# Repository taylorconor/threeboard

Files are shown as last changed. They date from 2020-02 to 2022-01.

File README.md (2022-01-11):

# threeboard

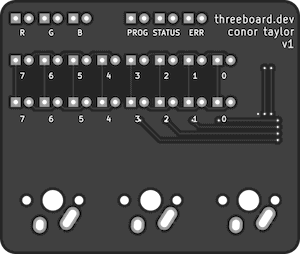
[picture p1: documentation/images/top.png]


threeboard is a fully-functional open source and open hardware mechanical USB computer keyboard with only three keys. It supports multiple programmable layers, and achieves the same functionality as a full-sized keyboard. Its firmware and hardware are built completely from scratch and are extensively documented.

Unlike a traditional keyboard, characters don't show up on the screen after each keypress, because there aren't enough keys. Instead, combinations of the three keys are used to specify key and modifier codes on two built-in 8-bit LED binary indicators. This can then be sent to the host computer as USB keycodes. The multiple layers allow users to program macros into the threeboard’s storage for quick retrieval. All functionality is documented in the [threeboard user manual](documentation/threeboard/threeboard_user_manual.md).

## Motivation
The main goal of the threeboard project is to build a relatively easy to understand, readable, self-contained and well-documented embedded software and hardware project. The threeboard is built from scratch, with no external dependencies. This means that all components, from the USB stack to the PCB hardware designs, are written from the ground up and are all contained in this repository.

The threeboard project is extensively documented: within the firmware itself as comments, in this set of detailed markdown documents, and in a [PDF design document](documentation/threeboard_design_doc.pdf). The primary design goal of the C++ firmware code is readability, to enable as many people to read and learn from it as possible, regardless of background. It's well tested, including end-to-end integration tests which execute tests against the firmware in a hardware simulator to emulate the physical hardware.

## How to try it out

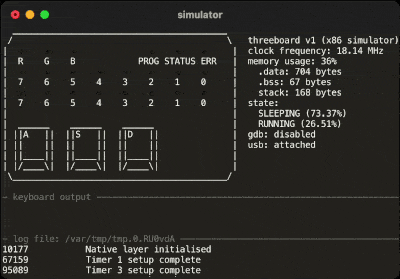
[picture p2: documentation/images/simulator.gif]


The threeboard project includes a terminal-based graphical firmware simulator capable of simulating the entire functionality of the threeboard. You can build and run the simulator yourself by reading the [simulator build instructions](documentation/threeboard/simulator_build_instructions.md). The simulator is built on top of the [simavr](https://github.com/buserror/simavr) AVR simulator, and runs the exact same firmware file that gets flashed to physical hardware. The simulator also allows remote debugging with GDB, so you can step through the threeboard firmware as it's being simulated to learn about it or investigate bugs!

Building your own physical threeboard requires a physical threeboard PCB, soldering tools and components, as well as some knowledge of electronics and soldering. If you're interested in building one, check out the [threeboard hardware build instructions](documentation/threeboard/hardware_build_instructions.md).

## Full documentation
Below are markdown files documenting various aspects of the threeboard project in detail. Full 41-page documentation is available in PDF format in the [threeboard design doc](documentation/threeboard_design_doc.pdf) file.

### Background reading 
[threeboard user manual](documentation/threeboard/threeboard_user_manual.md)  
[How do USB keyboards work?](documentation/threeboard/how_usb_keyboards_work.md) 

### Firmware
[Firmware design](documentation/threeboard/firmware_design.md)  
[Firmware build instructions](documentation/threeboard/firmware_build_instructions.md)  
[Simulator user manual & design](documentation/threeboard/simulator_manual_and_design.md)  
[Simulator build instructions](documentation/threeboard/simulator_build_instructions.md)  

### Hardware
[Hardware design](documentation/threeboard/hardware_design.md)  
[Hardware build instructions](documentation/threeboard/hardware_build_instructions.md)  
[Component list](documentation/threeboard/component_list.md)

Hardware designs are licensed under [CERN-OHL-P](hardware/LICENSE.txt), the firmware is licensed under [GPLv3](firmware/LICENSE.txt), and all documentation under [CC BY-SA 4.0](documentation/threeboard/LICENSE.txt).

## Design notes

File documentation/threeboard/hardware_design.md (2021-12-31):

# threeboard hardware design
## Introduction
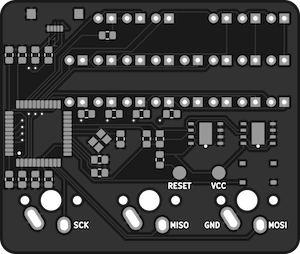
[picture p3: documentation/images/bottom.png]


The threeboard’s hardware is a custom-designed PCB. It includes all electrical components needed to operate the threeboard, as well as test points that can be used to flash new firmware to the MCU. The majority of the components used are surface mounted, with through-holes used for some of the larger components.

This section of the document describes the design goals of the threeboard hardware, the choice of components, and electrical design decisions.

## Hardware design goals
Similar to the design principles of the firmware, the threeboard’s hardware was designed with several goals in mind:

1. Simplicity: This implies that nothing should exist on the PCB that isn’t completely necessary for the operation of the threeboard, and any hardware that can be offloaded to the MCU’s hardware (such as making use of the internal pull-up resistors on certain pins) should be. More importantly, simplicity also applies to the hardware design patterns used; it should be possible to learn from the hardware design of the threeboard with little or no electrical engineering experience.
2. Hand-solderable: It should be possible to solder all components onto the threeboard by hand, with only basic soldering experience. This improves the accessibility of the hardware so it can be easily assembled. For example, all resistor and capacitor pads use an SMD [0805 package size](https://eepower.com/resistor-guide/resistor-standards-and-codes/resistor-sizes-and-packages). Also, the atmega32u4 MCU used by the threeboard is the 10x10mm [TQFP](https://en.wikipedia.org/wiki/Quad_flat_package) package, despite the MCU being offered in a smaller 7x7mm [QFN](https://en.wikipedia.org/wiki/Flat_no-leads_package) package, as it would be more difficult to solder.
3. Inexpensive to manufacture: No unnecessarily expensive components should be used, and no PCB features should be included that are difficult (and expensive) to manufacture unless absolutely necessary. For this reason, the threeboard PCB only uses two layers, minimal [through-hole components](https://en.wikipedia.org/wiki/Through-hole_technology), and as few [via holes](https://en.wikipedia.org/wiki/Via_(electronics)) as possible.

## Design
This section is split into subsections that explain the design of each major hardware component. In many cases, images of the threeboard’s PCB and electrical schematic are used to aid the explanation. In these cases, the image of the relevant piece of the PCB will always be on the left, and the relevant part of the schematic on the right.

### USB


<br clear="right"/>
<br clear="left"/>

The threeboard’s USB hardware is very simple because the atmega32u4 has dedicated USB pins that map directly to the USB connector (pictured in red). The only additional hardware required is specified by the atmega32u4 datasheet, sections 2.2.8 and 2.2.9, which states that the D+ and D- USB data upstream ports should be connected to the USB data connector pins via serial 22Ω resistors (pictured in blue and green).

The complexity of the USB integration lies in the firmware. It’s responsible for keeping track of bus timing, issuing interrupts, and parsing and sending messages. This is discussed in detail in the [firmware design document](firmware_design.md).

### LEDs
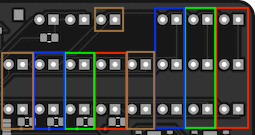
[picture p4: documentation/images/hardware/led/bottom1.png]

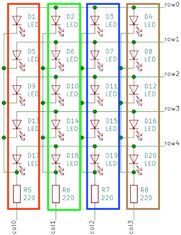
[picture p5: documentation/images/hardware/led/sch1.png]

<br clear="right"/>
<br clear="left"/>

In order to be able to drive 22 LEDs using only 11 MCU pins, the majority of the threeboard’s LEDs are wired in a [multiplexed matrix](https://en.wikipedia.org/wiki/Multiplexed_display), where each individual LED in the matrix is addressable by a row and column value. In this configuration, all of the LEDs can’t be lit at the same time. Instead, each row of LEDs is scanned over in a [raster scanning](https://en.wikipedia.org/wiki/Raster_scan) fashion, and individual LEDs that should be lit are turned on until the next raster scan turns them off.

This row scanning happens within the firmware and is triggered every 2ms by timer interrupt 1. Given that there are 5 rows, a full refresh takes 10ms, which gives the threeboard’s LED indicators a refresh rate of 100Hz, which is well above the threshold for [perceivable flicker by the human eye](https://en.wikipedia.org/wiki/Flicker_fusion_threshold).

Only one LED from a column is lit at any one time, since only one LED from each column exists in a given row. Each column of LEDs is protected by one 220Ω current-limiting resistor in series to restrict the current to each LED to 22mA (calculated using [Ohm’s law](https://en.wikipedia.org/wiki/Ohm%27s_law) given the 5V input voltage from USB).

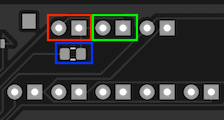
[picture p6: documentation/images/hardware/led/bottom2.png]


<br clear="right"/>
<br clear="left"/>

There are two LEDs on the threeboard that are not included in the multiplexed LED matrix. These are the STATUS (shown in green) and ERR (shown in red) LEDs. They’re configured in parallel with their polarities inverted so that only one can be lit at any given time, and so that only one resistor and two MCU pins are required to drive them. These LEDs are configured in this way for two reasons:

1. 22 LEDs are hard to arrange in a row-column matrix since the number 22 has very few factors. The only configurations would be a 1x22 matrix (which isn’t a matrix) or a 2x11 matrix (which doesn’t reduce the use of LEDs or pins very much). So it’s more economical to put 20 LEDs in a 5x4 matrix and the remaining two in a standalone pair.
2. It’s beneficial when reporting errors or debugging issues with the firmware on the physical board (rather than the simulator) to have some LEDs which can be decoupled from the raster scanning loop. This means that if there are firmware issues with the loop logic, or issues with the MCU’s timer configuration, the STATUS or ERR LEDs can be lit independently of the matrix to help with debugging or surfacing errors.

### Mechanical key switches

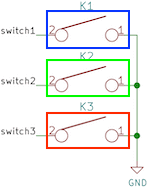
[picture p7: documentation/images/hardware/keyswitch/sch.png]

<br clear="right"/>
<br clear="left"/>

The threeboard uses [Cherry MX](https://deskthority.net/wiki/Cherry_MX) SPST-NO ([single pole, single throw, normally open](https://en.wikipedia.org/wiki/Switch#Contact_terminology)) mechanical switches for its physical key switches. The [bounce time](https://en.wikipedia.org/wiki/Switch#Contact_bounce) of these switches differs depending on the type of switch and the date of manufacture, but it’s safe to assume that it will be below 5ms. Most modern Cherry MX key switches have a 1ms bounce time.

These switches are wired directly to ground, which means they are configured to be [active low](https://en.wikipedia.org/wiki/Logic_level#Active_state); when pressed, they connect their MCU pin to ground. To avoid the situation where an unpressed switch leaves its corresponding MCU pin floating, each switch defaults to high using a [pull-up resistor](https://en.wikipedia.org/wiki/Pull-up_resistor). The atmega32u4 includes internal pull-up resistors on a number of its pin ports, so all three switches are wired to pins on PORTB which includes internal pull-up resistors as specified by the atmega32u4 datasheet, section 2.2.3, with typical resistances of 20-50kΩ.

The MCU pins used for the key switches were chosen carefully to correspond to the pins used for SCK (shown in red), MISO (shown in green), and MOSI (shown in blue) of the atmega32u4’s [SPI interface](https://en.wikipedia.org/wiki/Serial_Peripheral_Interface). These pins are necessary when flashing new firmware onto the MCU using SPI, and so wiring them to the legs of the key switches removes the need for adding dedicated testing pads to connect these pins to an SPI programmer during flashing.

### External EEPROMs
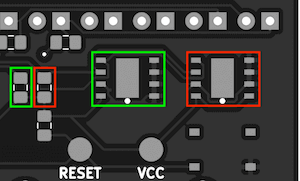
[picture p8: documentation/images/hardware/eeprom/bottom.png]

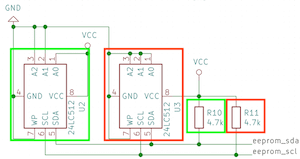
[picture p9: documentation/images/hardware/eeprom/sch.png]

<br clear="right"/>
<br clear="left"/>

The threeboard contains two external 512 kbit EEPROM devices. These devices communicate with the MCU using its 2-wire serial interface (the [I2C protocol](https://en.wikipedia.org/wiki/I%C2%B2C)). The atmega32u4 MCU has built-in hardware support for this interface, with a dedicated data pin (SDA) and clock pin (SCL), which collectively form the TWI (two-wire interface) bus. This interface is described in detail in the atmega32u4 datasheet, section 20.

The EEPROM devices can both be connected in parallel to these pins, as the I2C protocol uses 7-bit addresses, allowing for up to 128 devices on the same bus. Two 4.7kΩ pull-up resistors are used to pull each bus line high when not driven low by the [open-drain](https://en.wikipedia.org/wiki/Open_collector) interface, as mentioned in the atmega32u4 datasheet, section 20.2: _The only external hardware needed to implement the bus is a single pull-up resistor for each of the TWI bus lines_.

### External quartz crystal clock
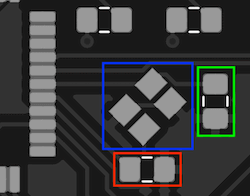
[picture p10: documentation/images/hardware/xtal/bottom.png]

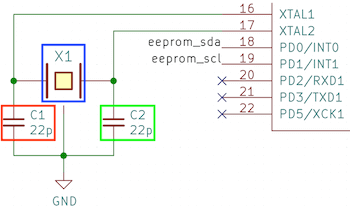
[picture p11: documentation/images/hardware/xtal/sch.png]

<br clear="right"/>
<br clear="left"/>

The threeboard includes a 16MHz quartz crystal oscillator (shown above in blue) as a clock source to the MCU. The MCU contains dedicated hardware pins for use with the external clock (XTAL1 and XTAL2), and the atmega32u4 datasheet, section 6.3, recommends the crystal to be wired as shown in the diagram above, with external capacitors within a 12pF - 22pF range (shown in red and green).

### Decoupling capacitors
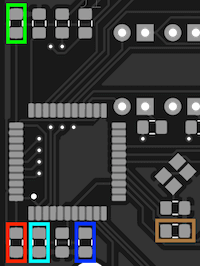
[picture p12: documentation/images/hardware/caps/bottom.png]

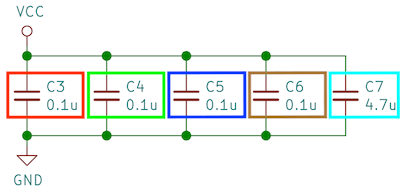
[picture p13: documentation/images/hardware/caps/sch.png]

<br clear="right"/>
<br clear="left"/>

[Decoupling capacitors](https://en.wikipedia.org/wiki/Decoupling_capacitor) are positioned close to each VCC-connected pin on the MCU, to reduce the effect of voltage spikes and drops from the USB power supply. They are also necessary to facilitate instantaneous current increases that may be required by the MCU, as various actions performed by the MCU may have different current requirements.

### MCU
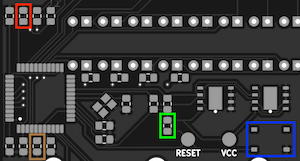
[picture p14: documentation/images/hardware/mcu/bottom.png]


<br clear="right"/>
<br clear="left"/>

The threeboard includes a reset push button to help flash firmware to the MCU during development. The reset switch (shown above in blue) is connected to the RESET pin in the MCU, pulled up to VCC with a 10kΩ pull-up resistor (shown in green). Additionally, the HWB pin is forced low to instruct the MCU to execute the USB bootloader on reset, which allows flashing new firmware on reset. To force it low, it’s tied to ground using a 10kΩ pull-down resistor (shown in red) to prevent the pin from floating.

As specified in the atmega32u4 datasheet, section 2.2.12, the UCap pin must be connected to a 1μF capacitor to regulate the USB output supply voltage.

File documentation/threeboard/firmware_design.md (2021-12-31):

# threeboard firmware design

## Introduction
The threeboard’s firmware has two main functions. The first is to configure and interface with each hardware component on the threeboard (such as LEDs, EEPROMs and USB) according to their respective specifications. The second is to provide user-facing features and functionality to the threeboard as described in the [threeboard user manual](threeboard_user_manual.md).

## Constraints
The threeboard uses an [atmega32u4](https://www.microchip.com/wwwproducts/en/ATmega32u4) microcontroller (MCU), a low-power 8-bit [microcontroller](https://en.wikipedia.org/wiki/Microcontroller) based on the [AVR](https://en.wikipedia.org/wiki/AVR_microcontrollers) enhanced [RISC architecture](https://en.wikipedia.org/wiki/Reduced_instruction_set_computer). Firmware code compiled for this MCU uses the [Atmel AVR instruction set](https://en.wikipedia.org/wiki/Atmel_AVR_instruction_set).

The MCU itself has the following relevant features:

- 8-bit AVR architecture.
- 16MHz maximum frequency at 4.5V.
- 32KB flash-based program memory.
- 2.5KB SRAM.
- 1KB internal EEPROM.
- USB controller hardware support.
- Two 8-bit and two 16-bit timers.
- Byte oriented 2-wire serial interface.

Due to these MCU constraints, this is a bare-metal firmware project. This means that the firmware’s instructions are executed directly on the MCU hardware, without an intervening operating system.

As a result of the lack of operating system, [hardware MMU](https://en.wikipedia.org/wiki/Memory_management_unit), and the severely restricted RAM size, the firmware does not perform any dynamic memory allocation (i.e. no heap allocation). All memory allocation is stack-based.

It’s important to mention that there is no official C++ standard library support for AVR targets. Therefore targets compiled with the AVR C++ compiler, [avr-gcc](https://gcc.gnu.org/wiki/avr-gcc), will not link against libstdc++. All firmware code in the threeboard project cannot use any C++ standard library functions or headers.

## Design principles
The threeboard firmware was designed with several core principles in mind. These are listed below, along with the reasoning for their inclusion:

1. Readability: This is the primary design principle of the firmware. The C++ source itself should be clear, consistent, and well documented. It should be possible for anyone with passable C/C++ knowledge and no embedded programming knowledge to read it and learn from it.
  - Reasoning: Source code with consistent style reduces unnecessary mental load when reading the code, as the code style is predictable. As many people as possible should be able to read and learn from this project, regardless of engineering background. Reducing readability friction helps achieve this goal.
2. Modularity: There should be a clear separation of concerns between different modules of the code, and no interdependence. Modules that need to affect change on other modules should do so via delegation.
  - Reasoning: It’s hard to determine if a class fulfils its responsibilities if it has multiple distinct responsibilities, and it’s hard to guarantee separation of concerns when this mix of responsibilities inevitably leads to reduced encapsulation. Reduced encapsulation causes [dependency hell](https://en.wikipedia.org/wiki/Dependency_hell), which makes code hard to maintain and greatly reduces readability by making the control flow difficult to follow.
3. Testability: Each module must be testable in isolation. All external module dependencies should be abstract to enable mocking and deterministic testing.
  - Reasoning: Untested code should be assumed to have bugs, so full test coverage is essential. Making classes easier to test in isolation makes it easier to write concise test cases.

## Toolchain
The atmega32u4 chip manufacturer (Atmel / Microchip) provides a [toolchain](https://en.wikipedia.org/wiki/Toolchain) for use with AVR development, in particular [avr-gcc](https://www.microchip.com/en-us/development-tools-tools-and-software/gcc-compilers-avr-and-arm), a GCC compiler for AVR. This toolchain works out of the box for all stages of firmware development.

The threeboard firmware is built with [Bazel](http://bazel.build/). Bazel was chosen over more traditional build systems like CMake because it has the following useful properties:

1. Explicit dependencies: All dependencies on a [translation unit](https://en.wikipedia.org/wiki/Translation_unit_(programming)) must be explicitly defined in the Bazel BUILD file, and each translation unit is compiled in a sandbox environment that only has access to the dependencies that have been explicitly declared. This makes it impossible to introduce implicit project dependencies. Additionally, Bazel fails the build if it detects a dependency cycle.
2. Customisable target declarations: Targets can be used to produce multiple object files, compiled with different compiler settings and even with different compilers. This allows compatible modules to be compiled for both x86 and AVR, depending on the context in which it’s being compiled.

Bazel has no pre-existing support for the AVR toolchain, so support had to be added for this project. The [avr-bazel](https://github.com/taylorconor/avr-bazel) repository was built especially for the threeboard project. It contains some special Bazel build rules to produce joint x86 and AVR build targets. This allows defining a single target definition per BUILD file to produce libraries for both targets, to avoid having to double-declare them.

## Architecture
### Overview
The architecture of the threeboard firmware can roughly be grouped into three categories of modules/classes:

1. Business logic modules: These codify the functionality of the firmware, and coordinate other modules to execute this functionality.
2. Native-interacting modules: Generally serve the purpose of configuring and controlling a single hardware element, such as LEDs or USB.
3. Pure AVR modules: Modules that can only be compiled for the AVR architecture, i.e. those that interact directly with hardware.

<p align="center">
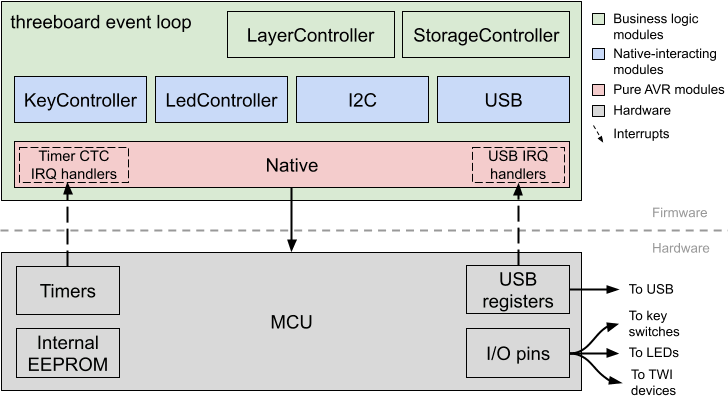
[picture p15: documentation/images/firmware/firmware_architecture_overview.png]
  
</p>

Everything except pure AVR modules target both AVR and x86 targets, which enables tests to run on x86 development hosts. These modules don’t depend on any avr-libc headers, so all of their interactions with hardware are proxied through the firmware’s `Native` interface, which exposes an API to interact with hardware. The interface itself does not depend on avr-libc, so non-pure modules can depend on it. When the firmware is compiled to be run on an AVR host or simulator, an avr-libc dependent `Native` implementation (`NativeImpl`) is used.

### Event loop
The core of the threeboard firmware is a simple event loop; a design pattern that waits for and dispatches events to relevant modules when they arrive. The event loop is a never-ending loop that runs as long as the firmware is running (i.e. as long as the device has power).

The responsibilities of the different timers used, and the encapsulation afforded by the event loop is summarised in the diagram below:
<p align="center">
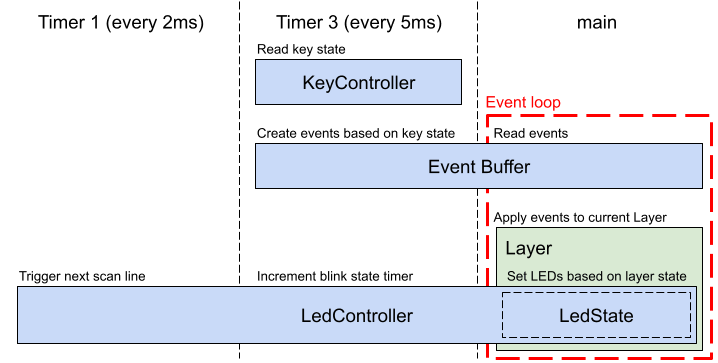
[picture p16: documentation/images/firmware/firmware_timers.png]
  
</p>

Each event loop iteration is triggered by an [interrupt](https://en.wikipedia.org/wiki/Interrupt). Two timer-based interrupts are used in the threeboard firmware: Timer 1 in CTC mode is configured to produce a software interrupt every 2ms, and is used to refresh the next LED scan line; Timer 3, also in CTC mode, is configured to produce a software interrupt every 5ms, used mainly to poll the key switches and produce events on the event buffer if necessary. Running timer 3 slower and separately from timer 1 allows us to avoid debouncing the [Cherry MX](https://en.wikipedia.org/wiki/Cherry_(company)#Cherry_MX_switches_in_consumer_keyboards) key switches in software.

The purpose of the event loop is to receive and process all keypress events according to the actions defined in the current `Layer` of the threeboard. Each `Layer` instance encapsulates all business logic relating to inputs and actions for a given layer, so this doesn’t need to happen in a long list of if/else statements within the main program loop.

```c++
void Threeboard::RunEventLoop() {
  // USB setup and configuration.
  ...

  // Main event loop.
  while (true) {
    // Atomically check for new keyboard events, and either handle them or
    // sleep the CPU until the next interrupt.
    native_->DisableInterrupts();
    if (!event_buffer_->HasEvent()) {
      // Sleep the CPU until another interrupt fires.
      native_->EnableCpuSleep();
      native_->EnableInterrupts();
      native_->SleepCpu();
      native_->DisableCpuSleep();
    } else {
      if (event_buffer_->HasKeypressEvent()) {
        layer_controller_.HandleEvent(event_buffer_->GetKeypressEvent());
      }
      // Re-enable interrupts after handling the event.
      native_->EnableInterrupts();
    }
  }
}
```

The sleep enabled bit is set before each sleep and cleared after each sleep, as recommended in the atmega32u4 datasheet (section 7.9.1): _it is recommended to write the Sleep Enable (SE) bit to one just before the execution of the SLEEP instruction and to clear it immediately after waking up_.

When finished handling events in the event buffer, the event loop puts the MCU into idle mode. In this mode, the CPU clock is stopped, but the clock powering the MCU’s timers continues. The MCU is brought out of idle mode when the timer produces a software interrupt. The purpose of the event loop can therefore be thought of as to efficiently facilitate delegation between each module in the threeboard, without requiring [busy-waiting](https://en.wikipedia.org/wiki/Busy_waiting).

### Delegation
The threeboard makes extensive use of [delegation](https://en.wikipedia.org/wiki/Delegation_pattern) to allow different modules in the firmware to communicate with each other without introducing circular dependencies.

In certain situations, two-way function calling between modules is necessary. The first of such situations this document will explain is the `LayerController`. It needs to be able to provide events to individual `Layer`s to be handled. But some of these events may trigger an action that affects the `LayerController` itself, such as a keypress event that triggers the threeboard to switch layers. In this case, the current `Layer` uses the `LayerControllerDelegate` to call `SwitchToLayer()` on the `LayerController`, without having to explicitly depend on the `LayerController`:
<p align="center">
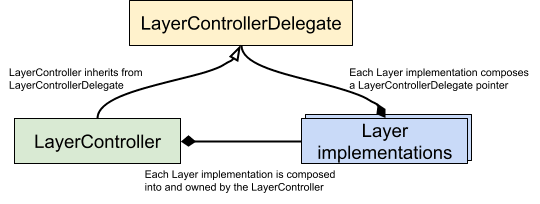
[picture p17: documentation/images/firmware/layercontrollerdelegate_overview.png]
  
</p>
<br>
<p align="center">
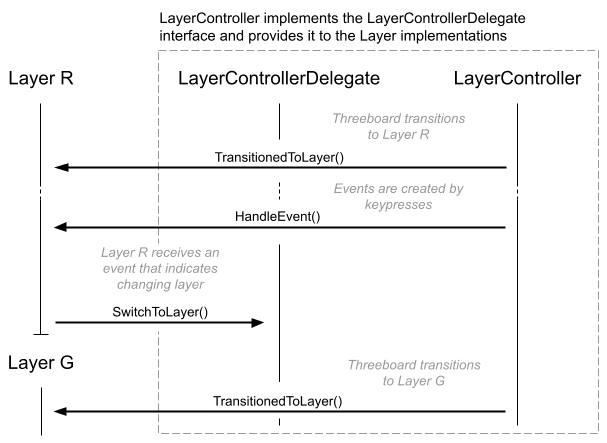
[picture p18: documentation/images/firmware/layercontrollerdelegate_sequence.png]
  
</p>

The `Threeboard` class event loop receives timer interrupts in a similar fashion to the `LayerController`. In this case, the `Native` implementation is not owned by the `Threeboard` class, instead it’s passed in as part of the bootstrapping process. This allows `Native`-specific timers to call functions in the `Threeboard` class (via the `TimerInterruptHandlerDelegate`) without introducing a circular dependency:
<p align="center">
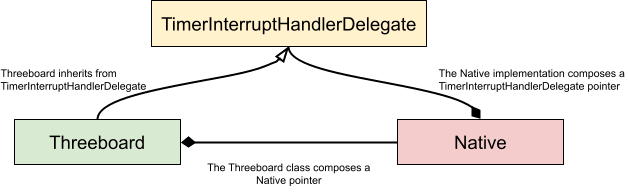
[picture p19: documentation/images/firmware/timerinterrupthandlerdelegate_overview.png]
  
</p>

### LED indicators
The LED indicators on the threeboard are vital to understanding the current state of the threeboard. The hardware is equipped with 22 single-colour LEDs. These are arranged as follows:
<p align="center">
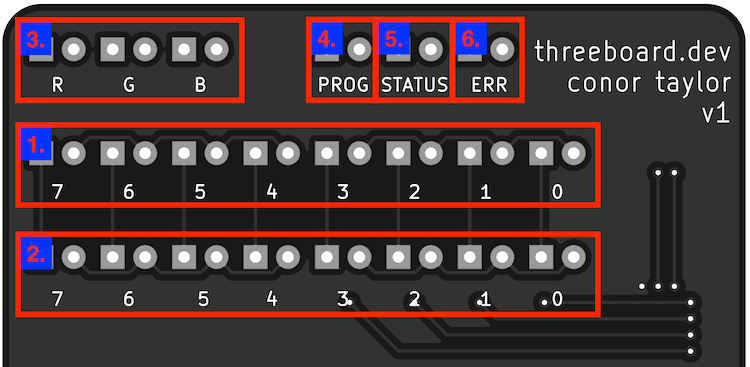
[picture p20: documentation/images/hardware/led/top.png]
  
</p>

1. 8 LEDs to display the binary value of bank_0 (1 byte).
2. 8 LEDs to display the binary value of bank_1 (1 byte).
3. 3 LEDs to display the current layer, which is one of R, G or B (or DFLT if no LEDs are lit).
4. 1 PROG LED to identify when the device is in PROG mode.
5. 1 ERR LED to indicate an error.
6. 1 STATUS LED to provide context-specific status information.

The hardware-specific details of these LEDs, such as their wiring and tolerance, is described in the [hardware design](hardware_design.md) document.

The LED indicator lights are all controlled by the `LedController`. This class is responsible for maintaining the state of the raster scan and outputting the `LedState` (a simple class for storing the state of each LED) to hardware. Its interface is very simple:

```c++
class LedController {
 public:
  explicit LedController(native::Native *native);

  // Handles rendering of the next scan row. Called by the timer interrupt
  // handler every 2ms.
  void ScanNextLine();

  // Handles timing of LED blinking. Called by the timer interrupt handler every
  // 5ms.
  void UpdateBlinkStatus();

  // state_ is guaranteed to live for the entire lifetime of the firmware.
  LedState *GetLedState() { return &state_; }
};
```

As discussed in the hardware section, the LEDs on the threeboard are arranged in a 5 row, 4 column matrix. When the `ScanNextLine()` function is called, the active LEDs in the next row of the matrix are lit, and all other LEDs are turned off. `ScanNextLine()` is called every 2ms by timer 1, which provides a 100Hz refresh rate on the threeboard’s LEDs.

The `LedController` is also responsible for maintaining the timing of blinking LEDs. `UpdateBlinkStatus()` increments an 8-bit blink timer. Two blink states are supported by the threeboard: `LedState::BLINK` repeatedly flashes the selected LED, and `LedState::PULSE` flashes the LED once and then reverts to `LedState::OFF`.

### USB stack
The threeboard contains a full USB device implementation. The threeboard presents itself to hosts as a [USB version 2.0](https://www.usb.org/document-library/usb-20-specification) keyboard [HID device](https://en.wikipedia.org/wiki/USB_human_interface_device_class), complies with HID [version 1.11](https://www.usb.org/document-library/device-class-definition-hid-111), and passes [USB CV test specification 0.72](https://www.usb.org/document-library/usb-31-command-verifier-compliance-test-specification-version-072).

The USB protocol is extremely complex and so is not explained in this document. To learn how USB works, I recommend the [USB in a NutShell](https://www.beyondlogic.org/usbnutshell/usb1.shtml) series of articles, and to use the [USB 2.0 specification](https://www.usb.org/document-library/usb-20-specification) as a reference. This section will summarise the design and architecture of the threeboard’s USB stack without going into any detail about the USB standard.

In the threeboard firmware, the USB stack is abstracted behind a minimal interface:

```c++
class Usb {
 public:
  // Setup the USB hardware to begin connection to the host. This method blocks
  // until the device hardware is correctly set up. If this method returns false
  // it means setup was halted by an error issued via the ErrorHandlerDelegate
  // and is in an undefined state.
  virtual bool Setup() = 0;

  // Returns true if the HID device configuration has completed successfully.
  virtual bool HasConfigured() = 0;

  // Send the provided key and modifier code to the host device. Returns false
  // if an error occurred during sending.
  virtual bool SendKeypress(uint8_t key, uint8_t mod) = 0;
};
```
The `UsbImpl` class is the concrete implementation of the `Usb` interface and interacts with the MCU’s USB registers and functionality using the `Native` interface. Failure to set up correctly via `Usb::Setup()`, and subsequent failure to configure within the first 50 USB frames (50ms) using `Usb::HasConfigured()` will stall the threeboard’s firmware startup logic, and enter an error state that continuously attempts to establish a connection to the host over USB.

USB setup begins with the firmware configuring the MCU to enable an electrical USB connection with the host device, as defined in the atmega32u4 datasheet, section 21.12. For example, the MCU contains [phase-locked loop (PLL)](https://en.wikipedia.org/wiki/Phase-locked_loop) hardware. When enabled, this can convert the external 16MHz clock signal to a 12MHz clock needed for the USB controller hardware in the MCU when configured in full-speed mode (atmega32u4 datasheet, section 21.2):

```c++
bool UsbImpl::Setup() {
  // Enable the USB pad regulator (which uses the external 1uF UCap).
  native_->SetUHWCON(1 << native::UVREGE);
  // Enable USB and freeze the clock.
  native_->SetUSBCON((1 << native::USBE) | (1 << native::FRZCLK));
  // PLL Control and Status Register. Configure the prescaler for the 16MHz
  // clock, and enable the PLL.
  native_->SetPLLCSR((1 << native::PINDIV) | (1 << native::PLLE));
  // Busy loop to wait for the PLL to lock to the 16MHz reference clock.
  WAIT_OR_RETURN(!(native_->GetPLLCSR() & (1 << native::PLOCK)), UINT16_MAX,
                 "Failed to lock PLL during USB setup");
  // Enable USB and the VBUS pad.
  native_->SetUSBCON((1 << native::USBE) | (1 << native::OTGPADE));
  // Configure USB general interrupts (handled by the USB_GEN_vect routine). We
  // want to interrupt on start of frame (SOFE), and also on end of reset
  // (EORSTE).
  native_->SetUDIEN((1 << native::EORSTE) | (1 << native::SOFE));
  // Connect internal pull-up attach resistor. This must be the final step in
  // the setup process because it indicates that the device is now ready.
  native_->SetUDCON(native_->GetUDCON() & ~(1 << native::DETACH));
  return true;
}
```

Once the device hardware is correctly set up, the threeboard informs the host of its capabilities using a series of [descriptors](https://www.beyondlogic.org/usbnutshell/usb5.shtml). The device descriptor specifies fundamental information about the device (including which USB standard it supports and its unique ID). Other important descriptors follow, which inform the host of the class of the device; in this case a [HID-compatible](https://en.wikipedia.org/wiki/USB_human_interface_device_class) keyboard device.

All USB communication is host-centric. This means that no data can be sent from the device to the host unless the host requests it. For this reason, the threeboard’s USB stack is interrupt-driven. The atmega32u4 provides hardware support to issue software interrupts identifying the beginning of a USB message frame, which is the USB host potentially requesting information from the device, such as keypress data or specific descriptor information, for example, to determine what strings to display as the name of the USB device on the host computer. The threeboard’s USB interrupts are facilitated by the `UsbInterruptHandlerDelegate`, which allows the Native layer to pass messages to the USB stack without dependency issues, as discussed in the [delegation](#delegation) section.

Once the USB stack has correctly configured, the threeboard’s firmware enters the [event loop](#event-loop). Individual layers can decide when to flush their state to the USB host (using `Layer::FlushToHost()`) based on their received keypress events. This triggers one or more `UsbImpl::SendKeypress()` calls, which attempts to send an individual key presses to the host over USB:

```c++
bool UsbImpl::SendKeypress() {
  uint8_t intr_state = native_->GetSREG();
  native_->DisableInterrupts();
  uint8_t initial_frame_num = native_->GetUDFNUML();
  while (true) {
    native_->SetUENUM(kKeyboardEndpoint);
    native_->EnableInterrupts();
    // Check if we're allowed to push data into the FIFO. If we are, we can
    // immediately break and begin transmitting.
    if (native_->GetUEINTX() & (1 << native::RWAL)) {
      break;
    }
    native_->SetSREG(intr_state);
    // Ensure the device is still configured.
    RETURN_IF_ERROR(hid_state_.configuration);
    // Only continue polling RWAL for 50 frames (50ms on our full-speed bus).
    if ((native_->GetUDFNUML() - initial_frame_num) >= kFrameTimeout) {
      return false;
    }
    intr_state = native_->GetSREG();
    native_->DisableInterrupts();
  }

  SendHidState();
  native_->SetSREG(intr_state);
  return true;
}
```

### Storage
The threeboard is equipped with three [EEPROM](https://en.wikipedia.org/wiki/EEPROM) storage devices: One 1 KB EEPROM built into the atmega32u4 MCU, and two 512 kbit external EEPROMs connected to the MCU via the MCU’s TWI (two-wire interface) bus. These communicate with the MCU using the [I2C protocol](https://en.wikipedia.org/wiki/I%C2%B2C).

In firmware, the data in these storage devices are all controlled on a high level by the `StorageController`, which is used by each of the programmable `Layer`s for their respective storage needs. The `StorageController` uses the I2C module to abstract away the interfacing logic between the MCU and relevant EEPROMs.

The internal 1 KB EEPROM is used to store all of the character shortcuts for Layer `R`, in addition to the lengths of each of the shortcuts stored in layers G and B. The first external EEPROM (referred to as EEPROM 0) stores each of the word shortcuts for Layer `G`, along with the first 120 blob shortcuts for Layer `B`. The second external EEPROM (EEPROM 1) stores the remaining 128 shortcuts Layer `B` shortcuts.

Because Layer `B` (the blob shortcut layer) allows storage of per-character USB modifier codes, these must be stored in EEPROM along with each keycode. This means that each 256-character blob shortcut requires 512 bytes to store.

The storage layout is visualised below:
<p align="center">
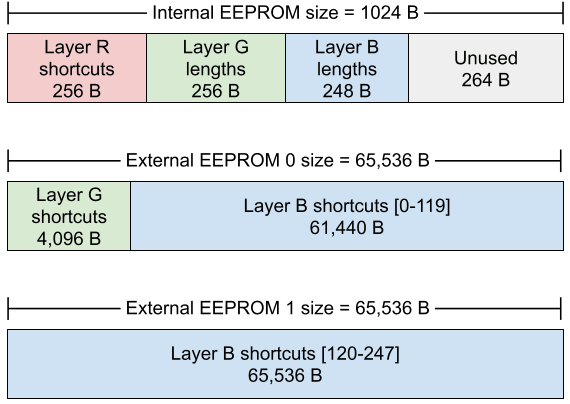
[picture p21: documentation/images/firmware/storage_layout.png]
  
</p>

## Style guide
A number of high-level style decisions have been made to make the code as uniform and as readable as possible:

1. All source files must be formatted with [clang-format](https://clang.llvm.org/docs/ClangFormat.html) using the included `.clang-format` config file.
2. Class and member function names use `UpperCamelCase` style. Member variables use `trailing_snake_case_` style, and local variables use `regular_snake_case`.
3. Raw pointers should be used to inject dependencies or for output parameters. They must be non-owning and non-null. Raw pointers are used over references purely because they exhibit [pointer semantics](https://stackoverflow.com/questions/166033/what-do-value-semantics-and-pointer-semantics-mean), making interactions with them more explicit. It follows that non-const references are not allowed.
4. Single-argument constructors must be marked `explicit`, or commented to indicate why implicit construction is favourable.
5. Relative include paths are not allowed.
6. Every class definition should have a comment explaining the function of the class. Each method and member declaration should also have comments unless trivial.

## Testing strategy
The threeboard firmware is tested using three different testing levels:

1. Unit tests: Simple test cases for individual classes. These tests generally [mock](https://en.wikipedia.org/wiki/Mock_object) all of the dependencies of the class under test, and set expectations on how the mocks will be used by the class. The threeboard firmware is written with this testability in mind, and most classes take pointers to abstract classes as their dependencies in their constructors. These abstract classes generally have two implementations: a ‘real’ implementation and a mock. Mock instances will be passed to the class during testing.
2. Simulated integration tests: This test suite uses the full simulated firmware (using the [threeboard simulator](simulator_user_manual.md) to run tests against the entire threeboard firmware end-to-end. These tests apply a sequence of keypresses to the simulated firmware and make expectations on USB interactions, LED states and character output.
3. Simulated property tests: The property test suite uses a similar setup to the integration tests in that tests are run end-to-end on the simulated threeboard firmware. This test executes keypresses on the simulator, and also on a threeboard model, used to represent the desired behavior of the system under test. The test generates a random sequence of 25,000 input keypresses, executes them one at a time, and asserts the property that the simulator and the threeboard model must share the same state before and after the keypress is processed.

All tests run within the [Google Test framework](https://github.com/google/googletest) for testing and mocking.

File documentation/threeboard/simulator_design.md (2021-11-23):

# threeboard simulator design

## Introduction
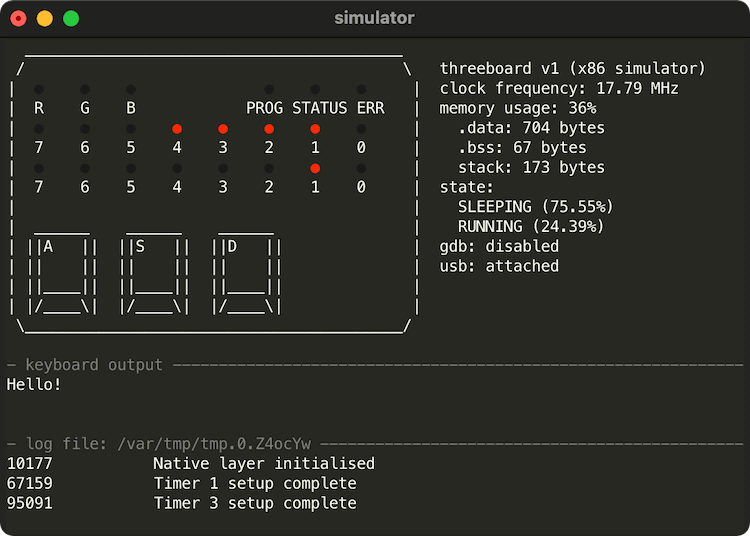
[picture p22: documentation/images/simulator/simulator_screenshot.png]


Debugging embedded firmware is generally difficult and slow, as target hardware limitations usually prevent meaningful logging or the ability to connect a debugger and use real-time software breakpoints. Developing embedded firmware without access to a simulator means all firmware needs to be flashed and run on the target hardware, which becomes cumbersome.

For these reasons, the threeboard project includes a fully functional terminal-based threeboard simulator for Linux and macOS, built on top of the [simavr project](https://github.com/buserror/simavr). The simulator enables running and debugging of the threeboard AVR firmware on the same x86 platform used for development, which greatly improves development speed and makes debugging far easier and more accessible. Most importantly, the firmware being simulated is the same firmware binary that runs on physical hardware: no simulator-specific code paths exist in the firmware, although [UART](https://en.wikipedia.org/wiki/Universal_asynchronous_receiver-transmitter)-based logging is disabled when building for physical hardware.

## Features
The simulator runs a terminal-based graphical emulator of the threeboard hardware, designed to look as similar as possible to the actual threeboard hardware, with the LEDs and key switches laid out almost identically.

Other simulator features include:

- GDB debugging support: The simulator exposes a [gdbserver](https://en.wikipedia.org/wiki/Gdbserver) to enable debugging of the firmware being simulated. Disabled by default, when enabled (by using the shortcut key `g`) the server runs locally on port 1234.
- Mock USB host: To simulate communication between the threeboard and a USB host (a computer), the simulator includes a mocked USB host which appears to the simulated firmware as a real USB host computer. The firmware will send keypresses over USB to the mocked host just as it would to a real host, and the simulator outputs these keypresses to the simulator UI in the “keyboard output” section of the UI.
- Logging: The threeboard simulator includes a mock data receiver capable of receiving logging information from the simulated threeboard firmware via the simulated hardware’s UART pins. `LOG()` and `LOG_ONCE()` macros in the firmware produce logs that are transmitted to this mock data receiver in the simulator. These macros are only enabled when building the firmware for the simulator, because the threeboard firmware doesn’t correctly initialise the UART pins or clock, it takes advantage of simavr’s UART implementation to transmit data instantaneously from the firmware to the simulator.
- MCU state visualisation: Several high-level states are used by simavr to categorize the MCU’s current operating mode. Examples include `RUNNING`, `SLEEPING` and `CRASHED`. The threeboard simulator includes a visualisation of the amount of time spent in each state while running the simulator, which is useful when trying to optimise power usage or detect infinite or expensive loops in firmware.
- Memory usage indicator: The simulator includes a simple memory usage indicator, which displays both static memory usage (from [`.data`](https://en.wikipedia.org/wiki/Data_segment) and [`.bss`](https://en.wikipedia.org/wiki/.bss) segments) and dynamic memory usage. Since the threeboard hardware constraints forbid dynamic memory allocation, the dynamic memory usage is an indication of stack use.
- Mock LED permanence: The simulator’s terminal-based UI displays the threeboard’s LEDs in red (on) or grey (off). The simulator attempts to emulate the LED matrix permanence property discussed in the [hardware design](hardware_design.md) section, by setting a minimum time an LED may be lit for. This makes the simulated LEDs in the terminal behave as similarly as possible to the real LEDs on the threeboard, and makes it possible to spot timing bugs or other issues with the LEDs raster scanning logic.

## Design

The simulator is effectively a wrapper around [simavr](https://github.com/buserror/simavr), an exceptionally good AVR simulator that supports lots of features of many AVR microcontrollers, and is easy to configure with new MCUs and features. Simavr does most of the difficult work of simulating the firmware: given the threeboard firmware binary file, simavr parses it, determines the properties of the MCU being simulated based on headers in the binary, and can execute the instructions one cycle at a time. It supports interrupts and timing, and has full support for the atmega32u4’s USB controller. 

Events are issued and handled in simavr using [IOCTL calls](https://en.wikipedia.org/wiki/Ioctl). These allow a way of triggering arbitrary functionality and message passing within simavr, which enables its configurability.

The simulator is comprised of several interoperating modules which emulate the properties of different hardware components on the threeboard. Modules are needed for external components (EEPROMs and UART) and for emulating a USB host machine to send keypress information.

<p align="center">
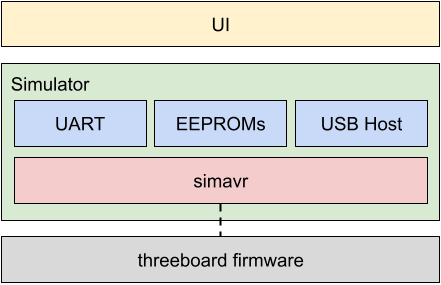
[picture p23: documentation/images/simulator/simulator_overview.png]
  
</p>

The UI module is responsible for translating the state of the simulator into a visualisation of the result of that state on the threeboard’s hardware, in particular its LEDs. It’s a purely [text-based user interface](https://en.wikipedia.org/wiki/Text-based_user_interface) implemented using [ncurses](https://en.wikipedia.org/wiki/Ncurses). The static outlines and frames of the UI are drawn once, and the dynamic components are redrawn at a rate of 200Hz.

The USB host component is far from a standards-compliant host implementation. It contains the least amount of logic required to make the threeboard firmware believe it is communicating with a real USB host. It simply polls the USB controller in firmware by triggering USB general interrupts which cause the firmware to periodically send its HID state over USB.

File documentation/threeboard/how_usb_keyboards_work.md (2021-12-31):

# How do USB keyboards work?

This section describes on a very high level how most USB 2.0 keyboards interact with their connected computer (the host) via USB, from connection to device setup to keypress handling. It is not intended to be a definitive explanation, just an overview. For more detailed explanations, I recommend the [USB in a NutShell](https://www.beyondlogic.org/usbnutshell/usb1.shtml) series of articles, parts of which have been included in this section. The full 650 page [USB 2.0 specification](https://www.usb.org/document-library/usb-20-specification) can also be useful as a reference.

## Overview
USB stands for Universal Serial Bus, a name which identifies the three main properties of USB:

- Universal: Designed to be able to support any kind of peripheral device.
- Serial: There is only one stream of data being sent over the wire at a time (as opposed to a _parallel bus_ that supports multiple concurrent streams).
- Bus: A network topology in which all of the various devices in the network are connected to a single shared data line.

USB 2.0 is a single host, multiple device protocol. There must be exactly one host device coordinating all communication on the wire. In most cases, the host is a PC or laptop, and the devices are any connected peripherals like keyboards, mice, webcams etc. Each device is assigned a unique 7-bit address when it first connects to the host (a process known as _device enumeration_), so up to 127 devices can be connected to a single USB bus at a time. Most computers will have multiple USB busses, e.g. one per external USB port.

The USB protocol defines several data transfer modes. Which mode a device chooses depends on the intended use of the device:

- Control: Used for device enumeration and setup, for example for informing the host about the name and manufacturer of the device, and for selecting which other mode the device will use as its main mode of operation.
- Interrupt: Non-periodic, low-latency, low data throughput communication. An Interrupt request is queued by the device until the host polls it to ask for data. This is typically used for rare but time-sensitive events, such as mouse clicks or keyboard keypresses.
- Bulk: Used for large, potentially bursty data transfers. Bulk transfers provide error correction on the payload, and error detection/re-transmission mechanisms, ensuring data is transmitted and received without error. This transfer mode is commonly used in USB memory sticks.
- Isochronous: This allows a device to reserve a defined amount of bandwidth with guaranteed latency, and perform periodic transfers. This is useful in audio or video applications where congestion may cause loss of data or framerate, such as webcams.

USB keyboards spend most of their time transferring data in the interrupt mode because the host needs to react quickly to keypress events to avoid perceivable lag.

The USB protocol identifies the functionality of a device using _device classes_, defined by a class code sent to the host. This allows the host to e.g. load drivers for the device and to support new devices from different manufacturers, making USB universal. The USB standard specifies some standard device classes, but manufacturers can implement their own using the wildcard “vendor-specific” class type. One standard-defined class is the [Human Interface Device (HID)](https://en.wikipedia.org/wiki/USB_human_interface_device_class) class; this class includes devices intended to be used by humans to interact with a computer, such as keyboards and mice. The threeboard implements this USB HID class to identify itself as a keyboard.

## Connector wiring
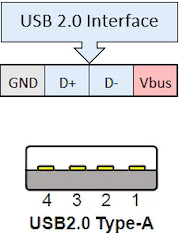
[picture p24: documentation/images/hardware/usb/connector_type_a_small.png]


The wiring of a USB 2.0-only connector (i.e. a connector capable of up to a 480 Mbit/s “high speed” data rate) is quite simple, with only 4 pins needed:

- V<sub>BUS</sub>: 5V power line.
- D-: Part of differential pair data line.
- D+: Part of differential pair data line.
- Ground.

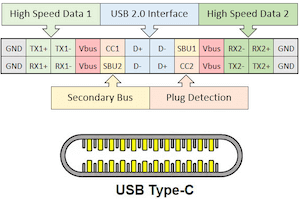
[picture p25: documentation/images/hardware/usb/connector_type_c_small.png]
USB 3.0 requires an additional 5 pins for a total of 9, but keeps the same connector types. Sometimes these have blue inserts to indicate USB 3.0 compatibility, but retain backwards compatibility with USB 2.0. Type A connectors are only used on hosts (e.g. computers), and Type B connectors are only used on devices (e.g. phones, keyboards), but they have the same wiring and pin configuration. Newer Type C connectors (often called “USB-C”) are omnidirectional and are the only connector type that supports USB 4.0. These connectors are radically different, with 24 pins, but still maintain backwards compatibility with all previous USB standards. This is possible because USB-C contains the 4-pins USB 2.0 configuration as a subset of its 24 pins.

The _differential pair_ data line is an implementation of [differential signalling](https://en.wikipedia.org/wiki/Differential_signalling). Two wires are used but the data line remains serial.

The remainder of this document assumes the USB 2.0 standard. Although as discussed, keyboards implementing USB 2.0 can still have USB-C connectors by using its USB 2.0 subset.

## Hardware and firmware
It’s important to think of a USB keyboard as a computer in its own right. To be able to fully implement the USB protocol, keyboards generally contain a 5V microcontroller with clock speeds up to 80MHz, as much as 100 KB of RAM, and hardware support for the USB protocol. These microcontrollers use RISC instruction sets, such as [ARM](https://en.wikipedia.org/wiki/ARM_architecture) or [AVR](https://en.wikipedia.org/wiki/AVR_microcontrollers). [Firmware](https://en.wikipedia.org/wiki/Firmware) runs on the keyboards microcontroller, implementing everything from checking for keypresses and lighting status LEDs to implementing the USB protocol and communicating with the host. [QMK](https://qmk.fm/) is a popular ARM and AVR-compatible open-source keyboard firmware. The threeboard uses its own custom-built firmware, available in this repository.

## Device enumeration
USB device enumeration is the process where hosts detect, identify and in some cases load drivers for a USB device. This section won’t go into any of the electrical details of how hosts detect when a device has been plugged in, instead it will focus on how devices use the USB protocol to identify themselves to the host. However one important electrical feature of this process is how the host determines the speed of the device; the USB D+ is connected to V<sub>BUS</sub> with a pull-up resistor, indicating full-speed 12 Mbps mode. Connecting USB D- instead would specify the low-speed 1.5 Mbps operating mode.

When a USB device is being enumerated, it cycles through several configuration states: _default_, _addressed_ and _configured_. Once a device has been plugged in and is receiving power from the host, it enters the _default_ state. In this state, it has not even been assigned an address yet. The process from _default_ to _configured_ (i.e. usable) state is visualised below:

<p align="center">
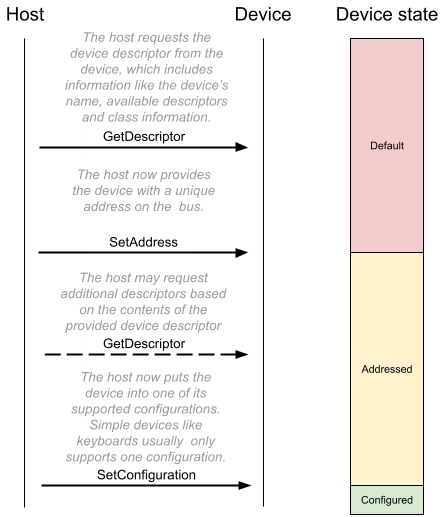
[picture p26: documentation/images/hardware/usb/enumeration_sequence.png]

</p>

The threeboard’s enumeration values (such as its device descriptor and additional HID descriptors) are all specified in [`usb/internal/descriptors.h`](https://github.com/taylorconor/threeboard/blob/master/firmware/src/usb/internal/descriptors.h).

## Sending keypress events
During enumeration, a USB keyboard will have provided an _endpoint descriptor_ to the host. This is used to describe all of the USB _endpoints_ a device supports. Endpoints are essentially isolated data buffers on the USB device, with important properties including a transfer direction (IN, meaning device to host, and OUT, meaning host to device) and a transfer type (control, interrupt, bulk, isochronous). USB devices all must provide at least one _control endpoint_ (endpoint 0), which is the endpoint used during enumeration. Devices may provide multiple additional endpoints e.g. for interrupting the host with keypress data.

USB keyboards may be configured differently depending on their functionality, but in the most basic case (and in the case of the threeboard), a USB keyboard provides only one additional endpoint, an IN endpoint 1, with an interrupt transfer type. The host polls the device as frequently as every 1ms (this polling period is configurable in the endpoint descriptor) to check if the device has an interrupt in its endpoint buffer waiting to be sent to the host. A USB HID-compliant keyboard device will put a _keyboard input report_ message in its IN buffer, which contains up to 6 keypress codes and a modifier code, identifying all of the modifier keys being pressed. The _keyboard input report_ is 8 bytes long and contains one modifier keycode byte, one reserved byte, and 6 keycode bytes. A table mapping these bytes to key codes is defined in section 10 of the [HID usage tables](https://github.com/taylorconor/threeboard/blob/master/documentation/manuals/HID%20usage%20tables.pdf) document.

An example host polling sequence is visualised below:

<p align="center">

</p>

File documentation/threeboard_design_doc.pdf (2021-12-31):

# The threeboard project

## ABOUT

This document describes the design, functionality and architecture of the threeboard project: a fully-functional mechanical USB keyboard with only three keys.

A full copy of the firmware source code, hardware design definitions and collected documentation is available at github.com/taylorconor/threeboard.

Author | Conor Taylor - taylorconor.com
Date | December 2021

## OVERVIEW

threeboard is a fully-functional open source and open hardware mechanical USB computer keyboard with only three keys. It supports multiple programmable layers, and achieves the same functionality as a full-sized keyboard. Its firmware and hardware are built completely from scratch and are extensively documented.

Unlike a traditional keyboard, characters don't show up on the screen after each keypress,
because there aren't enough keys. Instead,
combinations of the three keys are used to specify


key and modifier codes on two built-in 8-bit LED binary indicators. This can then be sent to the host computer as USB keycodes. The multiple layers allow users to program macros into the threeboard’s storage for quick retrieval.

## MOTIVATION

The main goal of the threeboard project is to build a relatively easy to understand, readable, self-contained and well-documented embedded software and hardware project. The threeboard is built from scratch, with no external dependencies. This means that all components, from the USB stack to the PCB hardware designs, are written from the ground up and are all contained in the threeboard git repository.

The threeboard project is extensively documented: within the firmware itself as comments, in a set of detailed markdown documents, and in this design document. The primary design goal of the C++ firmware code is readability, to enable as many people to read and learn from it as possible, regardless of background. It's well tested, including end-to-end integration tests which execute tests against the firmware in a hardware simulator to emulate the physical hardware.

## FUNCTIONALITY

The threeboard uses three keys to select keycodes to send over USB, and also provides three programmable layers to store and retrieve key combinations. The state of the keyboard is visualised using the 22 onboard LED lights, and can only be modified using the three keys. The image below highlights the different features of the device:

1. 3 LEDs indicating the currently selected keyboard layer (R, G and B).
2. 3 status LEDs for indicating the operating status of the threeboard (PROG, STATUS and ERR)
3. Bank0, a binary byte display of 8 LEDs. Used for displaying layer-specific information (e.g. displaying the USB keycode)
4. Bank1, another binary byte display with 8 LEDs. Used for displaying a different byte of layer-specific information (e.g. displaying the USB modifier code).
5. Mechanical key X.
6. Mechanical key Y.
7. Mechanical key Z.

A table mapping USB keycode and modcode bytes to key values are defined in section 10 of the HID usage tables (https://github.com/taylorconor/threeboard/blob/master/documentation/manuals/HID%20usage%20tables.pdf) document.

The user-facing functionality is split into layers. A layer changes the functionality of each key on the threeboard, similar to a shift or function key on a traditional keyboard. The threeboard has four different layers: a default DFLT layer, and three programmable layers:
- DFLT: The default layer of the threeboard. This is the layer that the threeboard starts in when it boots. No layer LEDs are lit in this layer. This is a single character input layer, where characters and modifiers in this layer are identified by their USB key codes.
- R: The character reprogramming layer of the threeboard. This layer allows users to reassign a keycode to a character. This allows faster input of common characters.
- G: The word shortcut layer. This layer allows users to program frequently used words into the threeboard. These words can then be accessed and sent over USB.
- B: The blob shortcut layer. This allows users to program arbitrary text blobs (including mod codes), and access them later.

The three programmable layers each have two modes: DFLT and PROG:
- DFLT: This is the default mode of the programmable layers. It is used to retrieve shortcuts that were programmed in the PROG mode, and send them over USB.
- PROG: This mode is used for programming the shortcuts used in the DFLT mode of the layer.

Each layer and mode defines its actions based on the input keypresses. Since there are many possible states, the full mapping of layers, modes, key combinations and actions is quite large, and is defined in the threeboard usage table in the appendix. However, most layers share some common actions for some keypresses:
- Key X: Increment bank 0.
- Key Y: Increment bank 1.
- Key Z: Send keypress(es) over USB (in DFLT mode), or store shortcut in PROG mode.
- Key combo X+Z: Clear bank 0.
- Key combo Y+Z: Clear bank 1.
- Key combo X+Y+Z: Go to the next layer (when in DFLT mode), or exit PROG mode otherwise.
- Key combo X+Y: Enter PROG mode (when in DFLT mode).

Brief examples of scenarios in each layer and mode configuration are visualised below:

### DFLT Layer


In the DFLT layer, the byte in bank 0 represents the raw USB keycode value to be sent to the host computer, and bank 1 represents the USB modifier code. This layer has no PROG mode.

### Layer R

Layer R is used for character reprogramming, which allows re-assigning a value of bank 0 to a different USB keycode than it represents in the DFLT layer. When this layer is being used in DFLT mode, bank 0 is used to identify the shortcut ID, and bank 1 is used as it is in the DFLT layer, to specify the USB modifier code.

In PROG mode, the current shortcut value at the specified shortcut ID is displayed in bank 0. The shortcut ID is instead displayed in bank 0.

### Layer G

Layer G is used for word shortcut programming. Words up to 15 characters long can be stored per shortcut ID, and modifier codes are used to apply USB modifier codes to the word shortcut (such as capitalizing the first letter). In DFLT mode, bank 1 is split into two 4-bit indicators to display two different values; the 4 high bits are used to display the length of the current shortcut, and the 4 low bits display the word modification code. Word modification codes cause the following modifications:
- Code 0: Word is sent in lowercase.
- Code 1: Word is sent in uppercase.
- Code 2: The first letter of the word is capitalized.
- Code 3: A period (.) is appended to the end of the word.
- Code 4: A comma (,) is appended to the end of the word.
- Code 5: A hyphen (-) is appended to the end of the word.
- Codes 6-15: Reserved. The word is sent in lowercase.

In PROG mode, the current USB keycode to be appended to the word shortcut is displayed in bank 0. The 4 high bits of bank 1 continues to display the length of the word shortcut, but the 4 low bits are unused and always set to 0.

### Layer B

Layer B allows for freeform blob shortcut programming. Blobs of up to 255 keycode and modcode pairs can be stored. In DFLT mode, bank 0 displays the current shortcut ID, and bank 1 displays the length of the shortcut stored there.


In PROG mode, bank 0 displays the USB keycode being programmed, and bank 1 displays the modcode.

## TECHNICAL INTRODUCTION

The remainder of this document is split into three large sections: firmware, simulator, and hardware. These sections provide an in-depth description of the background, design and architecture of both of these components, as well as detailed descriptions of some peripheral information, such as testing and simulating.

As already mentioned, the threeboard’s firmware and hardware are both built from scratch. Because of this, some features of firmware are inspired or required by properties of the hardware, and some features of hardware are inspired or required by the possibilities afforded by the firmware. For this reason, the firmware and hardware sections of this document contain links to each other. It’s possible to navigate between these sections to read relevant information about a feature of the threeboard from both a firmware and a hardware perspective, rather than reading the document from start to finish.

The appendix of this document contains the threeboard usage table, a definitive list of all of the possible threeboard states, inputs and outputs. Additionally, the appendix includes an explanation of how USB keyboards work in general. This might be good to read to understand the background of some of the concepts discussed in the document, but it’s not threeboard-specific.

## FIRMWARE

### Introduction

The threeboard’s firmware has two main functions. The first is to configure and interface with each hardware component on the threeboard (such as LEDs, EEPROMs and USB) according to their respective specifications. The second is to provide user-facing features and functionality to the threeboard as described in the functionality section.

Instructions on how to compile the threeboard firmware are available in the firmware build instructions section of the appendix.

### Constraints

The threeboard uses an atmega32u4 (https://www.microchip.com/wwwproducts/en/ATmega32u4) microcontroller (MCU), a low-power 8-bit microcontroller (https://en.wikipedia.org/wiki/Microcontroller) based on the AVR (https://en.wikipedia.org/wiki/AVR_microcontrollers) enhanced RISC architecture. (https://en.wikipedia.org/wiki/Reduced_instruction_set_computer) Firmware code compiled for this MCU uses the Atmel AVR instruction set. (https://en.wikipedia.org/wiki/Atmel_AVR_instruction_set)

The MCU itself has the following relevant features:
- 8-bit AVR architecture.
- 16MHz maximum frequency at 4.5V.
- 32KB flash-based program memory.
- 2.5KB SRAM.
- 1KB internal EEPROM.
- USB controller hardware support.
- Two 8-bit and two 16-bit timers.
- Byte oriented 2-wire serial interface.

Due to these MCU constraints, this is a bare-metal firmware project. This means that the firmware’s instructions are executed directly on the MCU hardware, without an intervening operating system.

As a result of the lack of operating system, hardware MMU, (https://en.wikipedia.org/wiki/Memory_management_unit) and the severely restricted RAM size, the firmware does not perform any dynamic memory allocation (i.e. no heap allocation). All memory allocation is stack-based.

It’s important to mention that there is no official C++ standard library support for AVR targets. Therefore targets compiled with the AVR C++ compiler, avr-gcc, (https://gcc.gnu.org/wiki/avr-gcc) will not link against libstdc++. All firmware code in the threeboard project cannot use any C++ standard library functions or headers.

### Design principles

The threeboard firmware was designed with several core principles in mind. These are listed below, along with the reasoning for their inclusion:
1. Readability: This is the primary design principle of the firmware. The C++ source itself should be clear, consistent, and well documented. It should be possible for anyone with passable C/C++ knowledge and no embedded programming knowledge to read it and learn from it.
- Reasoning: Source code with consistent style reduces unnecessary mental load when reading the code, as the code style is predictable. Additionally, the motivation section above states that as many people as possible should be able to read and learn from this project, regardless of engineering background. Reducing readability friction helps achieve this goal.
2. Modularity: There should be a clear separation of concerns between different modules of the code, and no interdependence. Modules that need to affect change on other modules should do so via delegation.
- Reasoning: It’s hard to determine if a class fulfils its responsibilities if it has multiple distinct responsibilities, and it’s hard to guarantee separation of concerns when this mix of responsibilities inevitably leads to reduced encapsulation. Reduced encapsulation causes dependency hell, (https://en.wikipedia.org/wiki/Dependency_hell) which makes code hard to maintain and greatly reduces readability by making the control flow difficult to follow.
3. Testability: Each module must be testable in isolation. All external module dependencies should be abstract to enable mocking and deterministic testing.
- Reasoning: Untested code should be assumed to have bugs, so full test coverage is essential. Making classes easier to test in isolation makes it easier to write concise test cases.

### Toolchain

The atmega32u4 chip manufacturer (Atmel / Microchip) provides a toolchain (https://en.wikipedia.org/wiki/Toolchain) for use with AVR development, in particular avr-gcc, (https://www.microchip.com/en-us/development-tools-tools-and-software/gcc-compilers-avr-and-arm) a GCC compiler for AVR. This toolchain works out of the box for all stages of firmware development.

The threeboard firmware is built with Bazel. (http://bazel.build/) Bazel was chosen over more traditional build systems like CMake because it has the following useful properties:
1. Explicit dependencies: All dependencies on a translation unit (https://en.wikipedia.org/wiki/Translation_unit_(programming)) must be explicitly defined in the Bazel BUILD file, and each translation unit is compiled in a sandbox environment that only has access to the dependencies that have been explicitly declared. This makes it impossible to introduce implicit project dependencies. Additionally, Bazel fails the build if it detects a dependency cycle.
2. Customisable target declarations: Targets can be used to produce multiple object files, compiled with different compiler settings and even with different compilers. This allows compatible modules to be compiled for both x86 and AVR, depending on the context in which it’s being compiled.

Bazel has no pre-existing support for the AVR toolchain, so support had to be added for this project. The avr-bazel (https://github.com/taylorconor/avr-bazel) repository was built especially for the threeboard project. It contains some special Bazel build rules to produce joint x86 and AVR build targets. This allows defining a single target definition per BUILD file to produce libraries for both targets, to avoid having to double-declare them.

### Architecture

Overview
The architecture of the threeboard firmware can roughly be grouped into three categories of modules/classes:
1. Business logic modules: These codify the functionality of the firmware, and coordinate other modules to execute this functionality.
2. Native-interacting modules: Generally serve the purpose of configuring and controlling a single hardware element, such as LEDs or USB.
3. Pure AVR modules: Modules that can only be compiled for the AVR architecture, i.e. those that interact directly with hardware.


Everything except pure AVR modules target both AVR and x86 targets, which enables tests to run on x86 development hosts. These modules don’t depend on any avr-libc headers, so all of their interactions with hardware are proxied through the firmware’s Native interface, which exposes an API to interact with hardware. The interface itself does not depend on avr-libc, so non-pure modules can depend on it. When the firmware is compiled to be run on an AVR host or simulator, an avr-libc dependent Native implementation (NativeImpl) is used.

Event loop
The core of the threeboard firmware is a simple event loop; a design pattern that waits for and dispatches events to relevant modules when they arrive. The event loop is a never-ending loop that runs as long as the firmware is running (i.e. as long as the device has power).

The responsibilities of the different timers used, and the encapsulation afforded by the event loop is summarised in the diagram below:

Each event loop iteration is triggered by an interrupt. (https://en.wikipedia.org/wiki/Interrupt) Two timer-based interrupts are used in the threeboard firmware: Timer 1 in CTC mode is configured to produce a software interrupt every 2ms, and is used to refresh the next LED scan line; Timer 3, also in CTC mode, is configured to produce a software interrupt every 5ms, used mainly to poll the key switches and produce events on the event buffer if necessary. Running timer 3 slower and separately from timer 1 allows us to avoid debouncing the Cherry MX (https://en.wikipedia.org/wiki/Cherry_(company)#Cherry_MX_switches_in_consumer_keyboards) key switches in software. Debouncing is discussed in more detail in the mechanical key switch section in hardware.

The purpose of the event loop is to receive and process all keypress events according to the actions defined in the current Layer of the threeboard. Each Layer instance encapsulates all business logic relating to inputs and actions for a given layer, so this doesn’t need to happen in a long list of if/else statements within the main program loop.

void Threeboard::RunEventLoop() {
// USB setup and configuration. ...

// Main event loop.
while (true) {
// Atomically check for new keyboard events, and either handle them or // sleep the CPU until the next interrupt. native_->DisableInterrupts();
if (!event_buffer_->HasEvent()) {
// Sleep the CPU until another interrupt fires. native_->EnableCpuSleep(); native_->EnableInterrupts(); native_->SleepCpu();
native_->DisableCpuSleep();
} else {
if (event_buffer_->HasKeypressEvent()) { layer_controller_.HandleEvent(event_buffer_->GetKeypressEvent());

}
// Re-enable interrupts after handling the event. native_->EnableInterrupts();
}
}
}

The sleep enabled bit is set before each sleep and cleared after each sleep, as recommended in the atmega32u4 datasheet (section 7.9.1): it is recommended to write the Sleep Enable (SE) bit to one just before the execution of the SLEEP instruction and to clear it immediately after waking up.

When finished handling events in the event buffer, the event loop puts the MCU into idle mode. In this mode, the CPU clock is stopped, but the clock powering the MCU’s timers continues. The MCU is brought out of idle mode when the timer produces a software interrupt. The purpose of the event loop can therefore be thought of as to efficiently facilitate delegation between each module in the threeboard, without requiring busy-waiting. (https://en.wikipedia.org/wiki/Busy_waiting)

Delegation
The threeboard makes extensive use of delegation (https://en.wikipedia.org/wiki/Delegation_pattern) to allow different modules in the firmware to communicate with each other without introducing circular dependencies.

In certain situations, two-way function calling between modules is necessary. The first of such situations this document will explain is the LayerController. It needs to be able to provide events to individual Layers to be handled. But some of these events may trigger an action that affects the LayerController itself, such as a keypress event that triggers the threeboard to switch layers. In this case, the current Layer uses the LayerControllerDelegate to call SwitchToLayer() on the LayerController, without having to explicitly depend on the LayerController:

The Threeboard’s event loop receives timer interrupts in a similar fashion to the LayerController. In this case, the Native implementation is not owned by the Threeboard class, instead it’s passed in as part of the bootstrapping process. This allows Native-specific timers to call functions in the Threeboard class (via the TimerInterruptHandlerDelegate) without introducing a circular dependency:

LED indicators
The LED indicators on the threeboard are vital to understanding the current state of the threeboard. The hardware is equipped with 22 single-colour LEDs. These are arranged as follows:


1. 8 LEDs to display the binary value of bank_0 (1 byte).
2. 8 LEDs to display the binary value of bank_1 (1 byte).
3. 3 LEDs to display the current layer, which is one of R, G or B (or DFLT if no LEDs are lit).
4. 1 PROG LED to identify when the device is in PROG mode.
5. 1 ERR LED to indicate an error.
6. 1 STATUS LED to provide context-specific status information.

The hardware-specific details of these LEDs, such as their wiring and tolerance, is described in the hardware section.

The LED indicator lights are all controlled by the LedController. This class is responsible for maintaining the state of the raster scan and outputting the LedState (a simple class for storing the state of each LED) to hardware. Its interface is very simple:

class LedController {
public:
explicit LedController(native::Native *native);

// Handles rendering of the next scan row. Called by the timer interrupt // handler every 2ms.
void ScanNextLine();

// Handles timing of LED blinking. Called by the timer interrupt handler every // 5ms.
void UpdateBlinkStatus();

// state_ is guaranteed to live for the entire lifetime of the firmware. LedState *GetLedState() { return &state_; }
};

As discussed in the hardware section, the LEDs on the threeboard are arranged in a 5 row, 4 column matrix. When the ScanNextLine() function is called, the active LEDs in the next row of the matrix are lit, and all other LEDs are turned off. ScanNextLine() is called every 2ms by timer 1, which provides a 100Hz refresh rate on the threeboard’s LEDs.

The LedController is also responsible for maintaining the timing of blinking LEDs. UpdateBlinkStatus() increments an 8-bit blink timer. Two blink states are supported by the threeboard: LedState::BLINK flashes the LED when bit 7 of the timer toggles (every 640ms), and LedState::BLINK_FAST flashes when bit 6 toggles (every 320ms).

USB stack
The threeboard contains a full USB device implementation. The threeboard presents itself to hosts as a USB version 2.0 (https://www.usb.org/document-library/usb-20-specification) keyboard HID device, (https://en.wikipedia.org/wiki/USB_human_interface_device_class) complies with HID version 1.11, (https://www.usb.org/document-library/device-class-definition-hid-111) and passes USB CV test specification 0.72. (https://www.usb.org/document-library/usb-31-command-verifier-compliance-test-specification-version-072)

The USB protocol is extremely complex and so is not explained in full in this document. To learn how USB works, I recommend reading how do USB keyboards work? In the appendix of this document, the USB in a NutShell (https://www.beyondlogic.org/usbnutshell/usb1.shtml) series of articles, and to use the USB 2.0 specification (https://www.usb.org/document-library/usb-20-specification) as a reference. This section will summarise the design and architecture of the threeboard’s USB stack without going into any detail about the USB standard.

In the threeboard firmware, the USB stack is abstracted behind a minimal interface:

class Usb {
public:
// Setup the USB hardware to begin connection to the host. This method blocks // until the device hardware is correctly set up. If this method returns false // it means setup was halted by an error issued via the ErrorHandlerDelegate // and is in an undefined state.
virtual bool Setup() = 0;

// Returns true if the HID device configuration has completed successfully. virtual bool HasConfigured() = 0;

// Send the provided key and modifier code to the host device. Returns false // if an error occurred during sending.
virtual bool SendKeypress(uint8_t key, uint8_t mod) = 0;
};

The UsbImpl class is the concrete implementation of the Usb interface and interacts with the MCU’s USB registers and functionality using the Native interface. Failure to set up correctly via Usb::Setup(), and subsequent failure to configure within the first 50 USB frames (50ms) using Usb::HasConfigured() will stall the threeboard’s firmware startup logic, and enter an error state that continuously attempts to establish a connection to the host over USB.

USB setup begins with the firmware configuring the MCU to enable an electrical USB connection with the host device, as defined in the atmega32u4 datasheet, section 21.12. For example, the MCU contains phase-locked loop (PLL) (https://en.wikipedia.org/wiki/Phase-locked_loop) hardware. When enabled, this can convert the external 16MHz clock signal to a 12MHz clock needed for the USB controller hardware in the MCU when configured in full-speed mode (atmega32u4 datasheet, section 21.2):

bool UsbImpl::Setup() {

// Enable the USB pad regulator (which uses the external 1uF UCap). native_->SetUHWCON(1 << native::UVREGE);
// Enable USB and freeze the clock.
native_->SetUSBCON((1 << native::USBE) | (1 << native::FRZCLK));
// PLL Control and Status Register. Configure the prescaler for the 16MHz // clock, and enable the PLL.
native_->SetPLLCSR((1 << native::PINDIV) | (1 << native::PLLE));
// Busy loop to wait for the PLL to lock to the 16MHz reference clock. WAIT_OR_RETURN(!(native_->GetPLLCSR() & (1 << native::PLOCK)), UINT16_MAX, "Failed to lock PLL during USB setup"); // Enable USB and the VBUS pad.
native_->SetUSBCON((1 << native::USBE) | (1 << native::OTGPADE));
// Configure USB general interrupts (handled by the USB_GEN_vect routine). We // want to interrupt on start of frame (SOFE), and also on end of reset
// (EORSTE).
native_->SetUDIEN((1 << native::EORSTE) | (1 << native::SOFE));
// Connect internal pull-up attach resistor. This must be the final step in // the setup process because it indicates that the device is now ready. native_->SetUDCON(native_->GetUDCON() & ~(1 << native::DETACH));
return true;
}

Once the device hardware is correctly set up, the threeboard informs the host of its capabilities using a series of descriptors. (https://www.beyondlogic.org/usbnutshell/usb5.shtml) The device descriptor specifies fundamental information about the device (including which USB standard it supports and its unique ID). Other important descriptors follow, which inform the host of the class of the device; in this case a HID-compatible (https://en.wikipedia.org/wiki/USB_human_interface_device_class) keyboard device.

All USB communication is host-centric. This means that no data can be sent from the device to the host unless the host requests it. For this reason, the threeboard’s USB stack is interrupt-driven. The atmega32u4 provides hardware support to issue software interrupts identifying the beginning of a USB message frame, which is the USB host potentially requesting information from the device, such as keypress data or specific descriptor information, for example, to determine what strings to display as the name of the USB device on the host computer. The threeboard’s USB interrupts are facilitated by the
UsbInterruptHandlerDelegate, which allows the Native layer to pass messages to the USB stack without dependency issues, as discussed in the delegation section.

Once the USB stack has correctly configured, the threeboard’s firmware enters the event loop. Individual layers can decide when to flush their state to the USB host (using Layer::FlushToHost()) based on their received keypress events. This triggers one or more UsbImpl::SendKeypress() calls, which attempts to send an individual key press to the host over USB:

bool UsbImpl::SendKeypress() {
uint8_t intr_state = native_->GetSREG(); native_->DisableInterrupts();
uint8_t initial_frame_num = native_->GetUDFNUML();

while (true) {
native_->SetUENUM(kKeyboardEndpoint);
native_->EnableInterrupts();
// Check if we're allowed to push data into the FIFO. If we are, we can // immediately break and begin transmitting.
if (native_->GetUEINTX() & (1 << native::RWAL)) {
break;
}
native_->SetSREG(intr_state);
// Ensure the device is still configured. RETURN_IF_ERROR(hid_state_.configuration);
// Only continue polling RWAL for 50 frames (50ms on our full-speed bus). if ((native_->GetUDFNUML() - initial_frame_num) >= kFrameTimeout) { return false;
}
intr_state = native_->GetSREG();
native_->DisableInterrupts();
}

SendHidState();
native_->SetSREG(intr_state); return true;
}

Storage
The threeboard is equipped with three EEPROM (https://en.wikipedia.org/wiki/EEPROM) storage devices: One 1 KB EEPROM built into the atmega32u4 MCU, and two 512 kbit external EEPROMs connected to the MCU via the MCU’s TWI (two-wire interface) bus. These communicate with the MCU using the I2C protocol. (https://en.wikipedia.org/wiki/I%C2%B2C)

In firmware, the data in these storage devices are all controlled on a high level by the StorageController, which is used by each of the programmable Layers for their respective storage needs. The StorageController uses the I2C module to abstract away the interfacing logic between the MCU and relevant EEPROMs.

The internal 1 KB EEPROM is used to store all of the character shortcuts for Layer R, in addition to the lengths of each of the shortcuts stored in layers G and B. The first external EEPROM (referred to as EEPROM 0) stores each of the word shortcuts for Layer G, along with the first 120 blob shortcuts for Layer B. The second external EEPROM (EEPROM 1) stores the remaining 128 shortcuts Layer B shortcuts.

Because Layer B (the blob shortcut layer) allows storage of per-character USB modifier codes, these must be stored in EEPROM along with each keycode. This means that each 256-character blob shortcut requires 512 bytes to store.

The storage layout is visualised below:

### Style guide

A number of high-level style decisions have been made to make the code as uniform and as readable as possible:
1. All source files must be formatted with clang-format (https://clang.llvm.org/docs/ClangFormat.html) using the included
.clang-format config file.
2. Class and member function names use UpperCamelCase style. Member variables use trailing_snake_case_ style, and local variables use regular_snake_case.
3. Raw pointers should be used to inject dependencies or for output parameters. They must be non-owning and non-null. Raw pointers are used over references purely because they exhibit pointer semantics, (https://stackoverflow.com/questions/166033/what-do-value-semantics-and-pointer-semantics-mean) making interactions with them more explicit. It follows that non-const references are not allowed.
4. Single-argument constructors must be marked explicit, or commented to indicate why implicit construction is favourable.
5. Relative include paths are not allowed.
6. Every class definition should have a comment explaining the function of the class. Each method and member declaration should also have comments unless trivial.

### Testing strategy

The threeboard firmware is tested using three different testing levels:
1. Unit tests: Simple test cases for individual classes. These tests generally mock (https://en.wikipedia.org/wiki/Mock_object) all of the dependencies of the class under test and set expectations on how the mocks will be used by the class. The threeboard firmware is written with this testability in mind, and most classes take pointers to abstract classes as their dependencies in their constructors. These abstract classes generally have two implementations: a ‘real’ implementation and a mock. Mock instances will be passed to the class during testing.
2. Simulated integration tests: This test suite uses the full simulated firmware (using the threeboard simulator) to run tests against the entire threeboard firmware end-to-end. These tests apply a sequence of keypresses to the simulated firmware and make expectations on USB interactions, LED states and character output.
3. Simulated property tests: The property test suite uses a similar setup to the integration tests in that tests are run end-to-end on the simulated threeboard firmware. This test executes keypresses on the simulator, and also on a threeboard model, used to represent the desired behaviour of the system under test. The test generates a random sequence of 25,000 input keypresses, executes them one at a time, and asserts the property that the simulator and the threeboard model must share the same state before and after the keypress is processed.

All tests run within the Google Test framework (https://github.com/google/googletest) for testing and mocking.

## SIMULATOR

### Introduction

Debugging embedded firmware is generally difficult and slow, as target hardware limitations usually prevent meaningful logging or the ability to connect a debugger and use real-time software breakpoints.
Developing embedded firmware without access to a simulator means all firmware needs to be flashed and run on the target
hardware, which becomes
cumbersome.

For these reasons, the threeboard project includes a fully functional terminal-based threeboard simulator for Linux and macOS, built on top of the simavr project. (https://github.com/buserror/simavr) The simulator enables running and debugging of the threeboard AVR firmware on the same x86 platform used for development, which greatly improves development speed and makes debugging far easier and more accessible. Most importantly, the firmware being simulated is the same firmware binary that runs on physical hardware: no simulator-specific code paths exist in the firmware, although UART-based (https://en.wikipedia.org/wiki/Universal_asynchronous_receiver-transmitter) logging is disabled when building for physical hardware.

Instructions on how to compile and run the simulator are available in the simulator build instructions section of the appendix.

### Features

The simulator runs a terminal-based graphical emulator of the threeboard hardware, designed to look as similar as possible to the actual threeboard hardware, with the LEDs and key switches laid out almost identically.

Other simulator features include:
- GDB debugging support: The simulator exposes a gdbserver (https://en.wikipedia.org/wiki/Gdbserver) to enable debugging of the firmware being simulated. Disabled by default, when enabled (by using the shortcut key
g) the server runs locally on port 1234.
- Mock USB host: To simulate communication between the threeboard and a USB host (a computer), the simulator includes a mocked USB host which appears to the simulated firmware as a real USB host computer. The firmware will send keypresses over USB to the mocked host just as it would to a real host, and the simulator outputs these keypresses to the simulator UI in the “keyboard output” section of the UI.
- Logging: The threeboard simulator includes a mock data receiver capable of receiving logging information from the simulated threeboard firmware via the simulated hardware’s UART pins. LOG() and LOG_ONCE() macros in the firmware produce logs that are transmitted to this mock data receiver in the simulator. These macros are only enabled when building the firmware for the simulator, because the threeboard firmware doesn’t correctly initialise the UART pins or clock, it takes advantage of simavr’s UART implementation to transmit data instantaneously from the firmware to the simulator.
- MCU state visualisation: Several high-level states are used by simavr to categorize the MCU’s current operating mode. Examples include RUNNING, SLEEPING and CRASHED. The threeboard simulator includes a visualisation of the amount of time spent in each state while running the simulator, which is useful when trying to optimise power usage or detect infinite or expensive loops in firmware.
- Memory usage indicator: The simulator includes a simple memory usage indicator, which displays both static memory usage (from .data (https://en.wikipedia.org/wiki/Data_segment) and .bss (https://en.wikipedia.org/wiki/.bss) segments) and dynamic memory usage. Since the threeboard hardware constraints forbid dynamic memory allocation, dynamic memory usage is an indication of stack use.
- Mock LED permanence: The simulator’s terminal-based UI displays the threeboard’s LEDs in red (on) or grey (off). The simulator attempts to emulate the LED matrix permanence property discussed in the LED hardware section, by setting a minimum time an LED may be lit for. This makes the simulated LEDs in the terminal behave as similarly as possible to the real LEDs on the threeboard, and makes it possible to spot timing bugs or other issues with the LEDs raster scanning logic.

### Design

The simulator is effectively a wrapper around simavr, (https://github.com/buserror/simavr) an exceptionally good AVR simulator that supports lots of features of many AVR microcontrollers, and is easy to configure with new MCUs and features. Simavr does most of the difficult work of simulating the firmware: given the threeboard firmware binary file, simavr parses it, determines the properties of the MCU being simulated based on headers in the binary, and can execute the instructions one cycle at a time. It supports interrupts and timing, and has full support for the atmega32u4’s USB controller.

Events are issued and handled in simavr using IOCTL calls. (https://en.wikipedia.org/wiki/Ioctl) These allow a way of triggering arbitrary functionality and message passing within simavr, which enables its configurability.

The simulator is comprised of several interoperating modules which emulate the properties of different hardware components on the threeboard. Modules are needed for external components (EEPROMs and UART) and for emulating a USB host machine to send keypress information.


The UI module is responsible for translating the state of the simulator into a visualisation of the result of that state on the threeboard’s hardware, in particular its LEDs. It’s a purely text-based user interface (https://en.wikipedia.org/wiki/Text-based_user_interface) implemented using ncurses. (https://en.wikipedia.org/wiki/Ncurses) The static outlines and frames of the UI are drawn once, and the dynamic components are redrawn at a rate of 200Hz.

The USB host component is far from a standards-compliant host implementation. It contains the least amount of logic required to make the threeboard firmware believe it is communicating with a real USB host. It simply polls the USB controller in firmware by triggering USB general interrupts which cause the firmware to periodically send its HID state over USB.

## HARDWARE

### Introduction

The threeboard’s hardware is a custom-designed PCB. It includes all electrical components needed to operate the threeboard, as well as test points that can be used to flash new firmware to the MCU. The majority of the components used are surface mounted, with through-holes used for some of the larger components.

This section of the document describes the design goals of the threeboard hardware, the choice of components, and electrical design decisions.

### Hardware design goals

Similar to the design principles of the firmware, the threeboard’s hardware was designed with several goals in mind:
1. Simplicity: This implies that nothing should exist on the PCB that isn’t completely necessary for the operation of the threeboard, and any hardware that can be offloaded to the MCU’s hardware (such as making use of the internal pull-up resistors on certain pins) should be. More importantly, simplicity also applies to the hardware design patterns used; it should be possible to learn from the hardware design of the threeboard with little or no electrical engineering experience.
2. Hand-solderable: It should be possible to solder all components onto the threeboard by hand, with only basic soldering experience. This improves the accessibility of the hardware so it can be easily assembled. For example, all resistor and capacitor pads use an SMD 0805 package size. (https://eepower.com/resistor-guide/resistor-standards-and-codes/resistor-sizes-and-packages) Also, the atmega32u4 MCU used by the threeboard is the 10x10mm TQFP (https://en.wikipedia.org/wiki/Quad_flat_package) package, despite the MCU being offered in a smaller 7x7mm QFN (https://en.wikipedia.org/wiki/Flat_no-leads_package) package, as it would be more difficult to solder.
3. Inexpensive to manufacture: No unnecessarily expensive components should be used, and no PCB features should be included that are difficult (and expensive) to manufacture unless absolutely necessary. For this reason, the threeboard PCB only uses two layers, minimal through-hole components, (https://en.wikipedia.org/wiki/Through-hole_technology) and as few via holes (https://en.wikipedia.org/wiki/Via_(electronics)) as possible.

### Design

This section is split into subsections that explain the design of each major hardware component. In many cases, images of the threeboard’s PCB and electrical schematic are used to aid the explanation. In these cases, the image of the relevant piece of the PCB will always be on the left, and the relevant part of the schematic on the right.

USB

The threeboard’s USB hardware is very simple because the atmega32u4 has dedicated USB pins that map directly to the USB connector (pictured in red). The only additional hardware required is specified by the atmega32u4 datasheet, sections 2.2.8 and 2.2.9, which states that the D+ and D- USB data upstream ports should be connected to the USB data connector pins via serial 22Ω resistors (pictured in blue and green).

The complexity of the USB integration lies in the firmware. It’s responsible for keeping track of bus timing, issuing interrupts, and parsing and sending messages. This is discussed in detail in the firmware section’s USB stack subsection.

LEDs


In order to be able to drive 22 LEDs using only 11 MCU pins, the majority of the threeboard’s LEDs are wired in a multiplexed matrix, (https://en.wikipedia.org/wiki/Multiplexed_display) where each individual LED in the matrix is addressable by a row and column value. In this configuration, all of the LEDs can’t be lit at the same time. Instead, each row of LEDs is scanned over in a raster scanning (https://en.wikipedia.org/wiki/Raster_scan) fashion, and individual LEDs that should be lit are turned on until the next raster scan turns them off.

This row scanning happens within the firmware and is triggered every 2ms by timer interrupt 1. Given that there are 5 rows, a full refresh takes 10ms, which gives the threeboard’s LED indicators a refresh rate of 100Hz, which is well above the threshold for perceivable flicker by the human eye. (https://en.wikipedia.org/wiki/Flicker_fusion_threshold)

Only one LED from a column is lit at any one time, since only one LED from each column exists in a given row. Each column of LEDs is protected by one 220Ω current-limiting resistor in series to restrict the current to each LED to 22mA (calculated using Ohm’s law (https://en.wikipedia.org/wiki/Ohm%27s_law) given the 5V input voltage from USB).

There are two LEDs on the threeboard that are not included in the multiplexed LED matrix. These are the STATUS (shown in green) and ERR (shown in red) LEDs. They’re configured in parallel with their polarities inverted so that only one can be lit at any given time, and so that only one resistor and two MCU pins are required to drive them. These LEDs are configured in this way for two reasons:
1. 22 LEDs are hard to arrange in a row-column matrix since the number 22 has very few factors. The only configurations would be a 1x22 matrix (which isn’t a matrix) or a 2x11 matrix (which doesn’t reduce the use of LEDs or pins very much). So it’s more economical to put 20 LEDs in a 5x4 matrix and the remaining two in a standalone pair.
2. It’s beneficial when reporting errors or debugging issues with the firmware on the physical board (rather than the simulator) to have some LEDs which can be decoupled from the raster scanning loop. This means that if there are firmware issues with the loop logic, or issues with the MCU’s timer configuration, the STATUS or ERR LEDs can be lit independently of the matrix to help with debugging or surfacing errors.

Mechanical key switches

The threeboard uses Cherry MX (https://deskthority.net/wiki/Cherry_MX) SPST-NO (single pole, single throw, normally open) (https://en.wikipedia.org/wiki/Switch#Contact_terminology) mechanical switches for its physical key switches. The bounce time (https://en.wikipedia.org/wiki/Switch#Contact_bounce) of these switches differs depending on the type of switch and the date of manufacture, but it’s safe to assume that it will be below 5ms. Most modern Cherry MX key switches have a 1ms bounce time.

These switches are wired directly to ground, which means they are configured to be active low; (https://en.wikipedia.org/wiki/Logic_level#Active_state)

when pressed, they connect their MCU pin to ground. To avoid the situation where an unpressed switch leaves its corresponding MCU pin floating, each switch defaults to high using a pull-up resistor. (https://en.wikipedia.org/wiki/Pull-up_resistor) The atmega32u4 includes internal pull-up resistors on a number of its pin ports, so all three switches are wired to pins on PORTB which includes internal pull-up resistors as specified by the atmega32u4 datasheet, section 2.2.3, with typical resistances of 20-50kΩ.

The MCU pins used for the key switches were chosen carefully to correspond to the pins used for SCK (shown in red), MISO (shown in green), and MOSI (shown in blue) of the atmega32u4’s SPI interface. (https://en.wikipedia.org/wiki/Serial_Peripheral_Interface) These pins are necessary when flashing new firmware onto the MCU using SPI, and so wiring them to the legs of the key switches removes the need for adding dedicated testing pads to connect these pins to an SPI programmer during flashing.

External EEPROMs


The threeboard contains two external 512 kbit EEPROM devices. These devices communicate with the MCU using its 2-wire serial interface (the I2C protocol). (https://en.wikipedia.org/wiki/I%C2%B2C) The atmega32u4 MCU has built-in hardware support for this interface, with a dedicated data pin (SDA) and clock pin (SCL), which collectively form the TWI (two-wire interface) bus. This interface is described in detail in the atmega32u4 datasheet, section 20.

The EEPROM devices can both be connected in parallel to these pins, as the I2C protocol uses 7-bit addresses, allowing for up to 128 devices on the same bus. Two 4.7kΩ pull-up resistors are used to pull each bus line high when not driven low by the open-drain (https://en.wikipedia.org/wiki/Open_collector) interface, as mentioned in the atmega32u4 datasheet, section 20.2: The only external hardware needed to implement the bus is a single pull-up resistor for each of the TWI bus lines.


External quartz crystal clock

The threeboard includes a 16MHz quartz crystal oscillator (shown above in blue) as a clock source to the MCU. The MCU contains dedicated hardware pins for use with the external clock (XTAL1 and XTAL2), and the atmega32u4 datasheet, section 6.3, recommends the crystal to be wired as shown in the diagram above, with external capacitors within a 12pF - 22pF range (shown in red and green).

Decoupling capacitors


Decoupling capacitors (https://en.wikipedia.org/wiki/Decoupling_capacitor) are positioned close to each VCC-connected pin on the MCU, to reduce the effect of voltage spikes and drops from the USB power supply. They are also necessary to facilitate instantaneous current increases that may be required by the MCU, as various actions performed by the MCU may have different current requirements.

MCU

The threeboard includes a reset push button to help flash firmware to the MCU during development. The reset switch (shown above in blue) is connected to the RESET pin in the MCU, pulled up to VCC with a 10kΩ pull-up resistor (shown in green). Additionally, the HWB pin is forced low to instruct the MCU to execute the USB bootloader on reset, which allows flashing new firmware on reset. To force it low, it’s tied to ground using a 10kΩ pull-down resistor (shown in red) to prevent the pin from floating.

As specified in the atmega32u4 datasheet, section 2.2.12, the UCap pin must be connected to a 1μF capacitor to regulate the USB output supply voltage.

### Manufacturing


The threeboard project repository contains all of the files needed to manufacture a threeboard PCB, (https://en.wikipedia.org/wiki/Printed_circuit_board) in the hardware subdirectory. (https://github.com/taylorconor/threeboard/tree/master/hardware) These files can be opened using KiCad, (https://en.wikipedia.org/wiki/KiCad) a common open-source PCB design tool. The PCBs must be manufactured by a professional PCB manufacturing company. I recommend PCBWay (https://www.pcbway.com/) as I’ve had great experiences using them to manufacture each iteration of the threeboard development boards. To make manufacturing easier, the threeboard repository contains a prebuilt gerber.zip (https://github.com/taylorconor/threeboard/blob/master/hardware/gerber.zip) package which is all that’s needed to be provided to a PCB manufacturer such as PCBWay to manufacture threeboard PCBs.

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

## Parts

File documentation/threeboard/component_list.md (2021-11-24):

# threeboard component list

| Component ID | Description |
| --- | --- |
| [ATMEGA32U4-AUR](https://www.digikey.com/en/products/detail/microchip-technology/ATMEGA32U4-AUR/2238241) | Atmega32u4 8-bit microcontroller in 44 pin TQFP (10mm x 10mm) package. |
| [C0805C220J5GACTU](https://www.digikey.com/en/products/detail/kemet/C0805C220J5GACTU/411112) | 22pF ±5% 50V Ceramic Capacitor, SMD 0805. |
| [CC0805ZRY5V9BB104](https://www.digikey.com/en/products/detail/yageo/CC0805ZRY5V9BB104/2103145) | 0.1µF -20%, +80% 50V Ceramic Capacitor, SMD 0805. |
| [CC0805KKX7R7BB105](https://www.digikey.com/en/products/detail/yageo/CC0805KKX7R7BB105/2103149) | 1µF ±10% 16V Ceramic Capacitor, SMD 0805. |
| [CC0805ZRY5V6BB475](https://www.digikey.com/en/products/detail/yageo/CC0805ZRY5V6BB475/2103155) | 4.7µF -20%, +80% 10V Ceramic Capacitor, SMD 0805. |
| [RMCF0805JT22R0](https://www.digikey.com/en/products/detail/stackpole-electronics-inc/RMCF0805JT22R0/1942533) | 22Ω 5% 1/8W resistor, SMD 0805. |
| [RMCF0805JT220R](https://www.digikey.com/en/products/detail/stackpole-electronics-inc/RMCF0805JT220R/1942544) | 220Ω 5% 1/8W resistor, SMD 0805. |
| [RMCF0805JT10K0](https://www.digikey.com/en/products/detail/stackpole-electronics-inc/RMCF0805JT10K0/1942577) | 10kΩ 5% 1/8W resistor, SMD 0805. |
| [24LC512-I/MF](https://www.digikey.com/en/products/detail/microchip-technology/24LC512-I-MF/523013) | 512KBIT EEPROM I2C 8DFN. |
| [USB3070-30-A](https://www.digikey.com/en/products/detail/gct/USB3070-30-A/9859704) | Micro USB B female socket. |
| [PTS526 SK08 SMTR2 LFS](https://www.digikey.com/en/products/detail/c-k/PTS526-SK08-SMTR2-LFS/10056632) | Tactile Switch SPST-NO Top Actuated Surface Mount, 5.2mm x 5.2mm. |
| [LTL-1CHE](https://www.digikey.com/en/products/detail/lite-on-inc/LTL-1CHE/670000) | Diffused red LED. |
| [MX1A-E1NW](https://www.digikey.com/en/products/detail/cherry-americas-llc/MX1A-E1NW/20180) | Cherry MX “Blue” mechanical key switch SPST-NO 0.01A 12V. |
| [FA-238 16.0000MB-C3](https://www.digikey.com/en/products/detail/epson/FA-238-16.0000MB-C3/2403459) | 16MHz ±50ppm Crystal 18pF 80 Ohms 4-SMD. |

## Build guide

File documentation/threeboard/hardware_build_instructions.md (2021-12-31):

# threeboard hardware build instructions
## Manufacturing
<p align="center">
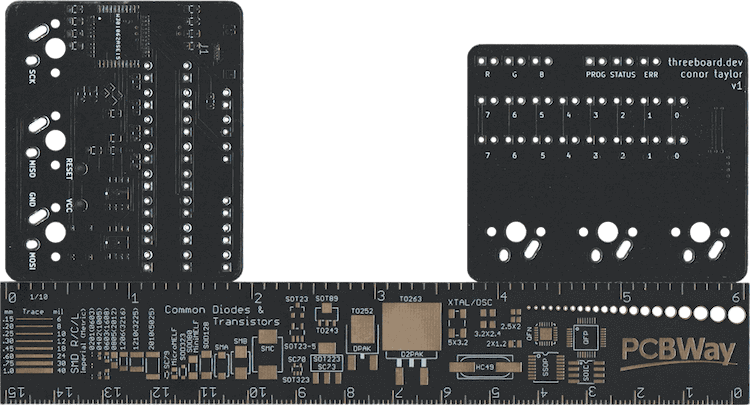
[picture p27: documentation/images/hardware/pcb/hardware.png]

</p>

The threeboard project repository contains all of the files needed to manufacture a threeboard [PCB](https://en.wikipedia.org/wiki/Printed_circuit_board), in the [hardware subdirectory](https://github.com/taylorconor/threeboard/tree/master/hardware). These files can be opened using [KiCad](https://en.wikipedia.org/wiki/KiCad), a common open-source PCB design tool. The PCBs must be manufactured by a professional PCB manufacturing company. I recommend [PCBWay](https://www.pcbway.com/) as I’ve had great experiences using them to manufacture each iteration of the threeboard development boards. To make manufacturing easier, the threeboard repository contains a prebuilt [`gerber.zip`](https://github.com/taylorconor/threeboard/blob/master/hardware/gerber.zip) package which is all that’s needed to be provided to a PCB manufacturer such as PCBWay to manufacture threeboard PCBs.

<p align="center">
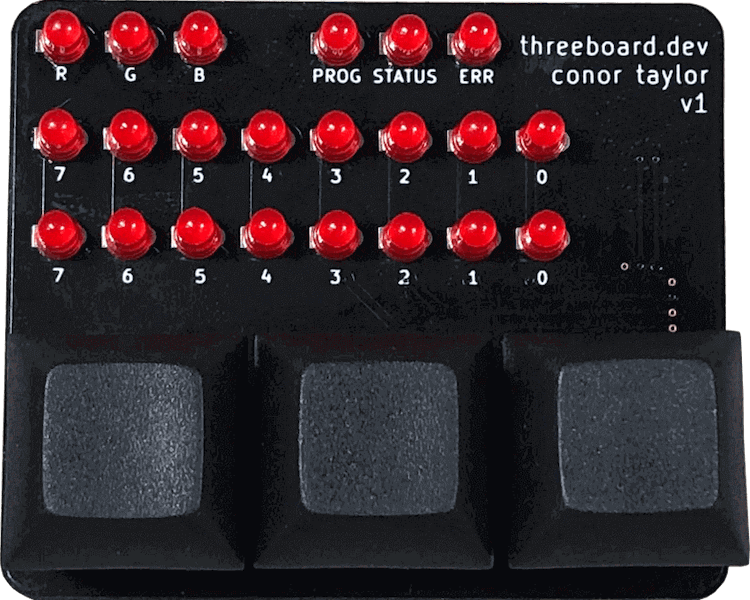
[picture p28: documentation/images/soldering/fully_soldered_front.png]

</p>

## Soldering
The components required to assemble the threeboard are all listed in the [component list](component_list.md) document. These all need to be soldered to the threeboard’s PCB, and the microcontroller flashed with the threeboard firmware before it’s usable as a keyboard. All components can be soldered by hand and without a microscope, and although the two external EEPROMs and quartz crystal are much easier to solder using a hot air gun, it’s possible to solder everything using just a soldering iron.

<p align="center">
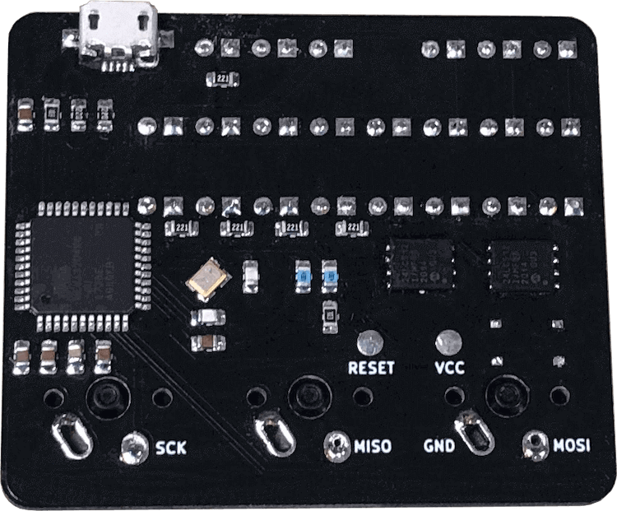
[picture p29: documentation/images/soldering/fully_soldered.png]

</p>
<br />

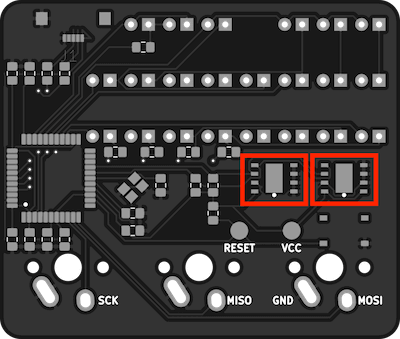
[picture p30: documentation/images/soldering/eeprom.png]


The two [24LC512-I/MF](https://www.digikey.com/en/products/detail/microchip-technology/24LC512-I-MF/523013) EEPROM devices should be soldered first as they’re the trickiest to hand-solder with a soldering iron. If they’re being soldered with a hot air gun, soldering them first prevents other nearby components from being damaged or displaced by the hot air. Solder the EEPROMs into the highlighted footprints, oriented so that their visual positioning indicators are positioned in the lower right corner.
<br clear="right"/>
<br clear="left"/>
<br />

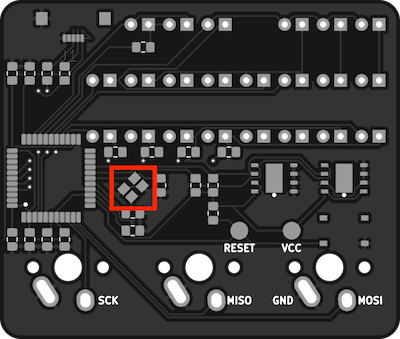
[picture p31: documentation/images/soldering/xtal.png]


The quartz crystal should be soldered next as it’s also tricky to hand-solder, and can also be hot air soldered.
<br clear="right"/>
<br clear="left"/>
<br />

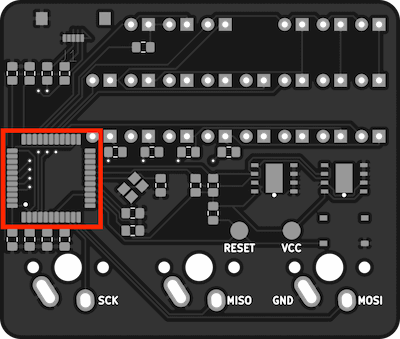
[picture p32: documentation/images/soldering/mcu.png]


The [ATMEGA32U4-AUR](https://www.digikey.com/en/products/detail/microchip-technology/ATMEGA32U4-AUR/2238241) MCU should be soldered in the highlighted area, with its visual positioning indicator in the bottom left corner.
<br clear="right"/>
<br clear="left"/>
<br />

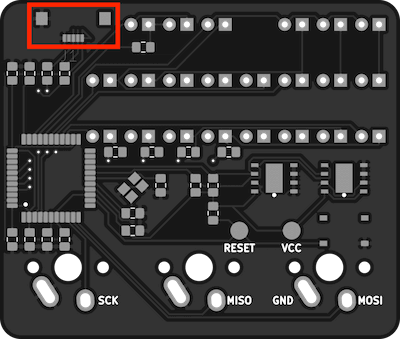
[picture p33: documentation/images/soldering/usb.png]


Solder the [USB3070-30-A](https://www.digikey.com/en/products/detail/gct/USB3070-30-A/9859704) USB socket in the highlighted area. The two larger pads on either side are not connected to anything, and just add stability to the connector, which otherwise is quite fragile. These pads can be soldered or glued. I recommend using a small amount of glue between these two pads to secure the connector. The 5 small USB pins can then be soldered once the connector is aligned and secure.
<br clear="right"/>
<br clear="left"/>
<br />

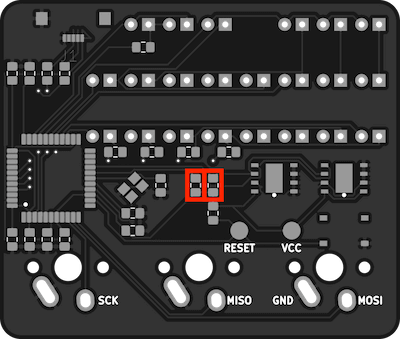
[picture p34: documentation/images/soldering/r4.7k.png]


Solder the two [RMCF0805FT4K70](https://www.digikey.ch/en/products/detail/stackpole-electronics-inc/RMCF0805FT4K70/1760659) 4.7kΩ resistors – the pull-up resistors for the EEPROMs – in the highlighted areas.
<br clear="right"/>
<br clear="left"/>
<br />

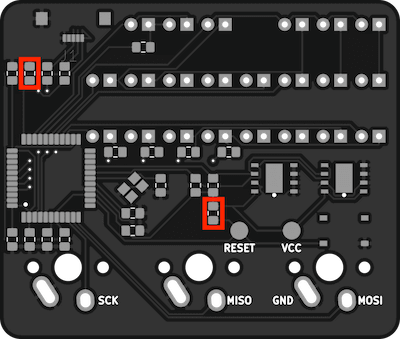
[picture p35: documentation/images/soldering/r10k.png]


The two [RMCF0805JT10K0](https://www.digikey.com/en/products/detail/stackpole-electronics-inc/RMCF0805JT10K0/1942577) 10kΩ resistors are used as a pull-up resistor for the MCUs RESET pin and a pull-down resistor to inform the MCU to check for USB activity during boot. They should be soldered in the highlighted areas.
<br clear="right"/>
<br clear="left"/>
<br />

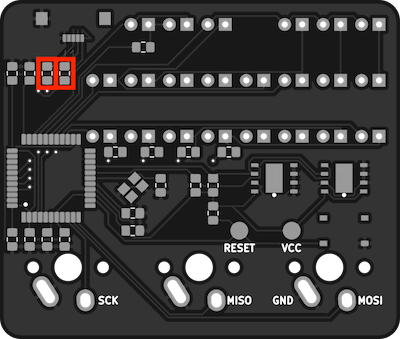
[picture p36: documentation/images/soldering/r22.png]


Solder the two [RMCF0805JT22R0](https://www.digikey.com/en/products/detail/stackpole-electronics-inc/RMCF0805JT22R0/1942533) 22Ω resistors in the highlighted areas. These are serially connected between the USB data lines and the MCU.
<br clear="right"/>
<br clear="left"/>
<br />

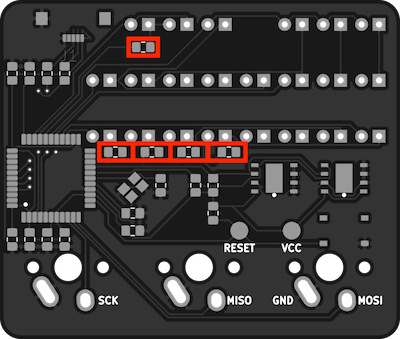
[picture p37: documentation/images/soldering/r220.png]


There are five 220Ω resistors needed to protect the LED banks. They should be soldered in the highlighted areas.
<br clear="right"/>
<br clear="left"/>
<br />

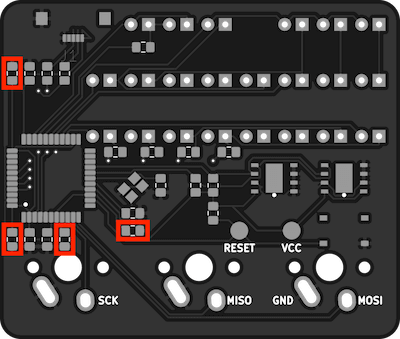
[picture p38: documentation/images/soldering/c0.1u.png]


Solder the four [CC0805ZRY5V9BB104](https://www.digikey.com/en/products/detail/yageo/CC0805ZRY5V9BB104/2103145) 0.1uF decoupling capacitors in the areas highlighted.
<br clear="right"/>
<br clear="left"/>
<br />

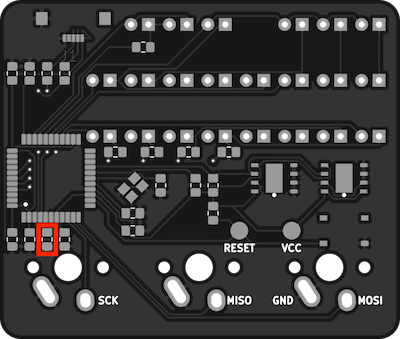
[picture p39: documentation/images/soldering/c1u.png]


A 1uF capacitor is needed to regulate the USB output supply voltage. Solder the [CC0805KKX7R7BB105](https://www.digikey.com/en/products/detail/yageo/CC0805KKX7R7BB105/2103149) capacitor in the highlighted area.
<br clear="right"/>
<br clear="left"/>
<br />

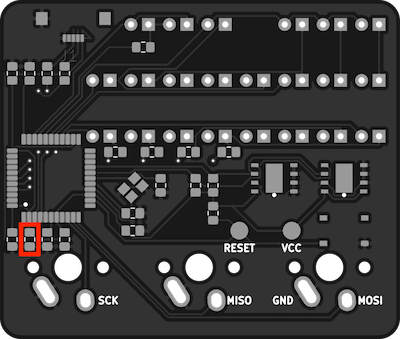
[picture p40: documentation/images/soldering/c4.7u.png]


Solder the [CC0805ZRY5V6BB475](https://www.digikey.com/en/products/detail/yageo/CC0805ZRY5V6BB475/2103155) 4.7µF decoupling capacitor in the highlighted area.
<br clear="right"/>
<br clear="left"/>
<br />

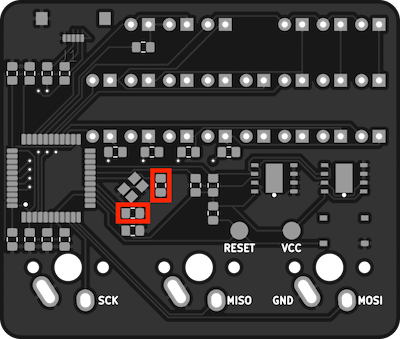
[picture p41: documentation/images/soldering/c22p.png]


The two [C0805C220J5GACTU](https://www.digikey.com/en/products/detail/kemet/C0805C220J5GACTU/411112) 22pF external clock crystal capacitors should be soldered as shown.
<br clear="right"/>
<br clear="left"/>
<br />

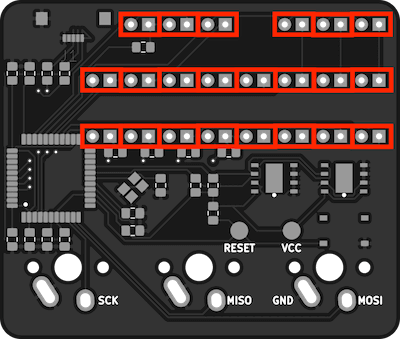
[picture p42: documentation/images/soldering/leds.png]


Solder the 22 [LTL-1CHE](https://www.digikey.com/en/products/detail/lite-on-inc/LTL-1CHE/670000) LEDs in the locations shown. Make sure to wire the cathode of the LED to the square through-hole.
<br clear="right"/>
<br clear="left"/>
<br />

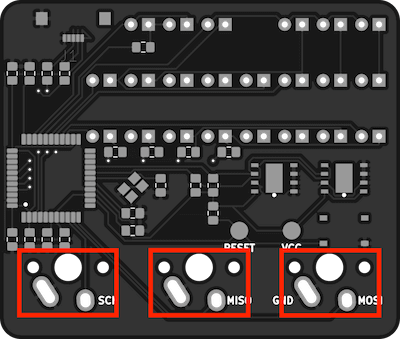
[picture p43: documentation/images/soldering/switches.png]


Solder the three Cherry MX keyswitches as shown.
<br clear="right"/>
<br clear="left"/>
<br />

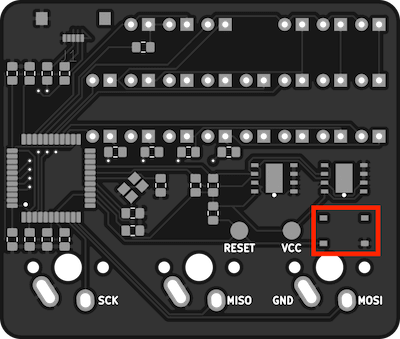
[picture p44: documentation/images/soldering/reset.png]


If needed, a [PTS526 SK08 SMTR2 LFS](https://www.digikey.com/en/products/detail/c-k/PTS526-SK08-SMTR2-LFS/10056632) push-button RESET switch can be soldered in the highlighted area. This is only needed when flashing threeboard firmware to the threeboard using a USB bootloader. It may only be needed once, or not needed at all if flashing using SPI.
<br clear="right"/>
<br clear="left"/>
<br />

## Flashing firmware
A freshly constructed threeboard will need to have a [bootloader](https://en.wikipedia.org/wiki/Bootloader) installed before it’s possible to flash the threeboard firmware. For simplicity I suggest installing the Arduino USB bootloader using an [Arduino as an ISP programmer](https://www.arduino.cc/en/Tutorial/BuiltInExamples/ArduinoISP) and following [this guide](https://learn.sparkfun.com/tutorials/installing-an-arduino-bootloader/all). The necessary SPI pins are all labelled on the threeboard: `RESET`, `VCC`, `SCK`, `MISO`, `GND` and `MOSI`. These should be connected to the corresponding pins on the ISP programmer to flash the bootloader.

A threeboard hex file is required to flash the firmware to the device. This is produced by running `bazel build //src:threeboard_hex` from the `threeboard/firmware` directory. Once the threeboard hex file has been successfully built, it can be flashed to the device using the following command:
```
avrdude -v -patmega32u4 -cavr109 -P /dev/cu.usbmodemXXX -b57600 -D -Uflash:w:bazel-bin/src/threeboard_hex.hex:i
```

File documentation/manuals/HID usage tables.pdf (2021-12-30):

# HID Usage Tables

## FOR

# Universal Serial Bus (USB)

Version 1.21

1996-2020 USB Implementers’ Forum—All rights reserved.

# Contributors

Contributor | Company
Abdulkarim Ali | Aristocrat Technologies Australia
Shubhalakshmi Amin | Microsoft Corp.
Brian M. Bates | ELO Touchsystems
Gopu Bhaskar | Apple Inc.
Fred Bhesania | Microsoft Corp.
Calai Bhoopathi | SCM Micro
Anton Cheng | Intel Corp.
Robert Dezmelyk | LCS/Telegraphics
Andrew Dye | Microsoft Corp.
Karthik Elangovan | Microsoft Corp.
Dan Ellis | Displaylink
Dave Fleck | Wacom Technology Corp
Yevgen Goryachok | Apple Inc.
Ke A Han | Intel Corp.
Pranav Hippargi | Microsoft Corp.
Robert Hulvey | Broadcom Corp
Robert Ingman | Microsoft Corp.
Slim Jallouli | ST Microelectronics
Bo Kang | ST Microelectronics
Mark Lavelle | Logitech
Rob Lieb | Symbol Technologies Inc.
Kevin Lynch | Synaptics Inc
Steve McGowan | Intel Corp.
Rouella Mendonca | Microsoft Corp.
Sean O’Brien | Google LLC.
Mark A. Overby | NVIDIA Corp.
Juan J. Perez | Microsoft Corp.
Richard Petrie | Nokia
Kenneth Ray | Microsoft Corp.
Denny Rönngren | Tobii AB
Steve Schumacher | LCS/Telegraphics
Nathan C. Sherman | Microsoft Corp.
Alex Shows | Dell
Don Stern | TV Interactive
Dmitry Torokhov | Google LLC.
Reed Townsend | Microsoft Corp.
Jim Trethewey | Intel Corp.
Mike Van Flandern | Microsoft Corp.
Larry Weiss | Microsoft Corp.

Matthew I. Williams (Chair) | Microsoft Corp.
Michael Wright | Google LLC.
Roberto Yepez | Apple Inc.
Remy Zimmerman | Logitech

# Revision History

Revision | Issue Date | Comments
1.21 | October 12, 2020 | Incorporate HUT Review Request 98.
1.2 | July 29, 2020 | Incorporate HUT Review Request 28, 29, 30, 31, 32, 33, 34, 35, 36,37, 38, 39, 40, 41, 42, 44, 45, 46, 47, 48, 49, 50, 51, 52, 53, 54, 55, 56, 57, 59, 60, 61, 62, 63, 64, 67, 68, 69, 70, 71, 72, 73, 74, 75, 76, 77, 78, 79, 81, 82, 83, 84, 85, 87, 88, 89, 90, 91, 92, 93, 94, 95, 96, 97.
1.13 | May 29, 2020 | Updating Intellectual Property Disclaimer.
1.12rc1 | October 28, 2004 | Incorporate HUT Review Request 20, 21, 22, 23, 24, 25, 27, and 29
1.11 | June 27, 2001 | Version 1.11 release
1.11rc1 | August 7, 2000 | Incorporate HUT Review Request 1, 2, 3, 4, 5, 6, 7, 8, 9, 11, 13, 14, 15,16, 17, and 18.
1.1 | April 8, 1999 | Version 1.1 release
1.1rc3 | February 16, 1999 | Correct barcode Usage Page ID. Corrected page numbering.
1.1rc2 | January 21, 1999 | Incorporate HID Review Request 51.
1.1rc1 | October 13, 1998 | Incorporate Keyboard Usage Table from the 1.0 HID Specification and HID Review Requests 16, 34, 38, 40, 41, 42, 43, 45, 46, 48 and 49.
1.0 | October 30, 1997 | Version 1

# Copyright

Copyright © 1996-2020, USB Implementers Forum

All rights reserved.

INTELLECTUAL PROPERTY DISCLAIMER

THIS SPECIFICATION IS PROVIDED “AS IS” WITH NO WARRANTIES WHATSOEVER INCLUDING ANY WARRANTY OF MERCHANTABILITY, FITNESS FOR A PARTICULAR PURPOSE, OR ANY WARRANTY OTHERWISE ARISING OUT OF ANY PROPOSAL, SPECIFICATION, OR SAMPLE.

TO THE MAXIMUM EXTENT OF USB IMPLEMENTERS FORUM’S RIGHTS, USB IMPLEMENTERS FORUM HEREBY GRANTS A LICENSE UNDER COPYRIGHT TO REPRODUCE THIS SPECIFICATION FOR INTERNAL USE ONLY (E.G., ONLY WITHIN THE COMPANY OR ORGANIZATION THAT PROPERLY DOWNLOADED OR OTHERWISE OBTAINED THE SPECIFICATION FROM USB IMPLEMENTERS FORUM, OR FOR AN INDIVIDUAL, ONLY FOR USE BY THAT INDIVIDUAL). THIS SPECIFICATION MAY NOT BE REPUBLISHED EXTERNALLY OR OTHERWISE TO THE PUBLIC.

IT IS CONTEMPLATED THAT MANY IMPLEMENTATIONS OF THIS SPECIFICATION (E.G., IN A PRODUCT) DO NOT REQUIRE A LICENSE TO USE THIS SPECIFICATION UNDER COPYRIGHT. FOR CLARITY, HOWEVER, TO THE MAXIMUM EXTENT OF USB IMPLEMENTERS FORUM’S RIGHTS, USB IMPLEMENTERS FORUM HEREBY GRANTS A LICENSE UNDER COPYRIGHT TO USE THIS SPECIFICATION AS REASONABLY NECESSARY TO IMPLEMENT THIS SPECIFICATION (E.G., IN A PRODUCT).

NO OTHER LICENSE, EXPRESS OR IMPLIED, BY ESTOPPEL OR OTHERWISE, TO ANY PATENT OR OTHER INTELLECTUAL PROPERTY RIGHTS IS GRANTED OR INTENDED HEREBY.

USB IMPLEMENTERS FORUM AND THE AUTHORS OF THIS SPECIFICATION DISCLAIM ALL LIABILITY, INCLUDING LIABILITY FOR INFRINGEMENT OF PROPRIETARY RIGHTS, RELATING TO IMPLEMENTATION OF INFORMATION IN THIS SPECIFICATION. AUTHORS OF THIS SPECIFICATION ALSO DO NOT WARRANT OR REPRESENT THAT SUCH IMPLEMENTATION(S) WILL NOT INFRINGE SUCH RIGHTS.

All product names are trademarks, registered trademarks, or service marks of their respective owners.

Please send comments via electronic mail to hidcomments‘at’usb.org, us the @ sign for ‘at’.

# Contents

1 | Introduction | 13
2 | Management Overview | 14
3 | Usage Pages | 15
4 | Generic Desktop Page (0x01) | 30

4.14 Spatial Controls | 50
4.15 Dockable Devices | 52
5 | Simulation Controls Page (0x02) | 54
5.1 | Sports Simulation Device | 56
5.2 | Flight Simulation Devices | 57
5.3 | Automobile Simulation Devices | 60
5.4 | Tank Simulation Devices | 61
5.5 | Maritime Simulation Devices | 62
5.6 | Two-wheeled Simulation Devices | 63
5.7 | Miscellaneous Simulation Devices | 64
6 | VR Controls Page (0x03) | 65
6.1 | VR Control Devices | 66
6.2 | VR Controls | 67
7 | Sport Controls Page (0x04) | 68
7.1 | Stick Devices | 69
7.2 | Exercise Machines | 70
8 | Game Controls Page (0x05) | 71
8.1 | 3D Game Controller | 72
8.2 | Pinball Device | 74
8.3 | Gun Device | 75
8.4 | Gamepads | 76
8.4.1 | Gamepad Button Collections | 76
9 | Generic Device Controls Page (0x06) | 77
9.1 | Background/Nonuser Controls | 78
9.2 | Device Controls | 79
9.3 | Versioning | 80
9.4 | Device Grip Controls | 81
10 Keyboard/Keypad Page (0x07) | 82
11 LED Page (0x08) | 90
11.1 Keyboard Indicators | 93
11.2 Telephony Indicators | 94
11.3 Consumer Indicators | 95
11.4 Media Transport Indicators | 96
11.5 Printer Indicators | 97
11.6 General Device Indicators | 98
11.7 Multicolor (RGB) LED | 100
11.8 Game Player Indicators | 101
12 Button Page (0x09) | 102
13 Ordinal Page (0x0A) | 103
14 Telephony Device Page (0x0B) | 104
14.1 Telephony Devices | 107
14.2 Telephony Key Pad Usages | 108
14.3 Call Control | 109
14.4 Speed Dial Controls | 110
14.5 Voice Mail Controls | 111
14.6 Locally Generated Tones | 112
14.7 Call History Controls | 113
14.8 Host Dual Mode Phone Controls | 114

14.9 Ring Reports | 115
14.10 Call History Reports | 116
15 Consumer Page (0x0C) | 117
15.1 Generic Consumer Control Device | 129
15.2 Numeric Key Pad | 130
15.3 General Controls | 131
15.4 Menu Controls | 132
15.5 Display Controls | 133
15.6 Selection Controls | 134
15.7 Transport Controls | 136
15.8 Search Controls | 137
15.9 Audio Controls | 138
15.9.1 Volume | 138
15.9.2 Balance | 138
15.9.3 Bass | 138
15.9.4 Treble | 139
15.9.5 Other | 139
15.10 Speed Controls | 140
15.11 Home and Security Controls | 141
15.12 Speaker Channels | 142
15.12.1 Audio Channels | 142
15.13 PC Theatre | 144
15.14 Programmable Buttons | 145
15.15 Application Launch Buttons | 146
15.16 Generic GUI Application Controls | 149
15.17 Contact List Controls | 153
15.18 Descriptive Controls | 154
15.19 Input Assist Selectors | 156
15.20 Game Recording Controls | 157
15.21 Access Controls | 158
15.22 Keyboard Backlight Controls | 159
15.23 Privacy Screen Controls | 160
16 Digitizers Page (0x0D) | 161
16.1 Digitizer Devices | 164
16.2 Digitizer Transducer Collections | 165
16.3 Digitizer Report Fields | 166
16.3.1 Digitizer-Specific Fields | 166
16.3.2 Tilt Orientation | 168
16.3.3 Azimuth-Altitude Orientation | 168
16.4 Digitizer Switch Usages | 169
16.5 Touch Digitizer Usages | 170
16.6 Multi-touch Digitizer Usages | 171
16.7 Device Configuration Usages | 172
16.8 Character Gesture Usages | 173
16.9 Heat Map Usages | 174
17 Haptics Page (0x0E) | 175
17.1 Simple Haptic Controller | 176
17.2 Simple Haptic Controller Operation | 178
17.2.1 Lists | 178
17.2.2 Waveforms | 178
17.2.2.1 Required Waveforms | 178
17.2.2.2 Vendor Waveforms | 178
17.2.3 Duration of Waveforms | 178
17.2.3.1 Continuous Waveforms | 179

17.2.4 Triggers | 179
17.2.4.1 Auto Mode Trigger Association | 179
17.2.4.2 Retriggering | 180
17.2.4.3 Intensity | 180
18 Unicode Page (0x10) | 181
19 Eye and Head Trackers Page (0x12) | 182
19.1 Eye/Head Trackers | 184
19.2 Capabilities Collection | 185
19.3 Tracking Distance | 186
19.4 Maximum Screen Plane | 187
19.5 Configuration Collection | 188
19.6 Status Collection | 189
19.7 Control Collection | 190
20 Auxiliary Display Page (0x14) | 191
20.1 Alphanumeric Display | 194
20.1.1 Flags | 194
20.1.2 Display Control | 197
20.1.3 Scrolling | 197
20.1.4 Character Transfers | 198
20.1.5 Display Status | 199
20.1.6 Cursor Control | 199
20.1.7 Font Loading | 200
20.1.8 Character Formats | 201
20.1.8.1 Matrix | 201
20.1.8.2 7-Segment | 202
20.1.8.3 14-Segment | 203
20.2 Bitmapped Display | 204
20.2.1 Display Attributes Report | 204
20.2.1.1 Display Specification | 204
20.2.1.2 Bit Depth Format | 204
20.2.1.3 Monochrome and Indexed Formats | 204
20.2.1.4 RGB Formats | 205
20.2.1.5 Soft Buttons | 206
20.2.2 Orientation | 207
20.2.3 Palette Report | 207
20.2.4 Blit Report | 208
20.2.5 Soft Button Report | 208
20.3 Character Maps | 209
20.4 Requesting Reports | 210
21 Sensors Page (0x20) | 211
21.1 Sensor Device Usages | 231
21.2 Modifiers | 238
21.3 Sensor State Event Usages | 240
21.4 Sensor Event Usages | 241
21.5 Generic Sensor Property Usages | 242
21.5.1 Property: Sensor Connection Types | 244
21.5.2 Property: Reporting State | 244
21.5.3 Property: Power State | 244
21.5.4 Property: Sensor Batching Controls | 245
21.6 Biometric Sensor Field Usages | 246
21.7 Electrical Sensor Field Usages | 247
21.8 Environmental Sensor Usages | 248
21.9 Light Sensor Usages | 249

21.10 Location Sensor Field Usages | 251
21.10.1 Location Desired Accuracy | 252
21.10.2 Fix Quality | 253
21.10.3 Fix Type | 253
21.10.4 GPS Operation Mode | 253
21.10.5 GPS Selection Mode | 253
21.10.6 GPS Status | 254
21.11 Mechanical Sensor Field Usages | 255
21.12 Motion Sensor Field Usages | 256
21.13 Orientation Sensor Field Usages | 258
21.13.1 Magnetometer Accuracy | 260
21.13.2 Simple Orientation Direction | 260
21.14 Scanner Sensor Field Usages | 261
21.15 Time Sensor Field Usages | 262
21.15.1 Day of Week | 262
21.16 Custom Sensor Field Usages | 264
21.17 Custom Sensor Property Usages | 266
21.18 Generic Sensor Field Usages | 267
21.18.1 Generic GUID or PROPERTYKEY kind | 268
21.18.2 Generic Firmware VARTYPE | 268
21.18.3 Generic Unit of Measure | 269
21.18.4 Generic Unit Exponent | 270
21.19 Personal Activity Sensor Field Usages | 272
21.19.1 Activity Types | 272
21.19.2 Activity State | 273
21.19.3 Device Position | 273
21.19.4 Step Type | 273
21.20 Foldable Device Usages | 274
21.20.1 Hinge Sensors | 274
21.20.2 Gesture Sensors | 274
21.20.2.1 Chassis Flip Gesture | 274
21.20.2.2 Hinge Fold Gesture | 275
21.20.2.3 Gesture Sensor Usages | 275
21.20.2.4 Gesture State Usages | 275
21.20.2.5 Hinge Fold Contributing Panel Usages | 276
21.20.2.6 Hinge Fold Type Usages | 276
22 Medical Instrument Page (0x40) | 277
22.1 Ultrasound Devices | 278
22.2 Acquisition Controls | 279
22.3 Signal Modulation | 280
22.4 Acquisition and Display Mode Controls | 281
23 Braille Display Page (0x41) | 282
23.1 Braille Display Device | 284
23.2 Braille Cells | 285
23.3 Routers | 286
23.4 Braille Buttons | 287
23.5 Screen Reader Control | 288
23.6 Screen Reader Identifier | 289
24 Lighting And Illumination Page (0x59) | 290
24.1 Application Usages | 291
24.2 LampArray Attributes Report | 292
24.2.1 LampArrayKind Values | 292
24.3 Lamp Attributes Report | 293
24.3.1 LampPurposes Flags | 293

24.4 Lamp Update Reports | 294
24.4.1 LampUpdate Flags | 294
24.5 LampArray Control Report | 295
24.6 LampArray Operation | 296
24.7 LampArray Attributes and Interrogation | 297
24.8 Lamp Attributes and Interrogation | 299
24.8.1 LampAttributesRequestReport | 299
24.8.2 LampAttributesResponseReport | 299
24.8.2.1 Example | 299
24.8.3 Lamp Attributes | 300
24.9 Color Attributes | 303
24.9.1 Color Attributes Examples | 303
24.10 LampArrayControlReport | 304
24.10.1 AutonomousMode | 304
24.11 Updating Lamp State | 305
24.11.1 LampMultiUpdateReport | 305
24.11.2 LampRangeUpdateReport | 306
25 Camera Control Page (0x90) | 307
25.1 Camera Controls | 308
26 Gaming Device Page (0x92) | 309
27 FIDO Alliance Page (0xF1D0) | 310
27.1 Application Usages | 311
Appendix A Indices for 8bit Preferred Colors | 312
References | 316

# List of Tables

3.1 | Usage Page Summary | 16
3.2 | Usage Types (Controls) | 20
3.3 | Usage Types (Data) | 22
3.4 | Usage Types (Collection) | 24
3.5 | String Descriptor | 27
3.6 | LANGID Format | 27
3.7 | GetDescriptor(String) Request | 28
3.8 | HID Sublanguage IDs | 28
3.9 | Usage Data Descriptor | 28
3.10 Vendor Defined Descriptor | 29
4.1 | Generic Desktop Page | 32
5.1 | Simulation Controls Page | 55
6.1 | VR Controls Page | 65
7.1 | Sport Controls Page | 68
8.1 | Game Controls Page | 71
9.1 | Generic Device Controls Page | 77
11.1 LED Page | 92
12.1 Button Page | 102
13.1 Ordinal Page | 103
14.1 Telephony Device Page | 106
15.1 Consumer Page | 128
15.3 Graphic Equalizer Data Descriptor | 129
16.1 Digitizer Page | 163
17.1 Haptics Page | 175
17.3 Trigger Behavior by Definition | 179
19.1 Eye and Head Trackers Page | 183
20.1 Auxiliary Display Page | 193
20.4 ASCII Display Character Set | 196
20.5 7-Segment Direct Mapping Data | 196
20.6 14-Segment Direct Mapping Data | 196
20.7 Display Data Extended Character Codes | 197
20.15 Example 7-Segment Font values for Hex digits | 202
20.16 14-Segment Font Data | 203
20.28 Page Mapping Definitions | 209
21.1 Sensors Page | 230
22.1 Medical Instrument Page | 277
23.1 Braille Display Page | 283

25.1 Camera Control Page | 307
27.1 Fast IDentity Online Alliance Page | 310

# 1 Introduction

Usages are part of the HID Report descriptor and supply an application developer with information about what a control is actually measuring or reporting. In addition, a Usage tag can be used to indicate the vendor’s suggested use for a specific control or group of controls. While most of the items within a Report descriptor describe the format of the data (e.g. three 8-bit fields) the Usage tags define what should be done with the data (e.g x, y, and z input). This feature allows a vendor to ensure that the user sees consistent function assignments to controls across applications. It is also the key feature within HID Report descriptors that allows system or application software to know the meaning of data items, or collections of data items, so the data items can be correctly interpreted or routed to the system or application software that consumes them.

## Purpose

This document defines constants that can be interpreted by an application to identify the purpose and meaning of a data field in a HID report.

Usages are also used to define the meaning of groups of related data items. This is accomplished by the hierarchical assignment of Usage information to collections. Usages identify the purpose of a collection and the items it contains. Each Input, Output, Feature, and/or Collection data item within a Collection item can be assigned a purpose with its own Usage item. Usages assigned to a collection apply to the items within the collection.

In some cases a Usage applied to a collection can redefine the meaning of the Usages it contains. An example of this is the Usage Selected Indicator on the LED page.

Usages are also used to specify the meaning of each element within an Array data item.

## Terms and Abbreviations

Term | Description
Application | A software program that consumes the data generated by the HID device Input reports, or that controls the HID device through Feature or Output reports. Applications can be games or other programs used by end users or system software components.
Array field | The bit field created by an Input, Output, or Feature main item which is declared as an Array. An array field contains the index of a Usage, not the Usage value.
Control | A control is used to operate or regulate a particular aspect of a device. In this document a control refers broadly to the physical entity on the device that the Usage identifies.
Field | The Input, Output, and Feature main items create a bit field in a report. The Report Size determines the field’s width and the associated Usage determines the field’s purpose. The offset of a field in a report is determined by the fields that are declared before it.
Pad | If a field is marked as a constant and there is no Usage associated with it, the field will be treated as pad bits and ignored by host software.
| Note: Fields created by Main items that do not have Usages attached to them might not be accessible by applications. Whether such access is possible depends on the implementation of the HID device driver.
Usage | Defines the purpose or meaning of an item.

# 2 Management Overview

This document provides lists of Usages and their descriptions that significantly extend the list of Usages provided in the HID Specification. A HID Usage communicates the intended function or meaning of a particular control. Usages provide a description of the data items in a HID device’s Input, Output, and Feature reports. The existence of a defined Usage does not guarantee that system or application software will recognize or utilize the data item. Although Usages can be very powerful, there is a potential for misuse. The detail provided in this document will help minimize the misuse or misinterpretation of Usages when they are applied by a device developer.

Usages have been organized into pages of related controls. Each Usage has a Usage ID, Usage name and a detailed description. The Usage names are mnemonics, not definitions. To avoid misleading interpretations based on the Usage name, it is very important that a developer review a Usage’s description in detail to ensure that it properly identifies the purpose of the control or device that the Usage is attached to.

In theory, a Usage can be attached to any type of HID control, variable, array, collection, and so forth. In reality, Usages only make sense when they are attached to particular controls and used in certain ways. A relatively small set of Usage types have been defined to help the application software developer better understand what to expect when a particular Usage is found. Each Usage has a Usage type associated with it. The Usage type identifies the item types, flag settings and bit fields organizations that are found with a particular Usage.

Usages can also identify functional devices as a whole, thus providing an easy method for an application to identify devices that provide functions of interest. Such Usages are found attached to application collections that are wrapped around all the items that describe a particular functional device, or a particular function in a complex device. Generally an application will query the HID driver for all application collection Usages that it knows pertain to it. For example, a gaming device driver might look for Joystick and Game Pad Usages, while a system mouse driver might look for Mouse, Digitizer Tablet and Touch Screen Usages.

As a general rule, the Usages selected by a device developer should be specific enough to dissuade inappropriate use by applications while remaining general enough to allow applications to take advantage of device features if they can. If uncertain, favor the more general Usage to encourage broader application support for your device. An alternative is to use delimiters to define multiple Usages associated with a single control or a device.

Some Usage pages that are in the HID Specification are also found in this document. They are included here because either additional text has been provided to clarify how the Usages are to be used, new Usages have been added to the page, or both. No changes have been made to the Usage values assigned in the HID Specification.

# 3 Usage Pages

The following table lists the currently defined Usage Pages and the section in this document or the specification where each page is described.

Page ID | Page Name | Section or Document
00 | Undefined
01 | Generic Desktop Page (0x01) | 4
02 | Simulation Controls Page (0x02) | 5
03 | VR Controls Page (0x03) | 6
04 | Sport Controls Page (0x04) | 7
05 | Game Controls Page (0x05) | 8
06 | Generic Device Controls Page (0x06) | 9
07 | Keyboard/Keypad Page (0x07) | 10
08 | LED Page (0x08) | 11
09 | Button Page (0x09) | 12
0A | Ordinal Page (0x0A) | 13
0B | Telephony Device Page (0x0B) | 14
0C | Consumer Page (0x0C) | 15
0D | Digitizers Page (0x0D) | 16
0E | Haptics Page (0x0E) | 17
0F | PID Page | USB Physical Interface Device (https://www.usb.org/sites/default/files/documents/pid1_01.pdf) definitions for force feedback and related devices.
10 | Unicode Page (0x10) | 18
11-11 | Reserved
12 | Eye and Head Trackers Page (0x12) | 19
13-13 | Reserved
14 | Auxiliary Display Page (0x14) | 20
15-1F | Reserved
20 | Sensors Page (0x20) | 21
21-3F | Reserved
40 | Medical Instrument Page (0x40) | 22
41 | Braille Display Page (0x41) | 23
42-58 | Reserved
59 | Lighting And Illumination Page (0x59) | 24
5A-7F | Reserved
80-83 | Monitor Pages | USB Device Class Definition for Monitor Devices (https://www.usb.org/sites/default/files/documents/usbmon10.pdf)
84-87 | Power Pages | USB Device Class Definition for Power Devices (https://www.usb.org/sites/default/files/documents/pdcv10.pdf)
88-8B | Reserved
8C | Bar Code Scanner page | USB Device Class Definition for Point of Sale Devices (https://usb.org/sites/default/files/documents/pos1_02.pdf)

8D | Scale page | USB Device Class Definition for Point of Sale Devices (https://usb.org/sites/default/files/documents/pos1_02.pdf)
8E | Magnetic Stripe Reading (MSR) Devices | USB Device Class Definition for Point of Sale Devices (https://usb.org/sites/default/files/documents/pos1_02.pdf)
8F | Reserved Point of Sale pages | USB Device Class Definition for Point of Sale Devices (https://usb.org/sites/default/files/documents/pos1_02.pdf)
90 | Camera Control Page (0x90) | 25
91 | Arcade Page | OAAF Definitions (https://www.usb.org/sites/default/files/documents/oaaddataformatsv6.pdf) for arcade and coinop related Devices
92 | Gaming Device Page (0x92) | 26
93-F1CF | Reserved
F1D0 | FIDO Alliance Page (0xF1D0) | 27
F1D1-FEFF | Reserved
FF00-FFFF | Vendor-defined
Table 3.1: Usage Page Summary

A bold Usage definition in the following sections identifies a collection. Non-bold definitions are specific features related to a device that would be applied to individual controls that generate data. In many cases, specific Usages can be used by a number of device types.

## 3.1 HID Usage Table Conventions

Usage ID 0 should always be reserved.

Usage ID 1 through 0x1F are reserved for top level collections. These Usage IDs are not necessarily application-level but are used to identify general device types.

Usage page values are limited to 16 bits.

Usage ID values are limited to 16 bits.

Usages are 32-bit identifiers, where the high order 16 bits represents the Usage page and the low order 16 bits represents the Usage ID. To allow more compact Report descriptors, Usage Page items can be declared to specify the high order bits of the Usage item and the Usage items can declare only the ID portion of the Usage, as follows:

- If the bSize field of the Usage item equals 1 or 2, the entire 1- or 2-byte data portion of the item is interpreted as a Usage ID.
- If the bSize field equals 3, bits 16-31 of the 4-byte data portion of the item are interpreted as a Usage page, and bits 0-15 of the data portion are interpreted as a Usage ID. This interpretation of Usages applies to Usage, Usage Minimum, and Usage Maximum items.

The notation for a 32-bit Usage (sometimes called an extended Usage) in the examples is:

Usage(Usage Page: Usage ID).

## 3.2 Handling Unknown Usages

If a Usage is unknown to an application then the application should ignore it.

If the Usage attached to a collection is unknown to an application, then the application should ignore the collection and all Usages contained in the collection. A collection can be used to modify the meaning of the Usages that it contains, therefore known Usages within an unknown collection may not represent their original meaning. An example of this is the Usage Selected Indicator on the LED page.

System software provides capabilities for parsing HID Report descriptors. In some cases the Usage associated with the top level application collection can be used by the system software as a key to load an application-specific driver or a mapping driver for legacy compatibility.

## 3.3 Usages and Units

For Usages that declare data items as a measurement of time, distance, force, and so forth, an application must look at the units to properly interpret the value defined by a Usage, unless:

1. The Usage specifically declares Units as optional.
2. The Usage description defines the units in which the value will be presented.

If Units are set to Optional or set to None (have not been declared) then an application can assume the Usage represents a dimensionless value. Any application that ignores Units does so at its own risk.

A Usage that declares itself to be a measurement of time would specify whether it was seconds or milliseconds by declaring Units and Unit Exponent prior to the respective Main item declaration. An example of this is the Flash On Time Usage on the LED page, which is described as the duration that the indicator is illuminated in flash mode. The duration would be qualified by the values of Units and Unit Exponent.

When declaring Units for a main item, the Logical Minimum, Logical Maximum, Physical Minimum, Physical Maximum, and Unit Exponent items must also be declared.

Note: In many cases the coordinate system assumes that the values can vary both positively and negatively from zero (0).

## 3.4 Usage Types

Usages define a wide variety of device features. However, the way an application treats the data that they generate falls into a relatively small set of categories. This section provides descriptions of frequently used types of Usages, primarily to save redundant text throughout this document. This list is not an exhaustive list of the possible Usage Types. Individual Usage pages can declare their own Usage Types.

Each Usage Type describes how an application should treat the data generated by the Main item that the Usage is attached to.

Usage Type names are followed by an abbreviation that is used in the detailed Usage description to identify the default type of a Usage. In some cases Usage Types do not apply and the detailed description will identify how the Usage is to be interpreted.

There are three basic types of information that are described by Usages: controls, collections, and data. In this context, controls are identified with the state of a device (on/off, enable/disable, and so forth), collections group related controls and data together, and data comprises the remaining information that is passed between a device and the host.

Note: Usage Types are always considered to be the recommended method of handling a Usage. Consult the Usage’s definition to determine whether alternative Usage Types may apply.

### 3.4.1 Usage Types (Controls)

The following table summarizes the control related Usage Types.

Control
Type

Logical
Min

Logical
Max
Flags | Signal | Operation

Linear
Control (LC)
-1 | 1 | Relative, Preferred State
Edge | 1 increments the control’s value.
-1 decrements the control’s value.
-Min | Max | Relative, Preferred State
Level | n increments the control’s value,
-n decrements the control’s value.
Min | Max | Absolute, Preferred State
N/A | The value reported by the control is used
directly by the host.

On/Off
Control
(OOC)
-1 | 1 | Relative,
No Preferred

Edge 1 asserts an On condition. –1 asserts an Off condition.
0 | 1 | Relative,
Preferred State

Edge A 0 to 1 transition toggles the current On/Off state.

0 | 1 | Absolute,
No Preferred

Level 1 asserts an On condition. 0 asserts an Off condition. Momentary
Control (MC)
0 | 1 | Absolute,
Preferred State

Level 1 asserts a condition. 0 deasserts the condition.

One Shot
Control
(OSC)
0 | 1 | Relative,
Preferred State

Edge A 0 to 1 transition triggers an event. A 1 to 0 transition must occur before another event can be triggered.

Re-trigger
Control
(RTC)
0 | 1 | Absolute,
Preferred State
Level | 1 triggers an event. | When an event
completes, if the value is 1 then the event will be triggered again.

Table 3.2: Usage Types (Controls)

### 3.4.1.1 Linear Control (LC)

In many cases, a control of a linear value is implemented as a pair of increment/decrement buttons, a jog wheel, or a linear control such as a knob or a slide.

When implemented as an increment/decrement control, the two buttons must be translated into a single, 2-bit signed value and declared as a Relative Main item with a Report Size equal to 2, where –1 decrements the value, +1 increments it, and no change occurs when 0 is asserted.

A jog wheel is normally implemented as a spring-loaded knob that returns to a fixed center position when released. This control reports a single value of two or more bits which are reported as a signed value and declared as a Relative Main item where ˘n decrements the value, +n increments it, and no change occurs when 0 is asserted. A jog wheel control is implemented with a resolution of +/˘n, where the offset of the knob from the center position is proportional to the reported value. The Report Size must be declared large enough to contain the signed value n.

When implemented as a linear knob or slide, the control must be declared as an Absolute Main item.

### 3.4.1.2 On/Off Control (OOC)

An On/Off Control can be implemented in any of the following ways:

- Two buttons, On and Off. The two buttons are encoded into a 2-bit signed value and declared as a Relative, No Preferred, Main item with Logical Minimum and Logical Maximum of –1 and 1, respectively. The transition from 0 to –1 generates an Off condition and the transition from 0 to +1 generates an On condition. No change occurs when 0 is asserted.
- A single button that toggles the On/Off state each time it is pressed. (single throw momentary switch) The single button is encoded into a 1-bit unsigned value and declared as a Relative, Preferred, Main item with a Logical Minimum and Logical Maximum of 0 and 1, respectively. The transition from 0 to 1 toggles the current On/Off state. No change occurs on the 1 to 0 transition.
- A toggle switch that maintains the On/Off state mechanically. (toggle switch) This control is encoded into a 1-bit unsigned value and declared as an Absolute, No Preferred, Main item with a Logical Minimum and Logical Maximum of 0 and 1, respectively. The assertion of 1 generates an On condition and the assertion of 0 generates an Off condition.

### 3.4.1.3 Momentary Control (MC)

A Momentary Control is a basic push button. A Momentary Control is encoded into a 1-bit value and declared as an Absolute, Preferred, Main item with a Logical Minimum and Logical Maximum of 0 and 1, respectively. A value of 1 generates an asserted condition and 0 generates a non-asserted condition. An example is a mouse button.

### 3.4.1.4 One Shot Control (OSC)

A One Shot Control is a push button that triggers a single event or action. A One Shot Control is encoded into a 1-bit value and declared as a Relative, Preferred, Main item with a Logical Minimum and Logical Maximum of 0 and 1, respectively. A 0 to 1 transition initiates an event. Nothing occurs on a 1 to 0 transition but it is required before another event can occur. An example is degauss.

### 3.4.1.5 Re-Trigger Control (RTC)

A Re-Trigger Control is a push button that triggers a repeating event as long as it is asserted. A Re-Trigger Control is encoded into a 1-bit value and declared as an Absolute, Preferred, Main item with a Logical Minimum and Logical Maximum of 0 and 1, respectively. A 0 to 1 transition initiates the first event. When each event terminates, if the control is still asserted (1) then another event will occur. An example is an autorepeat fire button.

### 3.4.2 Usage Types (Data)

The following table summarizes the data-related Usage Types.

Abbreviation | Type | Flags | Description
Sel | Selector | Array | Contained in a Named Array (NAry).
SV | Static Value | Constant, Variable, Absolute | A read-only multiple-bit value.
SF | Static Flag | Constant, Variable, Absolute | A read-only single-bit value.
DV | Dynamic Value | Data, Variable, Absolute | A read/write multiple-bit value.
DF | Dynamic Flag | Data, Variable, Absolute | A read/write single-bit value.

Table 3.3: Usage Types (Data)

### 3.4.2.1 Selector (Sel)

Selectors come in three forms:

- One selection of a set. Radio buttons are a mechanically linked set of buttons where one selection is always valid. This is a perfect example of the one selection of a set form. A radio button set is defined by a Main item with the Array flag set and the Report Count set to 1. The index returned in the array field corresponds to the pressed button (or selection). A Usage must be declared for each selection. The array field never returns an index of NULL because one Usage is always valid. An example is Display Status on Auxiliary Display Page (0x14).
- N selections of a set. More than one selection (button) can be valid at a time. Multiple selections can be returned to the system at one time in a multi-byte array. The n selections of a set form is defined by a Main item with the Array flag set and the Report Count set to n, where n is the number of selections that can be reported in a single report. An example is a keyboard.
- Any selection of a set. The control is implemented as a set of bit fields in which each bit represents a single selection. This control is defined by a Main item with the Variable flag set and the Report Size equal to 1. The Report Count will be equal to the number of selections in the set.

Selectors therefore can be implemented in a number of ways: Array[1] (one selection of a set), Array[n] (n selections of a set), or bitmap (any selection of a set).

Optionally, the array field or set can be named by wrapping a set of Selectors in a logical collection with a Usage attached to it. For details, see Section 3.4.3.1 Named Array (NAry)

### 3.4.2.2 Static Value (SV)

Static values are used to declare a fixed features in a device. They are defined as Constant and treated as read-only information. Therefore, asserting this field in a Set_Report command has no defined effect.

### 3.4.2.3 Static Flag (SF)

Static flags are used to declare the existence of a fixed feature in a device. If a Static Flag Usage is found in a Report descriptor then the field must be read to determine whether the feature identified by the flag exists. A value of 1 indicates existence and a value of 0 indicates non-existence. The absence of a Static Flag Usage implies that the flag is false or the feature defined by the flag is not supported by the device. A Static Flag must be declared as a Constant. To be accessible by applications, a Static Flag must have a Usage assigned to it.

Static Flags are typically declared in a Feature report as a single-bit field where the value is always read as 1. Attempting to modify this field in a Set_Report command has no effect on a Static Flag.

### 3.4.2.4 Dynamic Flag (DF)

Dynamic Flags are used to declare the existence of a host-controllable feature in a device. The absence of a Dynamic Flag Usage implies that the flag is false or the feature defined by the flag is not supported by the device.

Dynamic Flags are typically declared in a report as a single-bit field, where a value of 1 returned by the device indicates that the feature is enabled. The assertion of 1 by the host will cause the feature to be evoked and the assertion of 0 indicates that the feature is to be disabled or ignored if the feature is a one-time event (such as Degauss or Clear Display). A Dynamic Flag Main item must be declared as Data.

### 3.4.2.5 Dynamic Value (DV)

A Dynamic Value is an n-bit field that contains a value associated with a control. The associated Main item will have the Data and Variable flags set. A Dynamic Value Main item must be declared as Data.

Note: More advanced devices may allow a Usage declared as a Static type to be Dynamic. Always check the Constant/Data flag in an Input, Output or Feature Main item.

### 3.4.3 Usage Types (Collection)

The following table summarizes the collection-related Usage Types.

Abbreviation | Type | Collection Type | Description
NAry | Named Array | Logical | A collection that encompasses an array definition, naming the array set or the field created by the array.
CA | Application Collection | Application | Applies a name to a top level collection which the operating system uses to identify a device and possibly remap to a legacy API.
CL | Logical Collection | Logical | A logical collection of items.
CP | Physical Collection | Physical | A physical collection of items.
US | Usage Switch | Logical | Modifies the purpose or function of the Usages (controls) that it contains.
UM | Usage Modifier | Logical | Modifies the purpose or function of the Usages (controls) that contains it.

Table 3.4: Usage Types (Collection)

### 3.4.3.1 Named Array (NAry)

To simplify for an application the process of finding a set of selectors, whether defined as an Array Field or a bitmap, the set of selectors can be named by wrapping them in a logical collection and applying a Usage to the collection. Usages applied in this way are called Named Array Usages.

### 3.4.3.2 Collection Application (CA)

The Collection Application Usage type identifies Usages that are used only in application-level collections. An application collection identifies a HID device or a functional subset of a complex device. An operating system uses the Usage associated with this collection to link the device to its controlling application or driver. Common examples are a keyboard or mouse. A keyboard with an integrated pointing device could contain two different application collections.

Note: Data reports cannot span application collections.

### 3.4.3.3 Collection Logical (CL)

The Collection Logical Usage type identifies a Usage applied to a logical collection. Logical collections can be used to further define the purpose of the items or controls that they contain.

### 3.4.3.4 Collection Physical (CP)

The Collection Physical Usage type identifies a Usage applied to a physical collection, usually a collection of axes. A physical collection is used for a set of data items that represent data points collected at one geometric point. This is useful for sensing devices that may need to associate sets of measured or sensed data with a single point. It does not indicate that a set of data values comes from one device, such as a keyboard. In the case of a device that reports the position of multiple sensors, physical collections are used to show which data comes from which sensor.

### 3.4.3.5 Usage Switch (US)

The Usage Switch Usage type identifies a Usage applied to a logical collection that modifies the purpose of the Usages in that collection. An example is indicators. To avoid having to define a Usage for every control that could possibly use an indicator (for example, Play/Play Indicator, etc.) a Usage Switch collection can be wrapped around a Usage (Play) to create a indicator for the same function. Usage Switches often modify the type of the contained Usage as well.

### 3.4.3.6 Usage Modifier (UM)

The Usage Modifier Usage type identifies a Usage applied to a logical collection. This logical collection is always contained in another logical collection. The purpose and possibly the type of the Usage attached to the encompassing collection is modified. For instance the Usage attached to the encompassing collection may not normally be defined as a collection.

### 3.4.4 Alternate Types

Usage Types are a guide, not the rule. The flags, Logical Minimum and Logical Maximum values, and other Main item attributes must be evaluated by applications and system software to determine the true purpose, meaning, or interpretation of a control.

In many cases, a Usage can take on the attributes of a Usage type other than its default type. The alternate type can be declared by a collection in which the Usage is found or implied by the way it is declared in a Report descriptor. For example, Usage In Use Indicator from the LED page is an example of an alternate Usage type being applied to a Usage. When a Usage is wrapped in a Usage In Use Indicator collection, it becomes an On/Off Control (OOC).

In other cases, a Usage can be declared as either a Static Value (SV) or a Dynamic Value (DV). For example, in a screen saver, the Screen Saver Delay might be fixed on one device and variable on another. The same thing can happen with Usages declared as Static Flag (SF) or Dynamic Flag (DF).

Another example is a Usage that is declared as either an On/Off Control (OOC) or a Selector (Sel). A device that can support a variety of operational modes will declare individual bits as On/Off Controls to identify which modes are enabled. However, when the device is running, only one mode will be in effect at a time. The device would then declare the same Usage as a Selector and report this in a Named Array field to identify the mode associated with the current data. For example, a tape transport could have three states: Stopped, Paused, and Playing. This could be implemented as three individual bits where only one bit is true at a time, or as a 2-bit field in which 0 = Stopped, 1 = Paused, and 3 = Playing.

## 3.5 System Controls

Applications look at the Usage applied to top-level application collections to identify devices. System software that supports keyboards, mice, and joysticks follow the same conventions. If a device vendor wants a device to be recognized by the system software as one of these devices, then the device must follow the conventions described in this section.

### 3.5.1 Keyboard

Typical system software will search for application collections tagged with either a Keyboard or a Keypad Usage. When found, the Usages contained in these collections will be treated as standard system keyboard input. All devices that use these declarations will have their output routed to the same destination. That is, typing on any device will affect the active application.

### 3.5.2 Mice

Typical system software will search for application collections tagged with either a Mouse or a Pointer Usage. When found, the Usages generated by these collections will be treated as standard system pointer input. All devices that use these declarations will have their output routed to the same destination. That is, moving any mouse will affect the system pointer.

### 3.5.3 Joysticks

Typical system software will search for application collections tagged with either a Joystick or a Game Pad Usage. When found, the Usages generated by these collections will be treated as standard system joystick (gaming device) input. Devices that use these declarations will have their output routed to separate destinations, allowing multiple-player applications.

## 3.6 HID LANGIDs

This section identifies a set of conventions that allow static data to be associated with individual controls. These conventions are an extension of the string descriptors that can currently be attached to controls.

The first two bytes of a USB string descriptor define the length and type of the descriptor, respectively. The byte wide length field allows a string to be up to 253 bytes long. The second byte of a string is always the string descriptor type (0x03). These bytes are followed by 16-bit UNICODE characters.

Part | Offset/Size (Bytes) | Description | Sample Value
bLength | 0/1 | Size of this descriptor in bytes. | 0x06
bDescriptorType | 1/1 | String (assigned by USB). | 0x03
bString | 2/bLength-2 | UNICODE encoded string | 0x0041, 0x0042 = (AB)

Table 3.5: String Descriptor

Strings on a HID device are accessed using a Language ID (LANGID) and a string index. The LANGID is a 16-bit value where the low order 10 bits are Primary Language ID and the high order 6 bits are the Sublanguage ID. The Primary Language ID 0xFF has been permanently assigned to the HID class for it’s use. The Sublanguage IDs are defined in Table 3.8 HID Sublanguage IDs . The String Index, String Minimum and String Maximum local items allow string indices to be associated with individual main items.

0 | 1 | 2 | 3 | 4 | 5 | 6 | 7 | 8 | 9 | 10 | 11 | 12 | 13 | 14 | 15
Primary Language ID 0xFF (HID) | | | | | | | | | | Sublanguage ID Assigned by HID

Table 3.6: LANGID Format

Individual Usages define which HID LANGIDs they support and any support information the LANGID may require.

Remarks:

- If a device declares LANGID’s other than HID LANGID then return an empty string if there is no valid Unicode representation for it.
- All values are transmitted with little-endian byte alignment and in packed structures unless otherwise stated in the Usage description.

HID LANGIDs define how their associated string data is to be interpreted.

String descriptors are global to a device and assumed to be static, therefore cacheable. If a device requires that the Private Data varies as a function Configuration or Interface settings then a device must use nonoverlapping indices to ensure that string caches do not need to be invalidated,

To implement HID LANGIDs the following steps are required:

1. String index 0 always defines a list of the LANGIDs supported by the HID device. A HID LANGID must be included in the list.
2. Any main item that utilizes HID LANGIDs must have a string index attached to it, using String Index, String Minimum or String Maximum local items.
3. A string must be returned by the device, which contains the data identified by the LANGID.

To access a HID LANGID string associated with a control, the host will send a GetDescriptor(STRING_DESCRIPTOR, HID_LANGID, String Index) request to the device, where STRING_DESCRIPTOR = 0x03, the HID_LANGID is defined in Table 3.6 LANGID Format , and the String Index is defined the String local item associated with the control.

Part | Offset (Bytes) | Size (Bytes) | Description | Sample Value
bmRequestType | 0 | 1 | Device to Host, Standard, Device | 10000000B
bRequest | 1 | 1 | GET_DESCRIPTOR | 0x06
wValue (High) | 2 | 1 | STRING_DESCRIPTOR | 0x03
wValue (Low) | 3 | 1 | String Index | 0x03
wIndex | 4 | 2 | HID(Usage Defined)
wLength | 6 | 2 | Length of string

Table 3.7: GetDescriptor(String) Request

Sublanguage ID | LANGID Name | Description
00 | Reserved | Reserved
01 | Usage Data Descriptor | Allows a Usage to define a data structure that is specific to the Usage
02 - 3B | Reserved | Reserved
3C | Vendor Defined HID LANGID 1
3D | Vendor Defined HID LANGID 2
3E | Vendor Defined HID LANGID 3
3F | Vendor Defined HID LANGID 4
Table 3.8: HID Sublanguage IDs

### 3.6.1 Usage Data Descriptor (0x01)

This HID LANGID allows a Usage to define a private descriptor. A Usage that requires private data must define the format of the block of data associated with the Usage. The first two bytes of the table are identical to those defined in a standard USB string descriptor: bLength and bDescriptorType. The size and number of remaining fields depends on the Usage.

Part | Offset (Bytes) | Size (Bytes) | Value | Description
bLength | 0 | 1 | Number | Size | of | this
descriptor | in
| | | | bytes
bDescriptorType | 1 | 1 | Constant | String | (assigned
by USB)
Field 1 | 2 | Field 1 size | Usage Dependent

Usage defined fields

Field 2 | Field 1 offset + Field 1 size | Field 2 size | Usage Dependent
Field 3 | Field 2 offset + Field 2 size | Field 3 size | Usage Dependent
... | ... | ... | Usage Dependent
Field n | Field n − 1 offset + Field n − 1 size | Field n size | Usage Dependent

Table 3.9: Usage Data Descriptor

### 3.6.2 Vendor Defined HID LANGID (0x3C - 0x3F)

Four HID LANGIDs are reserved for vendor specific use. The first two bytes of the table are identical to those defined in a standard USB string descriptor, and up to 253 bytes of data can be defined by the vendor. Note that Vendor Defined HID LANGIDs allow a vendor to associate additional data with a standard Usage. For Vendor Defined Usages, the Usage Descriptor LANGID may also be used, since the definition of the Usage Descriptor depends on the Vendor Defined Usage.

The data types supported by Usage Descriptors can expand on those already supported by standard USB descriptors. These can include 64-bit signed and unsigned integers, 32, 64 and 128-bit IEEE format floating point, etc. The Usage Descriptor defined by the Usage will provide detailed information about the data types that are used.

Part | Offset (Bytes) | Size (Bytes) | Value | Description
bLength | 0 | 1 | Number | Size of this descriptor in bytes
bDescriptorType | 1 | 1 | Constant | String (assigned by USB)
Vendor Defined Data | 2 | n (n <= 253) | Vendor Defined | Vendor defined fields

Table 3.10: Vendor Defined Descriptor

# 4 Generic Desktop Page (0x01)

Usage ID | Usage Name | Usage Types | Section
00 | Undefined
01 | Pointer | CP | 4.1
02 | Mouse | CA | 4.1
03-03 | Reserved
04 | Joystick | CA | 4.1
05 | Gamepad | CA | 4.1
06 | Keyboard | CA | 4.1
07 | Keypad | CA | 4.1
08 | Multi-axis Controller | CA | 4.1
09 | Tablet PC System Controls | CA | 4.1
0A | Water Cooling Device [6] | CA | 4.1
0B | Computer Chassis Device [6] | CA | 4.1
0C | Wireless Radio Controls [13] | CA | 4.1
0D | Portable Device Control [23] | CA | 4.1
0E | System Multi-Axis Controller [33] | CA | 4.1
0F | Spatial Controller [39] | CA | 4.1
10 | Assistive Control [49] | CA | 4.1
11 | Device Dock [57] | CA | 4.15
12 | Dockable Device [57] | CA | 4.15
13-2F | Reserved
30 | X | DV | 4.2
31 | Y | DV | 4.2
32 | Z | DV | 4.2
33 | Rx | DV | 4.2
34 | Ry | DV | 4.2
35 | Rz | DV | 4.2
36 | Slider | DV | 4.3
37 | Dial | DV | 4.3
38 | Wheel | DV | 4.3
39 | Hat Switch | DV | 4.3
3A | Counted Buffer | CL | 4.6
3B | Byte Count | DV | 4.6
3C | Motion Wakeup | OSC/DF | 4.3
3D | Start | OOC | 4.3
3E | Select | OOC | 4.3
3F-3F | Reserved
40 | Vx | DV | 4.4
41 | Vy | DV | 4.4
42 | Vz | DV | 4.4
43 | Vbrx | DV | 4.4

44 | Vbry | DV | 4.4
45 | Vbrz | DV | 4.4
46 | Vno | DV | 4.4
47 | Feature Notification | DV/DF | 4.8
48 | Resolution Multiplier | DV | 4.3
49 | Qx [39] | DV | 4.14
4A | Qy [39] | DV | 4.14
4B | Qz [39] | DV | 4.14
4C | Qw [39] | DV | 4.14
4D-7F | Reserved
80 | System Control | CA | 4.5
81 | System Power Down | OSC | 4.5
82 | System Sleep | OSC | 4.5
83 | System Wake Up | OSC | 4.5
84 | System Context Menu | OSC | 4.5
85 | System Main Menu | OSC | 4.5
86 | System App Menu | OSC | 4.5
87 | System Menu Help | OSC | 4.5
88 | System Menu Exit | OSC | 4.5
89 | System Menu Select | OSC | 4.5
8A | System Menu Right | RTC | 4.5
8B | System Menu Left | RTC | 4.5
8C | System Menu Up | RTC | 4.5
8D | System Menu Down | RTC | 4.5
8E | System Cold Restart | OSC | 4.5
8F | System Warm Restart | OSC | 4.5
90 | D-pad Up | OOC | 4.7
91 | D-pad Down | OOC | 4.7
92 | D-pad Right | OOC | 4.7
93 | D-pad Left | OOC | 4.7
94 | Index Trigger [39] | MC/DV | 4.14
95 | Palm Trigger [39] | MC/DV | 4.14
96 | Thumbstick [39] | CP | 4.14
97 | System Function Shift [42] | MC | 4.5
98 | System Function Shift Lock [42] | OOC | 4.5
99 | System Function Shift Lock Indicator [42] | DV | 4.5
9A | System Dismiss Notification [53] | OSC | 4.5
9B | System Do Not Disturb [61] | OOC | 4.5
9C-9F | Reserved
A0 | System Dock | OSC | 4.5
A1 | System Undock | OSC | 4.5

A2 | System Setup | OSC | 4.5
A3 | System Break | OSC | 4.9
A4 | System Debugger Break | OSC | 4.9
A5 | Application Break | OSC | 4.9
A6 | Application Debugger Break | OSC | 4.9
A7 | System Speaker Mute | OSC | 4.5
A8 | System Hibernate | OSC | 4.5
A9-AF | Reserved
B0 | System Display Invert | OSC | 4.10
B1 | System Display Internal | OSC | 4.10
B2 | System Display External | OSC | 4.10
B3 | System Display Both | OSC | 4.10
B4 | System Display Dual | OSC | 4.10
B5 | System Display Toggle Int/Ext Mode | OSC | 4.10
B6 | System Display Swap Primary/Secondary | OSC | 4.10
B7 | System Display Toggle LCD Autoscale | OSC | 4.10
B8-BF | Reserved
C0 | Sensor Zone [6] | CL | 4.11
C1 | RPM [6] | DV | 4.11
C2 | Coolant Level [6] | DV | 4.11
C3 | Coolant Critical Level [6] | SV | 4.11
C4 | Coolant Pump [6] | US | 4.11
C5 | Chassis Enclosure [6] | CL | 4.11
C6 | Wireless Radio Button [13] | OOC | 4.12
C7 | Wireless Radio LED [13] | OOC | 4.12
C8 | Wireless Radio Slider Switch [13] | OOC | 4.12
C9 | System Display Rotation Lock Button [24] | OOC | 4.10
CA | System Display Rotation Lock Slider Switch [24] | OOC | 4.10
CB | Control Enable [22] | DF | 4.13
CC-CF | Reserved
D0 | Dockable Device Unique ID [57] | DV | 4.15
D1 | Dockable Device Vendor ID [57] | DV | 4.15
D2 | Dockable Device Primary Usage Page [57] | DV | 4.15
D3 | Dockable Device Primary Usage ID [57] | DV | 4.15
D4 | Dockable Device Docking State [57] | DF | 4.15
D5 | Dockable Device Display Occlusion [57] | CL | 4.15
D6 | Dockable Device Object Type [58] | DV | 4.15
D7-FFFF | Reserved
Table 4.1: Generic Desktop Page

## 4.1 Application Usages

Usage Name | Usage Type | Description
Pointer | CP | A collection of axes that generates a value to direct, indicate, or point user intentions
| | to an application.
Mouse | CA | A hand-held, button-activated input device that when rolled along a flat surface,
directs an indicator to move correspondingly about a computer screen, allowing the operator to move the indicator freely in select operations or to manipulate text or graphics. A mouse typically consists of two axes (X and Y) and one, two, or three
| | buttons.
Joystick | CA | A manual control or cursor device. A joystick minimally consists of two variable
axes (X and Y) and two buttons. A joystick is typically a rotational motion sensor. However, for legacy reasons, it is defined using linear axes.

Traditionally, a joystick driver applies its own scaling to values returned from a joystick. That is, the driver simply linearizes and translates the range of values generated by the stick into normalized values between 0 and 64K, where 32K is centered. The application (game) then interprets the normalized values as necessary. Because of this, joysticks normally do not declare Units or Physical Minimum and Physical Maximum values for their axes. Depending on the driver, these items may be ignored if they are declared.

Gamepad | CA | A manual control or cursor device. | A game pad minimally consists of a
thumb-activated rocker switch that controls two axes (X and Y) and has four buttons. The rocker switch consists of four contact closures for up, down, right,
| | and left.
Keyboard | CA | The primary computer input device. A Keyboard minimally consists of 103
buttons as defined by the Boot Keyboard definition.
Keypad | CA | Any keyboard configuration that does not meet the minimum requirements of
the Boot Keyboard. Keypad often refers to a supplementary calculator-style
| | keyboard.

Multi-axis
Controller
CA | An input device used to orient eyepoints and or objects in 3 dimensional space. A
Multi-axis Controller typically consists of six, variable axes (X, Y, Z, Rx, Ry and Rz) and is used by CAD/digital content creation applications for model manipulation and visualization in 3D space. The device may incorporate zero or more buttons.

Tablet PC
System
Controls
CA | System controls on Tablet PCs. This collection is not intended to contain display or
audio data nor touchscreen input. Appropriate controls might be buttons, wheels, or simple indicators. This collection is intended to be opened by the operating system in exclusive mode and is not meant for application developers to open directly.

Water
Cooling
Device
CA | A collection of sensors and controls that represents a device using liquid to provide
cooling of a thermal environment. A water cooling device contains at least one
| | thermal reporting control.

Computer
Chassis
Device
CA | A collection of usages that represent data about the condition, state, and controls of
sensors and devices attached to a chassis containing the motherboard and associated components (e.g., processor, graphics controller, hard drives) of a computing device.

Wireless
Radio
Controls
CA | A collection of buttons or switches that enable all-wireless radio communication to
| | be turned on/off.

Portable
Device
Control
CA | A collection of controls on the portable devices, for example, volume controls,
rotation lock, power, camera controls, home button, etc.

System
Multi-Axis
Controller
CA | A collection of controls that may contain the same controls as listed in Multi-Axis Controller (Usage 0x08) and/or additional associated controls such as wheels, dials, buttons etc... for exclusive use of the System.

Spatial
Controller
CA | A handheld input device that users move freely through space to provide position and orientation input.

Assistive
Control
CA | A manual control or cursor device. An assistive control device may consist of buttons or a pointing input control to communicate.

## 4.2 Axis Usages

For X, Y, Z, Rx, Ry, and Rz, the declaration of Units is optional. If Units is None or not declared, these values should be considered as dimensionless.

Usage Name | Usage Type | Description
X | DV | A linear translation in the X direction. Report values should increase as the control’s position is moved from left to right.
Y | DV | A linear translation in the Y direction. Report values should increase as the control’s position is moved from far to near.
Z | DV | A linear translation in the Z direction. Report values should increase as the control’s position is moved from high to low (Z).
Rx | DV | A rotation about the X axis. Angular position report values follow the righthand rule.
Ry | DV | A rotation about the Y axis. Angular position report values follow the righthand rule.
Rz | DV | A rotation about the Z axis. Angular position report values follow the righthand rule.

## 4.3 Miscellaneous Controls

Usage Name | Usage Type | Description
Slider | DV | A linear control for generating a variable value, normally in the form of a thumb slide in a slot. Report values should increase as controls are moved from near to far.
Dial | DV | A rotary control for generating a variable value, normally in the form of a knob spun by the index finger and thumb. Report values should increase as controls are spun clockwise. This usage does not follow the HID orientation conventions.
Wheel | DV | A rotary control for generating a variable value, normally rolled, unlike a dial. Report values should increase as controls are rolled forward, away from the user. This usage does not follow the HID orientation conventions.
Hat Switch | DV | A specialized mechanical configuration of switches generating a variable value with a NULL state. The switches are arranged around a springloaded knob. When the knob is tilted in the direction of a switch, its contacts are closed. A typical example is four switches that are capable of generating information about four possible directions in which the knob can be tilted. Intermediate positions can also be decoded if the hardware allows two switches to be reported simultaneously.
Motion Wakeup | DF | Enables the generation of a USB remote wakeup when the device detects motion. Motion Wakeup is always enabled after a USB Reset event is detected by the device. Then host can also assume that the state of the Motion Wakeup flag is maintained while the device is suspended.
| | For example, a mouse may generate a remote wakeup when a button is pressed or when it is moved. For some implementations, a laptop user may want to disable the wakeup on motion because it draws more power.
Start | OOC | Session start button. Initiates a session within an application.
Select | OOC | Application option select button. Selects application configuration options.
Resolution Multiplier | DV | Defines a Resolution Multiplier for a Control.

### 4.3.1 Resolution Multiplier

A HID describes the resolution of a control by using the methods described in the HID Specification, v1.11, section 6.2.2.7 Global Items – Remarks. However, the resolution of a control in this model is static. If a device has the capability to vary the resolution of one or more of its controls, the resolution of those controls can be set by defining an associated Resolution Multiplier control.

The Resolution Multiplier control must be contained in the same Logical Collection as the control(s) to which it is to be applied. If no Resolution Multiplier is defined, then the Resolution Multiplier defaults to 1. If more than one control exists in a Logical Collection, the Resolution Multiplier is associated with all controls in the collection. If no Logical Collection is defined, the Resolution Multiplier is associated with all controls in the report.

The Resolution Multiplier is applied after all the normal resolution calculations have been performed for an affected control. The Resolution Multiplier is calculated as below:

EffectiveResolutionMultiplier =

RMV − LMin
LMax − LMin

× (PMax − PMin)

+ PMin
× 10UnitExponent
Variable | Description
RMV | Resolution Multiplier Value
LMin | Logical Minimum
LMax | Logical Maximum
PMin | Physical Minimum
PMax | Physical Maximum

For example, if a Wheel Control is defined as below:

Usage Page (Generic Desktop) (0x01) Usage (Wheel) (0x38)
Logical Minimum (-127)
Logical Maximum (127)
Report Count (1)
Report Size (8)
Input (Data, Var, Rel)

Then, the Wheel control delivers one count per detent via a 1-byte field of an Input Report. However if a Resolution Multiplier feature is included in the report with the Wheel as below:

Collection (Logical)
Usage Page (Generic Desktop) (0x01) Usage (Resolution Multiplier) (0x48) Logical Minimum (0)
Logical Maximum (15)
Physical Minimum (1)
Physical Maximum (16)
Report Size (4)
Report Count (1)
Feature (Data, Var, Abs)
Usage Page (Generic Desktop) (0x01) Usage (Wheel) (0x38)
Logical Minimum (-127)
Logical Maximum (127)
Report Count (1)
Report Size (8)
Input (Data, Var, Rel)
End Collection

Then, the Effective Resolution Multiplier for the Wheel may vary from 1 to 16 depending on the setting of the Resolution Multiplier feature. If the Resolution Multiplier feature is set to 7, then the Effective Resolution Multiplier is 8, meaning that the resolution of the Wheel control is 8 counts per detent.

Negative Effective Resolution Multipliers may be used to reverse the sense of a control.

Because OS implementations will generally divide the control’s reported count by the Effective Resolution Multiplier, designers should take care not to establish a potential Effective Resolution Multiplier of zero. This may be done by ensuring that Physical Min and Physical Max are nonzero and have the same sign.

The Resolution Multiplier is a scalar (unitless) multiplier. It may not be used to convert units from one system to another.

## 4.4 Vector Usages

For the usages Vx, Vy, Vz, Vbrx, Vbry, Vbrz, and Vno, Units are always required to determine the meaning of the vector. Rotational vectors are also identified by Units. These usages are used when declaring velocity, acceleration, force, electric field, and similar kinds of vectors in the respective direction and frame of reference.

Usage Name | Usage Type | Description
Vx | DV | A vector in the X direction. Report values should increase as the vector increases in the positive X direction (from left to right). Negative values represent vectors in the negative X direction.
Vy | DV | A vector in the Y direction. Report values should increase as the vector increases in the positive Y direction (from far to near). Negative values represent vectors in the negative Y direction.
Vz | DV | A vector in the Z direction. Report values should increase as the vector increases in the positive Z direction (from high to low). Negative values represent vectors in the negative Z direction.
Vbrx | DV | A vector in the X direction relative to the body of an object. Report values should increase as the vector increases in the positive X direction (forward). Negative values represent vectors in the negative X direction. X is the forward axis for an object.
Vbry | DV | A vector in the Y direction relative to the body of an object. Report values should increase as the vector increases in the positive Y direction (to the right from an observer facing forward on the object). Negative values represent vectors in the negative Y direction.
Vbrz | DV | A vector in the Z direction relative to the body of an object. Report values should increase as the vector increases in the positive Z direction (down from an observer facing forward on the object). Negative values represent vectors in the negative Z direction.
Vno | DV | A non oriented vector or value. The units define a physical measurement not related to a specific axis or orientation. An example would be pressure or temperature.

## 4.5 System Controls

System controls are a special category of usages that affect the system as a whole. They are pulled together in a System Control collection to make them easy for system software to identify.

Usage Name | Usage Type | Description
System Control | CA | A application-level collection that contains system-software-specific usages. System software will search specifically for this collection for those controls that affect the system globally.
System Context Menu | OSC | Evokes a context-sensitive menu.
System Main Menu | OSC | Evokes the OS main-level selection menu.
System App Menu | OSC | Displays an application-specific menu.
System Menu Help | OSC | Displays the help menu.
System Menu Exit | OSC | Exits a menu.
System Menu Select | OSC | Selects a menu item.
System Menu Right | RTC | Menu select right.
System Menu Left | RTC | Menu select left.
System Menu Up | RTC | Menu select up.
System Menu Down | RTC | Menu select down.
System Function Shift | MC | Indicates the state of the feature. 1=on, 0=off. Usually this maps directly to the state of the Fn key, but may be reversed if the System Function Shift Lock is also on.
System Function Shift Lock | OOC | Locks the System Function Shift state. This is an On/Off control with a recommended implementation of Relative, Preferred State for physically non-locking keys, and Absolute, No Preferred state for physically locking keys.
System Function Shift Lock Indicator | DV | The value of a visual indicator of System Function Shift Lock.
System Dismiss Notification | OSC | Dismisses active notification (e.g. pop-ups/alerts) from system environments and applications that arrest the user’s attention (e.g. Voice Assistants, VOIP calls, Alarms). Many modern devices have a paradigm of dismissing such notifications using the Power button.
System Do Not Disturb | OOC | Toggle system-wide Do Not Disturb (DND) mode On/Off.

### 4.5.1 Power Controls

Power controls can step the system through the following states: Full Power, Low Power, and Power Down. Power control usages found in a System Control collection affect system level power. Those declared outside of a System Collection affect device level power.

Usage Name | Usage Type | Description
System Power Down | OSC | Asserted when the intended action is to initiate system-wide power down now from Full Power or Sleep states.
System Sleep | OSC | Asserted when the intended action is to initiate system-wide low power mode now. If the system is already in the Low Power state, there is no effect.
System Wake Up | OSC | Asserted when the intended action is to initiate system-wide Full Power state now. If the system is already in the Full Power, there is no effect.

System Cold Restart | OSC | Asserted when the intended action is to restart the system at the most primitive level, similar to at Power Up.
System Warm Restart | OSC | Asserted when the intended action is to restart the operating system but not necessarily the lowest level functions such as BIOS enumeration and RAM checks.
System Dock | OSC | Asserted when the intended action is to prepare a portable system for docking with a docking station.
System Undock | OSC | Asserted when the intended action is to prepare a portable system for removal from a docking station.
System Setup | OSC | Asserted when the intended action is to enter the BIOS-level system setup program.
System Speaker Mute | OSC | Asserted when the intended action is to mute the system speaker.
System Hibernate | OSC | Asserted when the intended action is to place the system in a "deeper" sleep state than System Sleep

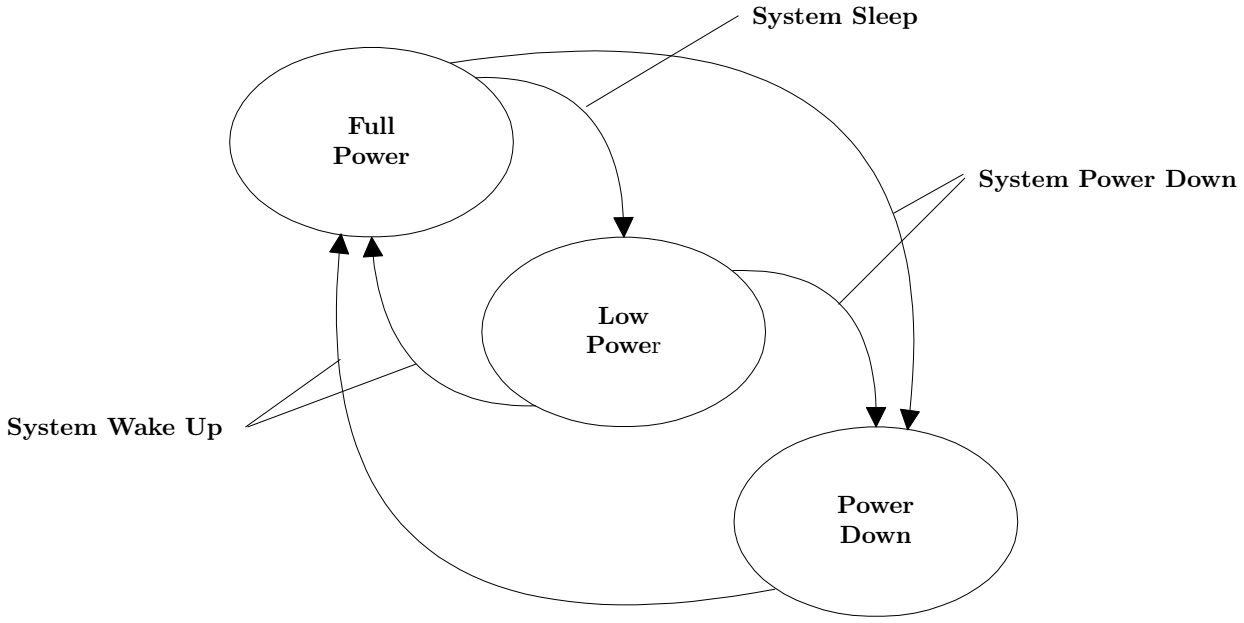
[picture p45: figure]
Full Power; Low Power; Power Down; System Sleep; System Power Down; System Wake Up

Figure 4.1: System Power States

## 4.6 Buffered Bytes

The following usages provide a standard way of defining the operation of a buffered-byte field where the number of valid bytes in the field is less than the total number of bytes in the field and the vendor does no define a NoOp value to mark unused bytes.

When declaring a buffered-byte field, the global item Report Size should always be set to 8 (for byte cells), and the Report Count should be equal to the maximum size of the buffer to be transferred.

Usage Name | Usage Type | Description
Counted Buffer | CL | Used with buffered–byte data to indicate the number of valid bytes in the buffered-byte field. This collection always contains two field declarations: Byte Count and a usage that names the purpose of the buffered-byte field. The Main item associated with the purpose usage will always have the Buffered Bytes attribute set.
Byte Count | DV | Defines a report field that indicates the number of meaningful data bytes in an associated buffered-byte field.

## 4.7 Direction Pads

A Direction Pad or D-Pad control is mechanically identical to a hatswitch, however for legacy reasons their data is interpreted as X and Y axes rather than as an angular direction.

D-pads are typically defined as a pair of X and Y axes that are contained in a logical Pointer collection. There are cases where an application may be interested in the raw D-pad data. The following usages are defined in a report descriptor as single bit fields that identify the current state of the position switches in the D-pad.

Note: A device may declare a Pointer collection with X and Y axes, and D-pad usages for the same control.
An application can determine which data format best suits it’s needs.
Usage Name | Usage Type | Description
D-pad Up | OOC | Indicates that top of a Direction Pad is pressed.
D-pad Down | OOC | Indicates that bottom of a Direction Pad is pressed.
D-pad Right | OOC | Indicates that right side of a Direction Pad is pressed.
D-pad Left | OOC | Indicates that left side of a Direction Pad is pressed.

## 4.8 Feature Notifications

It may be useful to alert the host that the contents of a Feature report have changed without redundantly declaring a usage in an Input report, especially is the changes are only occasional. The Feature Notification usages provides a mechanism for doing this.

Usage Name | Usage Type | Description
Feature Notification | DV | This usage is declared in an Input report and is used as a notification to the host that the contents of a specific Feature report has changed. If Report IDs are declared in the device’s report descriptor then the Report Size of the Feature Notification must be greater than 1, and the Feature Notification field contains the Report ID of the Feature report that whose contents have changed. A zero value indicates that no Feature reports have changed. Multiple Feature report IDs can be reported in a single Input report by declaring the Report Count to be greater than 1. If Report IDs are not declared in the device’s report descriptor then the Report Size of the Feature Notification equals 1, and the Input report field equals 1 if the Feature report contents have changed. A zero value indicates that no Feature reports have changed. When a valid Feature Notification is received, the host must issue a GetReport(Feature) request to the device with the appropriate report ID.

## 4.9 Software Flow Controls

The following usages provide standard controls to break into the current operation of the system.

Usage Name | Usage Type | Description
System Break | OSC | Asserted when the intended action is to acquire the attention of the operating system in order to control applications. This operation could interrupt all running applications.
System Debugger Break | OSC | Asserted when the intended action is to break into the operating system debugger. If no OS debugger is running, the control is ignored.
Application Break | OSC | Asserted when the intended action is to acquire the attention of an application. This operation interrupts only the foremost running application.
Application Debugger Break | OSC | Asserted when the intended action is to break into the application debugger. If no application debugger is running, the control is ignored.

## 4.10 System Display Controls

Many systems currently support multiple displays. Of special note are portable systems with captive displays that may be connected to external displays. The following usages provide standard controls for common display control functions:

Usage Name | Usage Type | Description
System Display Invert | OSC | Causes the display to render in inverted colors.
System Display Internal | OSC | Causes the system to use the captive display as the primary display.
System Display External | OSC | Causes the system to use the external display as the primary display.
System Display Both | OSC | Causes the system to use both internal and external displays as the primary display.
System Display Dual | OSC | Causes the system to use both internal and external displays as primary and secondary displays.
System Display Toggle Int/Ext Mode | OSC | Causes a system to step between the modes as described above: • System Display Internal • System Display External • System Display Both
System Display Swap Primary/Secondary | OSC | Causes a system using two displays in dual mode to swap the primary and secondary displays.
System Display Toggle LCD Autoscale | OSC | Causes a system with a non-scaleable geometry, such as an LCD, to scale the display image to fit the physical geometry of the display.
System Display Rotation Lock Button | OOC | Indicates the current state of a system display rotation lock on/off momentary push button. State must be reported once for every button press.
System Display Rotation Lock Slider Switch | OOC | Indicates the absolute value for the state of system display rotation lock. State must be reported when it goes from 0 to 1 as well as from 1 to 0.

## 4.11 Computer Sensor Controls

Advances in the enthusiast class personal computer has led to the development of intelligent water cooling devices, chassis, and power supplies that provide addition status, monitoring, and control information to the user on the health and capabilities of their system. In addition to the raw sensor data, the sensors can be grouped into logical thermal and control zones to represent different operating areas within the device (e.g., thermal zones around the processor, hard drives, or PCI-E slots).

Usage Name | Usage Type | Description
Sensor Zone | CL | A logical collection that represents a grouping of sensors or other controls
within a device that control a common physical region or physical function
| | within the device when one or more physical regions exist.
RPM | DV | Indicates or controls the current revolutions per minute of a rotating device
(e.g., fan). This usage shall be represented as units of rotations per minute.
Coolant Level | DV | Indicates the current level of coolant in its coolant containment container.
This usage shall be represented as a percentage with a logical minimum of
| | zero and a logical maximum of 100.
Coolant Critical Level | SV | Indicates the level at which the coolant is below a critical threshold at which
| | the potential for damage exists.
Coolant Pump | US | This collection allows the usages that it contains to be associated with a
| | coolant pump. In this collection one or more RPM usages are found.
Chassis Enclosure | CL | This collection represents the dimensions of a computer chassis. | This
| | collection shall contain an X, Y, and Z usage.

## 4.12 Wireless Radio Controls

Usage Name | Usage Type | Description
Wireless Radio Button | OOC | Indicates the current state of a wireless on/off momentary push button. State must be reported once for every button press.
Wireless Radio LED | OOC | Indicates the current state of wireless communication to the user. This will reflect the state of the overall system radio state.
Wireless Radio Slider Switch | OOC | Indicates the absolute value for the state of radio communications. State must be reported when it goes from 0 to 1 as well as 1 to 0.

## 4.13 Generic Controls

Usage Name | Usage Type | Description
Control Enable | DF | Enable or disable the controls within the current logical collection. A value of 1 indicates that the controls in the same logical collection are enabled. A value 0 indicates they are disabled.
| | When disabled, controls that are declared without the NULL attribute will keep their last values. Controls that declare the NULL attribute will be in a NULL state without further state changes. Also, such controls that are not in NULL that get disabled will move to NULL and input controls should generate a report to that effect. Feature and output reports will change silently.

## 4.14 Spatial Controls

A spatial controller is a handheld input device that users move freely through space to provide position and orientation input. The spatial controller’s orientation is represented as a rotation relative to its neutral orientation. The neutral orientation is the controller’s orientation when sitting flat on a surface pointing forward along the negative Y axis, with gravity pointing down along the positive Z axis and with X increasing from the Controller’s left to its right. The forward direction in the XY plane is unspecified and implementation-specific. This rotation is expressed as a unit quaternion (Qx/Qy/Qz/Qw).

If the Spatial Controller reports position in addition to orientation, the translation axes must correspond to the rotation axes.

Note: Expressing a rotation as a quaternion avoids ambiguity about the order in which the host must apply
the three axis rotations. Many applications also choose to use quaternions instead of Euler angles in their
own logic to avoid gimbal lock. Surfacing quaternions directly to such apps from the device’s firmware reduces precision loss caused by the conversion from Rx/Ry/Rz.
Usage Name | Usage Type | Description
Qx | DV | The X component of a unit quaternion, representing a rotation in space about a unit vector. Rotations represented by quaternion report values follow the right-hand rule.
Qy | DV | The Y component of a unit quaternion, representing a rotation in space about a unit vector. Rotations represented by quaternion report values follow the right-hand rule.
Qz | DV | The Z component of a unit quaternion, representing a rotation in space about a unit vector. Rotations represented by quaternion report values follow the right-hand rule.
Qw | DV | The W component of a unit quaternion, representing a rotation in space about a unit vector. Rotations represented by quaternion report values follow the right-hand rule.
Index Trigger | MC/DV | The pressure applied to an input device’s index-finger trigger, indicating that the user is pulling their index finger. This usage can be a DV for an analog trigger or an MC for a digital trigger.
Palm Trigger | MC/DV | The pressure applied to an input device’s palm trigger, indicating that the user is closing their fist tightly around the controller. This usage can be a DV for an analog trigger or an MC for a digital trigger.
Thumbstick | CP | An input device’s two-axis thumb-operated control stick. The thumbstick’s X value increases from left to right and its Y value increases from bottom to top. A thumbstick is typically a rotational motion sensor. However, for legacy reasons, it is defined using linear axes.

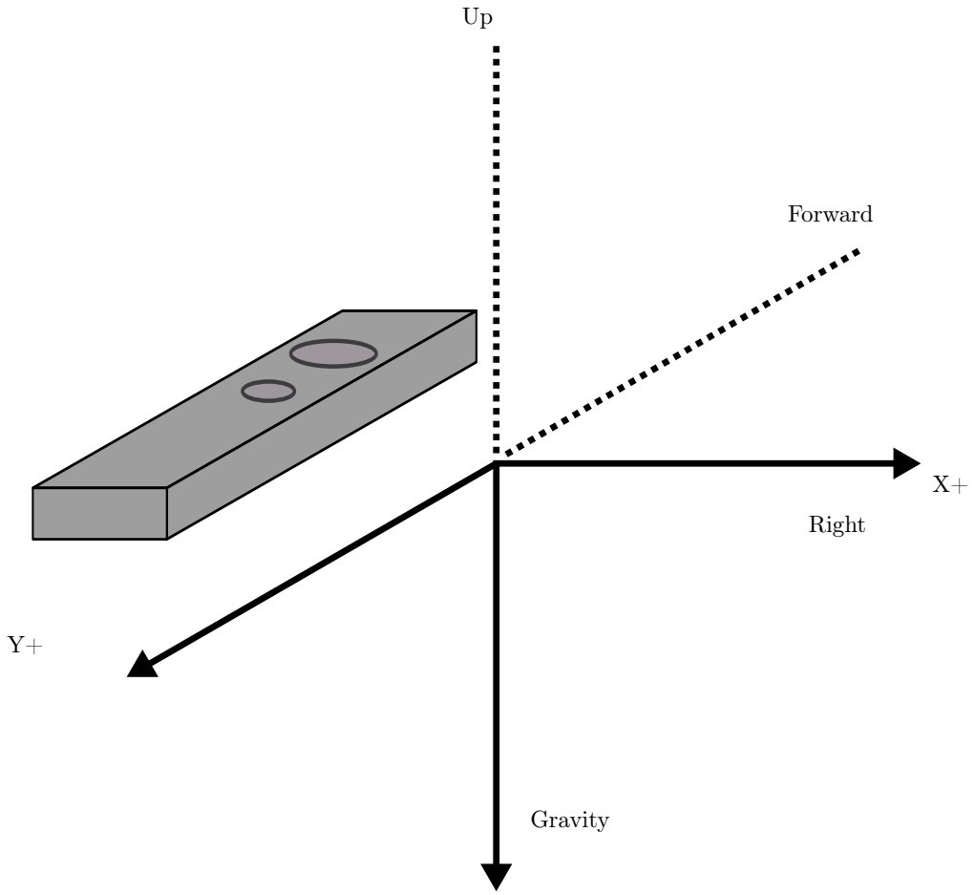
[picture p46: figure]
Forward; Right; Gravity

Z+

Figure 4.2: Spatial Controller Orientation

## 4.15 Dockable Devices

In many computing systems, there are cases where a potentially non-HID Dockable Devices can be physically attached to a system or another device - whether for storage, to charge, or for ergonomic usage of the device relative to the needs of the computing system. While modern operating systems may be able to detect some elements of this attachment though device enumeration or ACPI information, there are use cases where rich information specific to the state of the Dockable Device’s attachment to the system can be valuable.

For example, a digital pen which only communicates with a digitizer within a short range may not be able to communicate that it has been attached to a pen holder on the device for the system to update UI showing the pen has been connected. Other representations may disable a Dockable Device’s connection to the host when placed in a dock to allow for reduced power consumption.

In other cases, the Device Dock itself may have access to information that the Dockable Device may not. In a system with a horizontal display, for example, it may be possible for a sensor to detect exactly where a Dockable Device or other object has been placed relative to the display, so that the system may adjust placement of UI around it, while the object itself is incapable of detecting or reporting this information.

Usage Name | Usage Type | Description
Device Dock | CA | A device that reports the presence of a Dockable Device physically attached to the system.
Dockable Device | CA | A device describing a Dockable Device that can be physically attached to the system.
Dockable Device Unique ID | DV | Specifies the unique ID identifying the device which has been docked.
| | This is an optional Usage - if the Dockable Device does not have a Dockable Device Unique ID or the Device Dock is not capable of reading the Dockable Device Unique ID from the device, this would not be provided. If provided, the Dockable Device Unique ID must be unique for the USB-IF VendorId, specified by Dockable Device Vendor ID below. For example, this could contain the unique serial number of the Dockable Device or a product identifier if a serial number cannot be provided.
Dockable Device Vendor ID | DV | Specifies the USB-IF VendorId of the Dockable Device, used in combination with Dockable Device Unique ID to uniquely identify the device.
| | This is an optional Usage. If provided, this must be a 16-bit value.
Dockable Device Primary Usage Page | DV | Specifies the UsagePage of the primary top-level collection of the Dockable Device (in the case of a complex HID device), to allow the system to understand which Dockable Device has been docked.
| | This is an optional Usage which can be useful in cases where the Dockable Device is not connected to the system, or is not capable of reporting a unique serial number, in conjunction with Dockable Device Primary Usage ID. For a Dockable Device with multiple HID top-level collections, the value of this Usage is defined by the vendor.
Dockable Device Primary Usage ID | DV | Specifies the UsageId of the primary top-level collection of the Dockable Device (in the case of a complex HID device).
| | This is an optional Usage, used in conjunction with Dockable Device
Primary Usage Page. | For a Dockable Device with multiple HID
| | top-level collections, the value of this Usage is defined by the vendor.

Dockable Device
Docking State
DF | A bit that indicates if the Dockable Device is currently attached to the
system.

This is a required Usage. A report with this bit set would indicate the Dockable Device is physically attached to the system. A report with this bit cleared would indicate the Dockable Device has been physically detached from the system.

Dockable Device
Display Occlusion
CL | A physical collection describing what portion of a display is occluded by the
Device Dock.

This collection is optional – it would not be reported if the supported Dockable Device cannot occlude the display. This collection could include values like X, Y, Width (in mm), Height (in mm), Azimuth, etc. for rectangular-shaped occlusions. Future Usages could support other Dockable Device shapes.

Dockable Device
Object Type
DV | An enum which specifies the type of object which is being docked.

This is an optional usage. It is possible that there could be multiple Dockable Objects placed relative to the display that also include different objects types such as:
- 0: Unspecified.
- 1: HID Device.
- 2: Display.
- 3: NFC Device.

# 5 Simulation Controls Page (0x02)

Usage ID | Usage Name | Usage Types | Section
00 | Undefined
01 | Flight Simulation Device | CA | 5.2
02 | Automobile Simulation Device | CA | 5.3
03 | Tank Simulation Device | CA | 5.4
04 | Spaceship Simulation Device | CA | 5.2
05 | Submarine Simulation Device | CA | 5.5
06 | Sailing Simulation Device | CA | 5.5
07 | Motorcycle Simulation Device | CA | 5.6
08 | Sports Simulation Device | CA | 5.1
09 | Airplane Simulation Device | CA | 5.2
0A | Helicopter Simulation Device | CA | 5.2
0B | Magic Carpet Simulation Device | CA | 5.7
0C | Bicycle Simulation Device | CA | 5.6
0D-1F | Reserved
20 | Flight Control Stick | CA | 5.2
21 | Flight Stick | CA | 5.2
22 | Cyclic Control | CP | 5.2
23 | Cyclic Trim | CP | 5.2
24 | Flight Yoke | CA | 5.2
25 | Track Control | CP | 5.4
26-AF | Reserved
B0 | Aileron | DV | 5.2
B1 | Aileron Trim | DV | 5.2
B2 | Anti-Torque Control | DV | 5.2
B3 | Autopilot Enable | OOC | 5.2
B4 | Chaff Release | OSC | 5.2
B5 | Collective Control | DV | 5.2
B6 | Dive Brake | DV | 5.2
B7 | Electronic Countermeasures | OOC | 5.2
B8 | Elevator | DV | 5.2
B9 | Elevator Trim | DV | 5.2
BA | Rudder | DV | 5.2
BB | Throttle | DV | 5.2
BC | Flight Communications | OOC | 5.2
BD | Flare Release | OSC | 5.2
BE | Landing Gear | OOC | 5.2
BF | Toe Brake | DV | 5.2
C0 | Trigger | MC | 5.2
C1 | Weapons Arm | OOC | 5.2
C2 | Weapons Select | OSC | 5.2

C3 | Wing Flaps | DV | 5.2
C4 | Accelerator | DV | 5.3
C5 | Brake | DV | 5.3
C6 | Clutch | DV | 5.3
C7 | Shifter | DV | 5.3
C8 | Steering | DV | 5.3
C9 | Turret Direction | DV | 5.4
CA | Barrel Elevation | DV | 5.4
CB | Dive Plane | DV | 5.5
CC | Ballast | DV | 5.5
CD | Bicycle Crank | DV | 5.6
CE | Handle Bars | DV | 5.6
CF | Front Brake | DV | 5.6
D0 | Rear Brake | DV | 5.6
D1-FFFF | Reserved
Table 5.1: Simulation Controls Page

## 5.1 Sports Simulation Device

Usages employed by Stick Devices and Exercise Machines are defined on the Sports Controls page. For details, see Section 7 Sport Controls Page (0x04)

Usage Name | Usage Type | Description
Sports Simulation Device | CA | This usage definition allows a device to be generally classified as one that uses standard controls found on a sports simulation device.

## 5.2 Flight Simulation Devices

Usage Name | Usage Type | Description
Flight Simulation Device | CA | This usage definition allows a device to be generally classified as one that uses the standard controls found on an airplane.
Spaceship Simulation Device | CA | This usage definition allows a device to be generally classified as one that uses standard controls found on a spaceship.
Airplane Simulation Device | CA | This usage definition allows a device to be generally classified as one that uses standard controls found on an airplane.
Helicopter Simulation Device | CA | This usage definition allows a device to be generally classified as one that uses standard controls found on a helicopter.
Aileron | DV | An aileron is one of two movable flaps on the wings of an airplane that can be used to control the plane’s rolling and banking movements. In the zero position the ailerons are centered, positive values will move the right aileron up and the left aileron down, and negative values will have the opposite effect on the ailerons.
Aileron Trim | DV | Allows fine adjustment of the Aileron position. The zero position is the nominal position, positive values will move the right aileron up and the left aileron down, and negative values will have the opposite effect on the ailerons.
Anti-Torque Control | DV | This control mechanically behaves the same as rudder pedals; as one is pushed forward, the other pushes back. In a helicopter, this controls the pitch of the tail blade to spin the helicopter in place. The zero position is centered, positive values rotate right, and negative values rotate left.
Autopilot Enable | OOC | This control enables or disables an airplane’s autopilot. This should be a toggle switch, but it is typically implemented as a pushbutton.
Chaff Release | OSC | Chaff is strips of metal, foil, or glass fiber with a metal content, cut into various lengths and having varying frequency responses. It is used to reflect electromagnetic energy as a radar countermeasure. These materials, usually dropped from aircraft, also can be deployed from shells or rockets. Typically this a pushbutton that initiates a release of a fixed amount of material.
Collective Control | DV | This control is specifically for a helicopter. It controls the vertical acceleration or lift of the helicopter. The zero position is centered (level flight), positive values accelerate up, and negative values accelerate down.
Cyclic Control | CP | This control is specifically for a helicopter. A cyclic control is a stick between the pilot’s legs that moves in two axes. It controls the swash plate, which in turn controls horizontal acceleration of the helicopter. The zero position is centered, positive Y values accelerate forward, and negative Y values accelerate backward. Positive X values accelerate right, and negative X values accelerate left. This collection will contain X and Y axes.
Cyclic Trim | CP | This control is specifically for a helicopter. Cyclic Trim allows fine adjustment of the cyclic position in two dimensions. The zero position is the nominal position, positive values adjust the baseline acceleration right or forward, and negative values adjust the baseline acceleration left or backward, respectively. This collection will contain X and Y axes.
Dive Brake | DV | A flap that can be extended on an aircraft to increase drag and reduce the speed of descent. It is typically implemented as a lever that generates a dimensionless value between no braking (0) and full braking.
Electronic Countermeasures | OOC | A pushbutton that enables electronic countermeasures. This is typically active radar jamming; however Chaff (radar) or Flare (infrared) can be invoked.

Elevator | DV | A movable control surface, usually attached to the horizontal stabilizer of an aircraft, that is used to produce motion up or down. The zero position is centered, positive values raise the elevator, and negative values lower the elevator.
Elevator Trim | DV | Elevator Trim allows fine adjustment of the Elevator position. The zero position is the nominal position, positive values are elevator offset up, and negative values are elevator offset down.
Flight Communications | OOC | In combat aircraft, a communication (comm) button is usually positioned under
the index finger. | Typically this is a two-position pushbutton where the first
| | position enables communications with the crew and the second position enables the transmitter for communication external to the plane.
Flare Release | OSC | A flare is a device that produces a bright light for signaling, illumination, identification, or heat for infrared missile countermeasures. Typically this is a pushbutton that releases a fixed number of flares.
Flight Control Stick | CA | A Flight Control Stick controls the Pitch and Roll of an airplane. It looks like a joystick. The stick may be pushed forward or pulled back to move the tail elevator down or up, respectively. Pushing forward causes the plane to nose down. Tilting the stick right and left alters the position of the ailerons. In the zero position the ailerons are centered, tilting the stick to the right will move the right aileron up and the left aileron down, and tilting the stick to the left direction will have the opposite effect on the ailerons.
| | Mechanically, a stick presents two degrees of rotational freedom with approximately a +/–45° range. However, these axes are represented as Generic Desktop Page translational axes X (Roll) and Y (Pitch).
Flight Stick | CA | A Flight Stick defines a class of device commonly used for flight simulator games. For a device to qualify as a Flight Stick, it must support at least two axes (Pitch and Roll), a trigger button, three additional buttons, and a hat switch. A Flight Stick is a functional subset of a Flight Control Stick.
Landing Gear | OOC | A control for raising or lowering an airplane’s landing gear. This should be a toggle switch, but it is typically implemented as pushbutton.
Rudder | DV | The zero position is centered, positive values turn right, and negative values turn left.
Toe Brake | DV | A device for slowing or stopping the motion of an airplane when it is on the ground. Typically, Toe Brakes consist of two foot pedals that affect the left and right brakes, respectively. Control of the Toe Brakes can allow steering of the plane as well as braking when it is on the ground. An analog Toe Brake generates a dimensionless value between 0 and full scale. In some implementations, the Toe Brake can simply be a pushbutton (full on or off).
Throttle | DV | A valve that regulates the flow of a fluid, such as the valve in an internal-combustion engine that controls the amount of vaporized fuel entering the cylinders. A lever or pedal controlling such a valve generates a dimensionless value between 0 and full scale.
Trigger | MC | A lever pressed by the finger to release or activate a mechanism, typically used to discharge a firearm. However, a Trigger can be used for many devices. In combat airplanes the Trigger is usually positioned under the thumb; for a gun it would be positioned under the index finger. Typically this is implemented as a pushbutton.
Weapons Arm | OOC | This device is normally a covered toggle switch that must be selected to enable the weapons system.
Weapons Select | OSC | This device can either be a pushbutton that steps through the available weapons or a radio button that selects them individually.

Wing Flaps | DV | Wing flap controls are usually powered either hydraulically or by electric motors, and are used for low-speed control of an airplane. A flap generates a value between 0 and full extension.
Flight Yoke | CA | A flight yoke (also called a control wheel) controls the pitch and roll of an airplane. It looks like a bow tie grasped by both hands. The yoke at which the pilot sits may be pushed forward or pulled back to move the tail elevator down or up, respectively. In the zero position the elevator is centered for level flight. Pushing forward on the yoke causes the plane to nose down and generates negative values. Pulling back on the yoke causes the plane to nose up and generates positive values.
Rotating the yoke alters the position of the ailerons. | In the zero position
| | the ailerons are centered. Rotating the yoke in a clockwise direction will move the right aileron up and the left aileron down and generate incrementing values. Rotating the yoke in the counterclockwise direction will have the opposite effect on the ailerons and generate decrementing values.

## 5.3 Automobile Simulation Devices

Usage Name | Usage Type | Description
Automobile Simulation Device | CA | This usage definition allows a device to be generally classified as one that uses the standard controls found in an automobile or truck.
Accelerator | DV | A device, especially the gas pedal of a motor vehicle, for increasing speed. An Accelerator is a dimensionless single degree-of-freedom dynamic value, where the range of values is from zero to maximum acceleration.
Brake | DV | A device for slowing or stopping motion, as of a vehicle, especially by contact
friction. | A Brake can be an On/Off Control or a dimensionless single
| | degree-of-freedom dynamic value, where the range of values is from zero to maximum braking.
Clutch | DV | A device for disengaging the transmission of a vehicle to allow shifting of gears. A Clutch can be a generic button or a dimensionless single degree-of-freedom dynamic value, where the range of values is from zero to maximum clutch actuation.
Shifter | DV | A device for shifting gears in a vehicle. A Shifter is a specialized mechanical configuration of a radio button. A zero value is returned when the shifter is in the neutral position. Positive values indicate the forward gear and negative values indicate the reverse gear that the device is in.
Steering | DV | A steering wheel is a single degree-of-freedom device that rotates about an axis. The zero position is always the neutral or straight ahead position, with positive values turning clockwise and negative values turning counterclockwise. If the Coordinate Values Wrap attribute is set, the steering wheel can be turned past 360°.
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

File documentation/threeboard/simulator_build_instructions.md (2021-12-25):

# threeboard simulator build instructions

1. Complete all of the steps in the [firmware build instructions](firmware_build_instructions.md) guide if you haven't already.
2. Install additional simulator dependencies:
   ```
   sudo apt-get install libelf-dev libncursesw5-dev freeglut3-dev
   ```
3. Clone the custom simavr fork, which includes additional threeboard compatibility functionality:
   ```
   git clone git@github.com:taylorconor/simavr.git
   ```
4. Check out the threeboard compatibility branch:
   ```
   cd simavr && git checkout threeboard_compat
   ```
5. Install simavr:
   ``` 
   sudo make install RELEASE=1
   ```
6. Navigate to the `threeboard/firmware` directory of your threeboard project clone.
7. Run the threeboard simulator:
   ```
   bazel run //simulator:simulator
   ```

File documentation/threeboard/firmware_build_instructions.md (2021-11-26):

# threeboard firmware build instructions

1. Install Bazel using the instructions for your OS/distro as described in the [Bazel installation guide](https://docs.bazel.build/versions/4.0.0/install.html).
2. Install the packages that the threeboard firmware depends on:  
   ```
   sudo apt-get install build-essential gcc-avr avr-libc git
   ```
3. If you don't already have a C++17 compatible compiler, install GCC version 8:  
   ```
   sudo apt-get install g++8
   ``` 
3. Clone the threeboard git repository:  
   ```
   git clone git@github.com:taylorconor/threeboard.git
   ```
4. Navigate to the Bazel workspace root of the threeboard project:  
   ```
   cd threeboard/firmware
   ``` 
5. Compile the threeboard firmware into a `.hex` file that can be flashed to hardware:  
   ```
   bazel build //src:threeboard_hex
   ```  
   The firmware hex file will be written to `threeboard/firmware/bazel-bin/src/threeboard_hex.hex`.

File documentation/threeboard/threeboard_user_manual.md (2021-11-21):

# threeboard user manual

This document explains all of the user functionality of the threeboard. See the [examples](#examples) section at the bottom of this document for usage examples.

## Overview
The threeboard uses three keys to select keycodes to send over USB, and also provides three programmable layers to store and retrieve key combinations. The state of the keyboard is visualised using the 22 onboard LED lights, and can only be modified using the three keys. The image below highlights the different features of the device:
<p align="center">
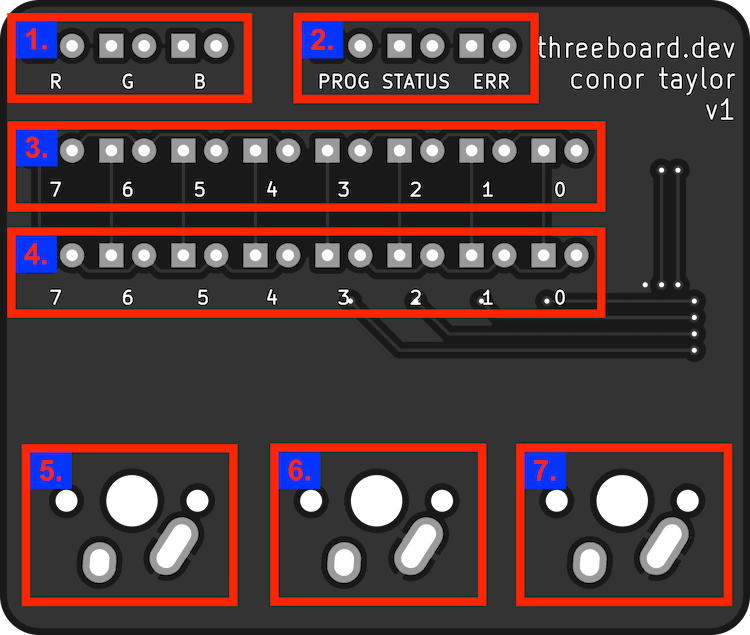
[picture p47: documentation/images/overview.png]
  
</p>

1. 3 LEDs indicating the currently selected keyboard layer (R, G and B).
2. 3 status LEDs for indicating operating status of the threeboard (PROG, STATUS and ERR)
3. Bank0, a binary byte display of 8 LEDs. Used for displaying layer-specific information (e.g. displaying the USB keycode)
4. Bank1, another binary byte display with 8 LEDs. Used for displaying a different byte of layer-specific information (e.g. displaying the USB modifier code).
5. Mechanical key X.
6. Mechanical key Y.
7. Mechanical key Z.

## Layers and modes

The user-facing functionality is split into layers. A layer changes the functionality of each key on the threeboard, similar to a shift or function key on a traditional keyboard. The threeboard has four different layers: a default `DFLT` layer, and three programmable layers:

- `DFLT`: The default layer of the threeboard. This is the layer that the threeboard starts in when it boots. No layer LEDs are lit in this layer. This is a single character input layer, where characters and modifiers in this layer are identified by their USB key codes.
- `R`: The character reprogramming layer of the threeboard. This layer allows users to reassign a keycode to a character. This allows faster input of common characters.
- `G`: The word shortcut layer. This layer allows users to program frequently used words into the threeboard. These words can then be accessed and sent over USB.
- `B`: The blob shortcut layer. This allows users to program arbitrary text blobs (including mod codes), and access them later.

The three programmable layers each have two modes: `DFLT` and `PROG`:

- `DFLT`: This is the default mode of the programmable layers. It is used to retrieve shortcuts that were programmed in the `PROG` mode, and send them over USB.
- `PROG`: This mode is used for programming the shortcuts used in the DFLT mode of the layer.

Each layer and mode defines its own actions based on the input keypresses. Since there are many possible states, the full mapping of layers, modes, key combinations and actions is quite large, and is defined in the threeboard [usage table](#usage-table) section below. However most layers share some common actions for some keypresses:

- Key `X`: Increment bank 0.
- Key `Y`: Increment bank 1.
- Key `Z`: Send keypress(es) over USB (in `DFLT` mode), or store shortcut in `PROG` mode.
- Key combo `X`+`Z` (a.k.a. `XZ`): Clear bank 0.
- Key combo `YZ`: Clear bank 1.
- Key combo `XYZ`: Go to next layer (when in `DFLT` mode), or exit `PROG` mode otherwise.
- Key combo `XY`: Enter `PROG` mode (when in `DFLT` mode).

Brief examples of scenarios in each layer and mode configuration are visualised below:

### `DFLT` layer
<p align="center">
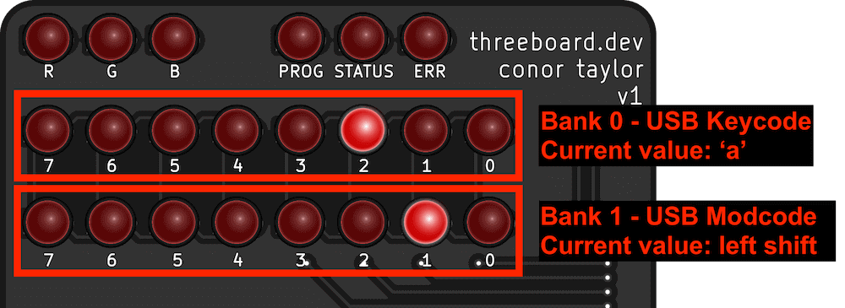
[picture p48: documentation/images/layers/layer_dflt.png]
  
</p>
In the `DFLT` layer, the byte in bank 0 represents the raw USB keycode value to be sent to the host computer, and bank 1 represents the USB modifier code. This layer has no `PROG` mode.

### Layer `R` - The character shortcut layer
<p align="center">
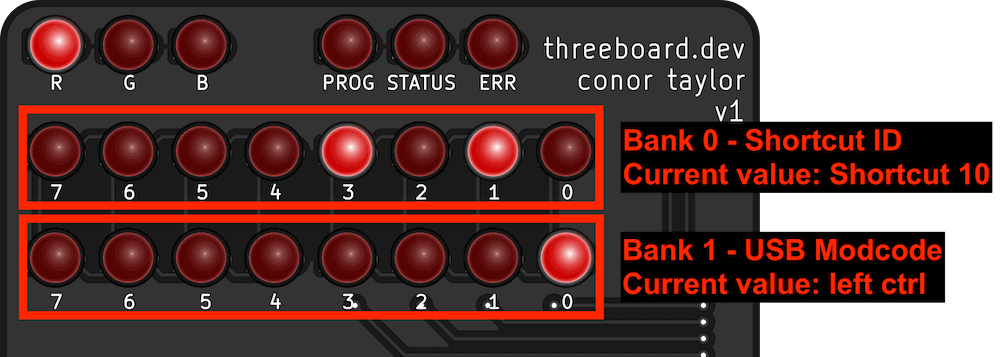
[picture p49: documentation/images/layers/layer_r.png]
  
</p>
Layer `R` is used for character reprogramming, which allows re-assigning a value of bank 0 to a different USB keycode than it represents in the `DFLT` layer. When this layer is being used in `DFLT` mode, bank 0 is used to identify the shortcut ID, and bank 1 is used as it is in the `DFLT` layer, to specify the USB modifier code.

<p align="center">
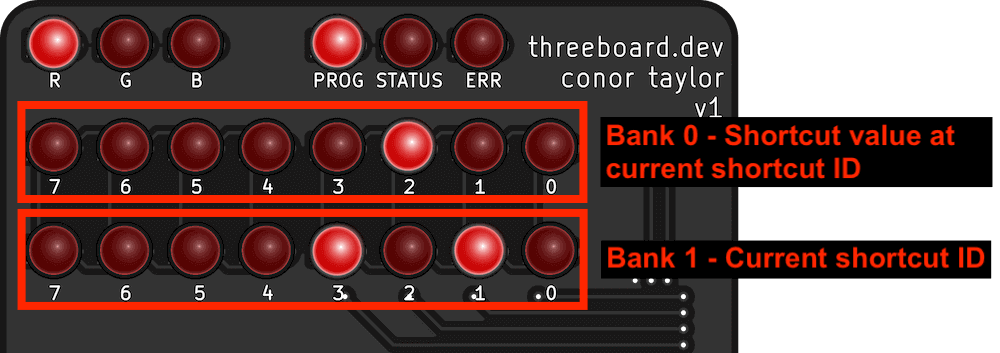
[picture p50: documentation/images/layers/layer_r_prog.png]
  
</p>
In `PROG` mode, the current shortcut value at the specified shortcut ID is displayed in bank 0. The shortcut ID is instead displayed in bank 0.

### Layer `G` - The word shortcut layer
<p align="center">
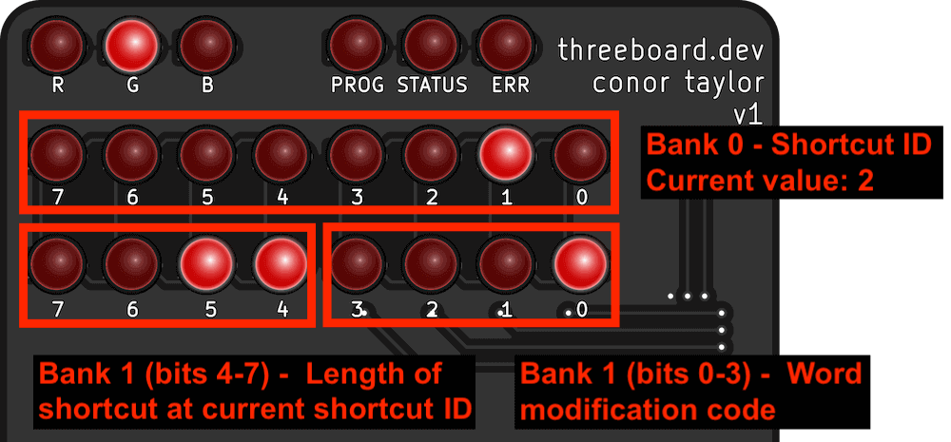
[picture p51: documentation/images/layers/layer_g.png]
  
</p>
Layer `G` is used for word shortcut programming. Words up to 15 characters long can be stored per shortcut ID, and modifier codes are used to apply USB modifier codes to the word shortcut (such as capitalizing the first letter). In `DFLT` mode, bank 1 is split into two 4-bit indicators to display two different values; the 4 high bits are used to display the length of the current shortcut, and the 4 low bits display the word modification code. Word modification codes cause the following modifications:

- Code 0: Word is sent in lowercase.
- Code 1: Word is sent in uppercase.
- Code 2: The first letter of the word is capitalized.
- Code 3: A period (`.`) is appended to the end of the word.
- Code 4: A comma (`,`) is appended to the end of the word.
- Code 5: A hyphen (`-`) is appended to the end of the word.
- Codes 6-15: Reserved. The word is sent in lowercase.

<p align="center">
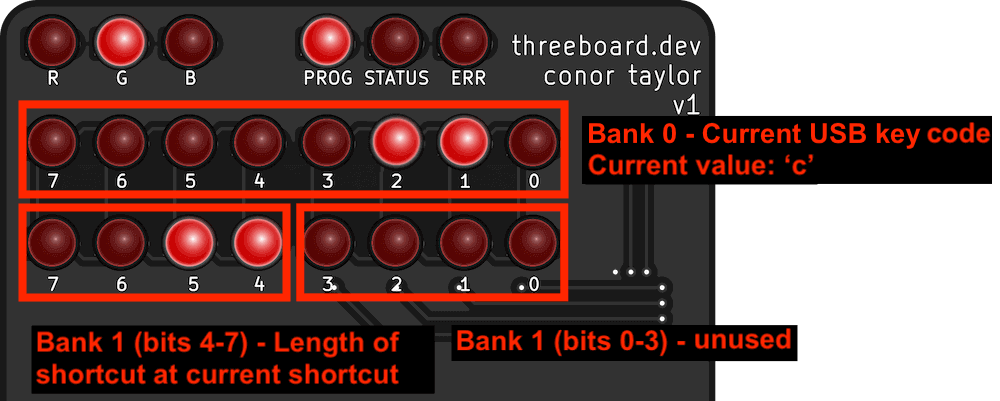
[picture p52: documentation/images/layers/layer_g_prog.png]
  
</p>
In `PROG` mode, the current USB keycode to be appended to the word shortcut is displayed in bank 0. The 4 high bits of bank 1 continues to display the length of the word shortcut, but the 4 low bits are unused and always set to 0.

### Layer `B` - The blob shortcut layer
<p align="center">
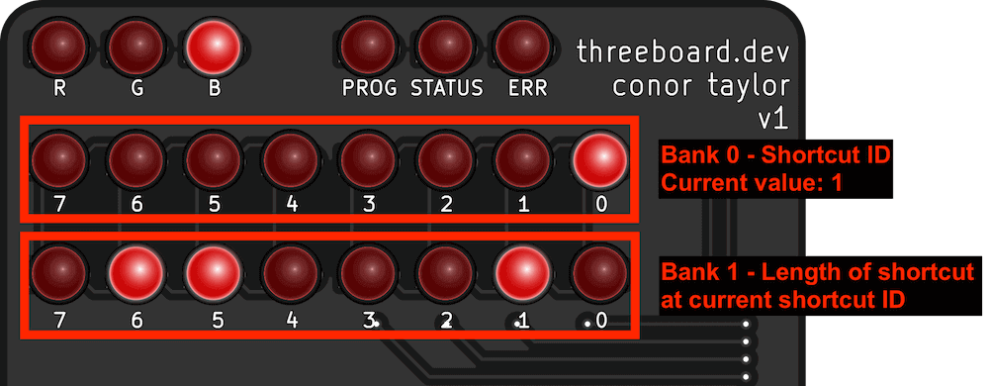
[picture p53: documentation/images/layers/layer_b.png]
  
</p>
Layer `B` allows for freeform blob shortcut programming. Blobs of up to 255 keycode and modcode pairs can be stored. In `DFLT` mode, bank 0 displays the current shortcut ID, and bank 1 displays the length of the shortcut stored there.

<p align="center">
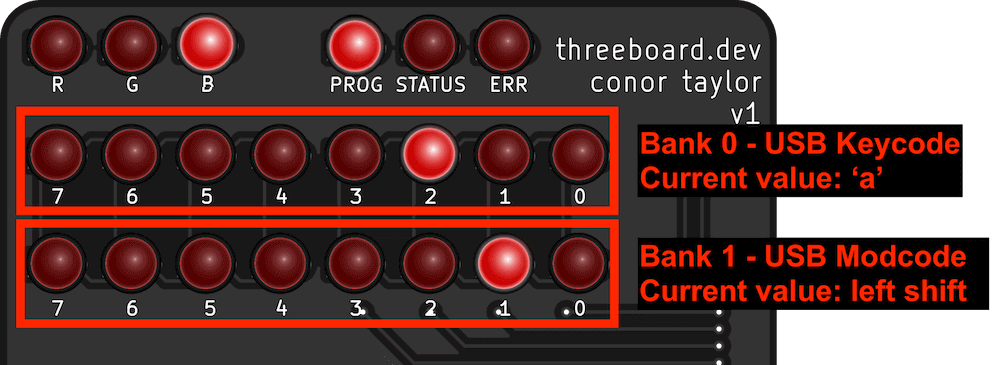
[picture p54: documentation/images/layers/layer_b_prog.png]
  
</p>
In `PROG` mode, bank 0 displays the USB keycode being programmed, and bank 1 displays the modcode.

## Usage table

This table defines the full list of key combinations and their associated actions on each layer:



## Examples

This section contains a list of verbose examples to help understand how the key combinations can be used in practice.

### `DFLT` layer
Typing `Hello` from the `DFLT` layer:

1. Enter the `DFLT` layer. This is the layer the threeboard boots into, identified by none of the `R`, `G` or `B` LEDs being lit.
2. Select the `h` keycode in Bank 0 by pressing key `X` 11 times.
3. Set the `shift` modcode (to capitalise `h`) in Bank 1 by pressing key `Y` twice.
4. Send `H` to the computer over USB by pressing `Z`.
5. Reset Bank 0 by pressing `XZ`, and reset Bank 1 by pressing `YZ`.
6. Select `e` in Bank 0 by pressing `X` 8 times, then send it by pressing `Z`.
7. Select `l` in Bank 0 by pressing `X` an additional 7 times.
8. Send `l` over USB twice by pressing `Z` twice.
9. Select `o` by pressing `X` another 3 times, and send it by pressing `Z`.

### Layer `R`
Programming `a`, `b`, and `c` into shortcuts 0, 1 and 2 of layer `R`:

1. Enter layer `R` by pressing `XYZ` from the `DFLT` layer. The `R` LED should now be lit.
2. Enter `PROG` mode by pressing `XY`, the `PROG` LED should light up.
3. Set shortcut 0 to `a` by pressing `X` 4 times.
4. Switch to shortcut 1 by pressing `Y`.
5. Set shortcut 1 to `b` by pressing `X` 5 times.
6. Switch to shortcut 2 by pressing `Y`.
7. Set shortcut 2 to `c` by pressing `X` 6 times.

### Layer `G`
Programming `hello` into shortcut 0 of layer `G`:

1. Enter layer `G` by pressing `XYZ` twice from the `DFLT` layer. The `G` LED should be lit now.
2. Enter `PROG` mode by pressing `XY`.
3. Select the `h` keycode in Bank 0 by pressing key `X` 11 times.
4. Append `h` to shortcut 0 by pressing `Z`.
5. Clear Bank 0 by pressing `XZ`.
6. Select `e` in Bank 0 by pressing `X` 8 times, and append it to shortcut 0 by pressing `Z`.
7. Press `X` another 7 times to select `l`, and append it twice to shortcut 0 by pressing `Z` twice.
8. Select `o` by pressing `X` an additional 3 times, and append it by pressing `Z`.

Send `Hello` over USB from stored `hello` in shortcut 0:

1. Enter layer `G`, shortcut 0.
2. Select the 'uppercase' modcode, indicated by a value of 1 in Bank 1, by pressing `Y`.
3. Press `Z` to send `Hello` (with first letter capitalised) over USB.

### Layer `B`
Programming `Hi!` into shortcut 0 of layer `B`:

1. Enter layer `B` by pressing `XYZ` three times from the `DFLT` layer, lighting the `B` LED.
2. Enter `PROG` mode by pressing `XY`.
3. Append `H` to shortcut 0 by setting Bank 0 to `h` (pressing `X` 11 times) and Bank 1 to shift (pressing `Y` twice), and append by pressing `Z`.
4. Clear Bank 1 by pressing `YZ`.
5. Select `i` in Bank 0 by pressing `X`, and append it to shortcut 0 by pressing `Z`.
6. Select `1` in Bank 0 by pressing `X` another 18 times.
7. Set Bank 1 to shift (pressing `Y` twice), and append by pressing `Z`.

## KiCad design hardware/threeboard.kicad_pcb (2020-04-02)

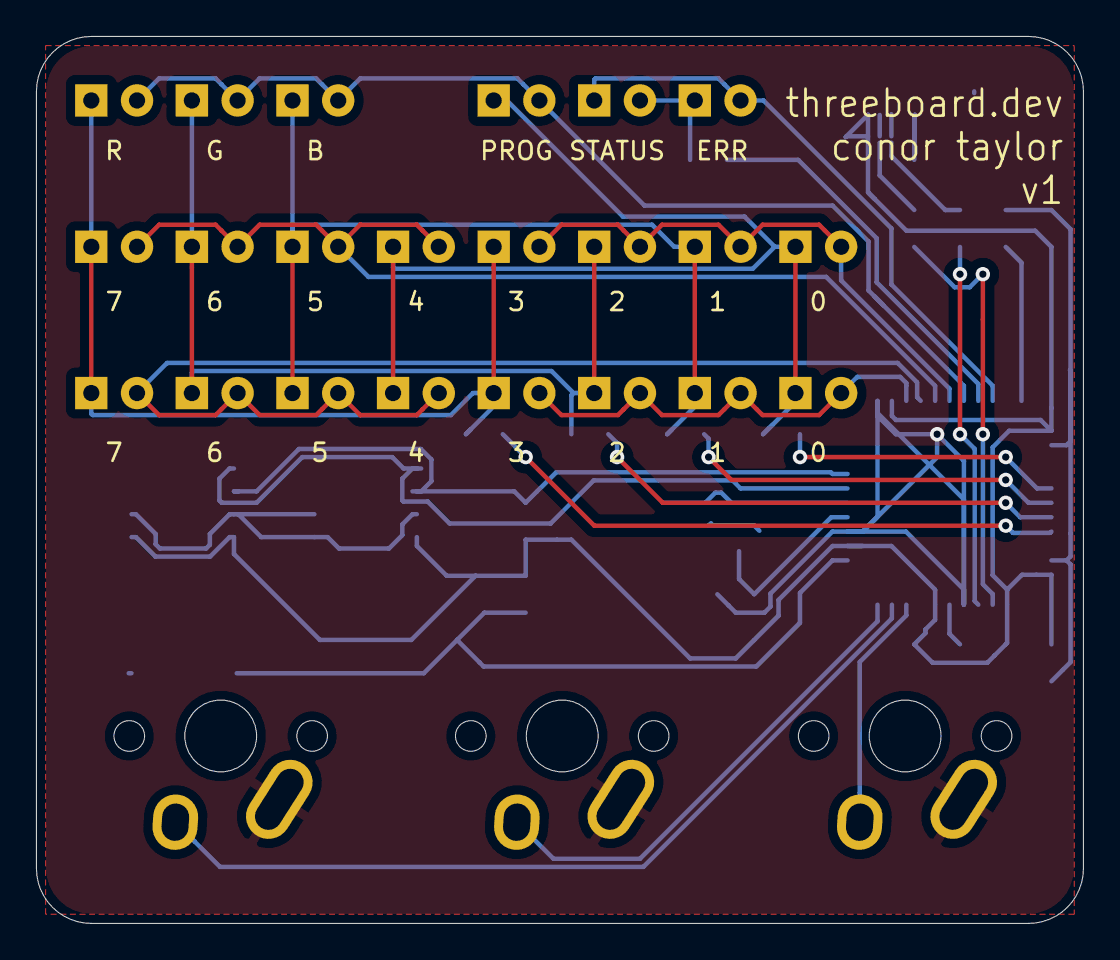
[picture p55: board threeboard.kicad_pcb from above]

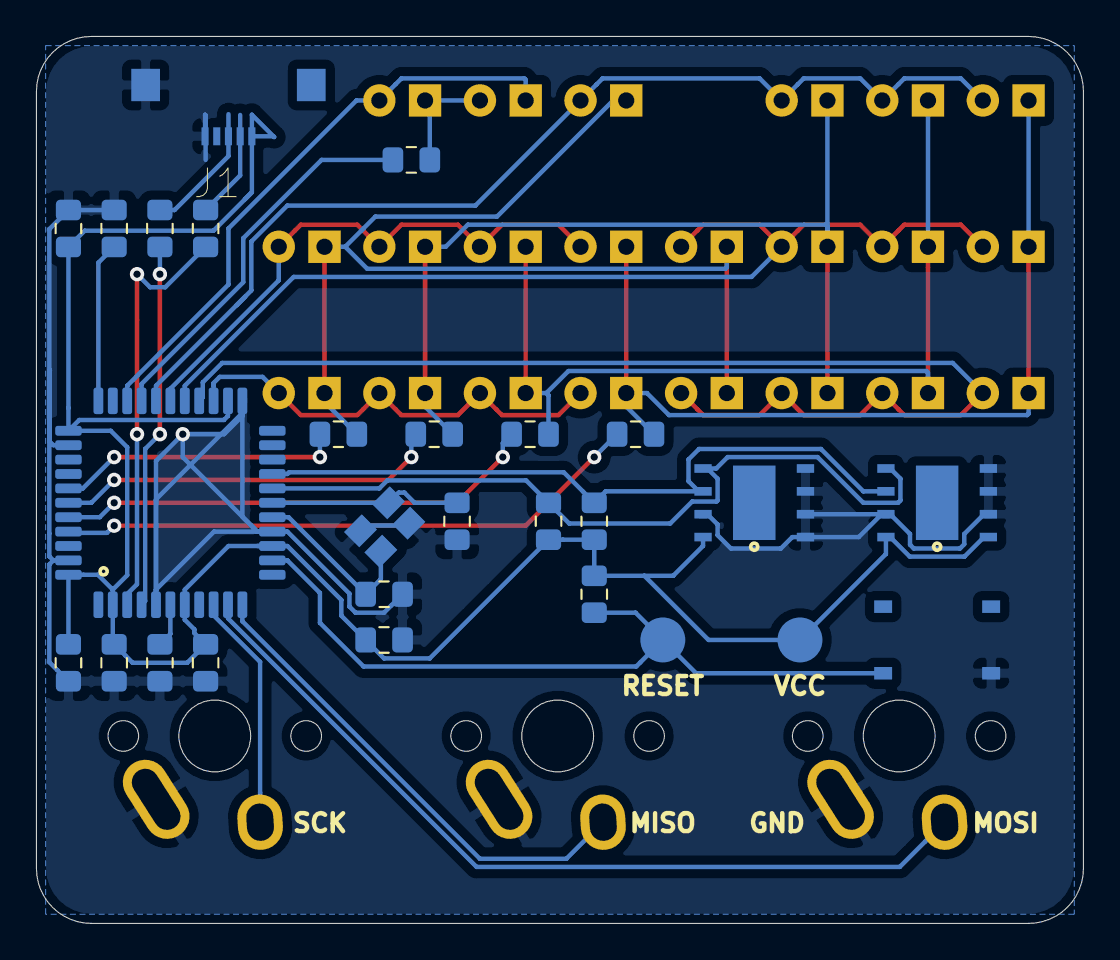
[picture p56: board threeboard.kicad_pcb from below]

Board: 2 copper layers, 58.2 x 49.3 mm, 50 parts (25 on the bottom side), 32 nets.

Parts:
0, 0#2, 1, 1#2, 2, 2#2, 3, 3#2, 4, 4#2, 5, 5#2, 6, 6#2, 7, 7#2: LED; LED_D3.0mm
B: LED; LED_D3.0mm
C1, C2: 22p; C_0805_2012Metric_Pad1.15x1.40mm_HandSolder
C3, C4, C5, C6: 0.1u; C_0805_2012Metric_Pad1.15x1.40mm_HandSolder
C7: 4.7u; C_0805_2012Metric_Pad1.15x1.40mm_HandSolder
C8: 1u; C_0805_2012Metric_Pad1.15x1.40mm_HandSolder
ERR: LED; LED_D3.0mm
G: LED; LED_D3.0mm
J1: USB_mini_micro_B; GCT_USB3070-XX-X_REVE
K1, K2, K3: KEYSW; Mx_Alps_100
PROG: LED; LED_D3.0mm
R: LED; LED_D3.0mm
R1, R2: 10k; R_0805_2012Metric_Pad1.15x1.40mm_HandSolder
R3, R4: 22; R_0805_2012Metric_Pad1.15x1.40mm_HandSolder
R5, R6, R7, R8, R9: 220; R_0805_2012Metric_Pad1.15x1.40mm_HandSolder
R10, R11: 4.7k; R_0805_2012Metric_Pad1.15x1.40mm_HandSolder
STATUS: LED; LED_D3.0mm
SW1: SW_PUSH; SW_PTS526_SK08_SMTR2_LFS
U1: ATMEGA32U4; LQFP-44_10x10mm_P0.8mm
U2, U3: 24LC512; DFN500X600X95-9N
X1: XTAL_GND; crystal_FA238-TSX3225

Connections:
/col0: R5.2, U1.41
/col1: R6.2, U1.40
/col2: R7.2, U1.39
/col3: R8.2, U1.38
/eeprom_scl: R11.2, U1.19, U2.6, U3.6
/eeprom_sda: R10.2, U1.18, U2.5, U3.5
/row0: 4.2, 5.2, 6.2, 7.2, U1.27
/row1: 0.2, 1.2, 2.2, 3.2, U1.28
/row2: 4#2.2, 5#2.2, 6#2.2, 7#2.2, U1.26
/row3: 0#2.2, 1#2.2, 2#2.2, 3#2.2, U1.25
/row4: B.2, G.2, PROG.2, R.2, U1.29
/status0: R9.2, U1.30
/status1: ERR.2, STATUS.1, U1.31
/switch1: K1.2, U1.10
/switch2: K2.2, U1.11
/switch3: K3.2, U1.9
GND: C1.2, C2.2, C3.2, C4.2, C5.2, C6.2, C7.2, C8.2, J1.5, J1.6, K1.1, K2.1, K3.1, R2.1, SW1.1, U1.5, U1.15, U1.23, U1.35, U1.43, U2.2, U2.3, U2.4, U2.7, U3.1, U3.2, U3.3, U3.4, U3.7, X1.3
unnamed: C1.1, U1.16, X1.1
unnamed: C2.1, U1.17, X1.2
unnamed: C8.1, U1.6
unnamed: 3.1, 3#2.1, 7.1, 7#2.1, R.1, R5.1
unnamed: 2.1, 2#2.1, 6.1, 6#2.1, G.1, R6.1
unnamed: 1.1, 1#2.1, 5.1, 5#2.1, B.1, R7.1
unnamed: 0.1, 0#2.1, 4.1, 4#2.1, PROG.1, R8.1
unnamed: ERR.1, R9.1, STATUS.2
unnamed: J1.2, R3.2
unnamed: J1.3, R4.2
unnamed: R1.2, SW1.2, U1.13
unnamed: R2.2, U1.33
unnamed: R3.1, U1.3
unnamed: R4.1, U1.4
VCC: C3.1, C4.1, C5.1, C6.1, C7.1, J1.1, R1.1, R10.1, R11.1, U1.2, U1.7, U1.14, U1.24, U1.34, U1.44, U2.1, U2.8, U3.8

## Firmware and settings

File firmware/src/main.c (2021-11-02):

#include "src/bootstrap.h"

// When building the ELF binary for use in the simavr simulator, the simulator
// needs some extra information about the host MCU added to the ELF file, which
// is done using this header.
#ifdef THREEBOARD_SIM
#include "native/mcu.h"

// TODO: make this include relative to simavr, not external/third_party. Right
// now it's like this because of limitations in simavr_avr_hdrs which I don't
// have the time / the will to fix at the moment.
#include "external/third_party/local/include/simavr/avr/avr_mcu_section.h"
#ifdef F_CPU_OVERRIDE
AVR_MCU(F_CPU_OVERRIDE, MCU_NAME);
#else
AVR_MCU(F_CPU, MCU_NAME);
#endif
#endif

// This main function is just a C wrapper around the C++ `bootstrap.cpp`. The
// reason we do this is to enable the raw ELF file produced by building this
// main file to be testable in the simavr simulator. The simulator relies on
// linking in a section to the ELF file describing the MCU settings (name and
// frequency) defined by AVR_MCU above. This macro produces code that is not
// syntactically compatible with C++.
int main() {
  // Call into an `extern "C"` function in C++ to run the threeboard firmware.
  RunThreeboardEventLoop();
  return 0;
}

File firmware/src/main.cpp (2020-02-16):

#include "src/native/i2c.h"
#include "src/native/native_impl.h"
#include "src/threeboard.h"
#include "src/usb/usb_impl.h"

using namespace threeboard;

int main() {
  // The native interface is used to abstract away all "native" code (e.g.
  // interrupt setup code, setting various pin port values). This is the only
  // place that NativeImpl is injected. To keep all other components testable,
  // they all use the Native interface.
  auto native_impl = native::NativeImpl::Get();
  native_impl->EnableInterrupts();

  auto usb_impl = usb::UsbImpl(native_impl);
  auto i2c = native::I2C();

  i2c.Init();
  uint8_t data = 1;
  i2c.SequentialRead(0, &data, 1);

  // Set up the remaining objects to inject into the Threeboard instance. These
  // could be constructed within the instance, but injecting them makes testing
  // easier since we can inject mocks for tets.
  EventHandler event_handler(native_impl);
  LedController led_controller(native_impl);
  KeyController key_controller(native_impl, &event_handler);
  led_controller.SetBank0(data);

  Threeboard threeboard(native_impl, &usb_impl, &event_handler, &led_controller,
                        &key_controller);

  // Run the firmware event loop. This will run forever.
  threeboard.Run();
}

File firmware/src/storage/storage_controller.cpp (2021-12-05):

#include "storage_controller.h"

#include "src/logging.h"
#include "src/native/mcu.h"
#include "src/storage/internal/i2c_eeprom.h"
#include "src/storage/internal/internal_eeprom.h"
#include "src/util/util.h"

namespace threeboard {
namespace storage {
namespace {

// The internal EEPROM contains the character shortcut storage, as well as
// metadata storage for the other layers (specifically, the length of each word
// or blob shortcut for layers G and B). It is laid out as follows:
// |--------------------- internal EEPROM size = 1024 B -----------------------|
// |- char shortcuts -| |- layer G lengths -| |- layer B lengths -| |- unused -|
// |------ 256 B -----| |------ 256 B ------| |------ 248 B ------| |-- 264 B -|
//                      ^                     ^
//                    0x100                 0x200
//
// External EEPROMs (EEPROM_0 and EEPROM_1) are two identical external 512 Kbit
// (65,536 byte) i2c storage devices. EEPROM_0 stores all the layer G shortcuts,
// and the first 120 layer B shortcuts. EEPROM_1 stores the remainder of the
// layer B shortcuts. They're arranged as follows:
// |------------------------- EEPROM_0 size = 65,536 B ------------------------|
// |- layer G shortcuts -| |------------ layer B shortcuts [0-119] ------------|
// |------ 4,096 B ------| |--------------------- 61,440 B --------------------|
//                         ^
//                      0x1000
//
// |------------------------- EEPROM_1 size = 65,536 B ------------------------|
// |----------------------- layer B shortcuts [120 - 247] ---------------------|

constexpr uint16_t kInternalEepromLayerGLengthStart = 0x100;
constexpr uint16_t kInternalEepromLayerBLengthStart = 0x200;
constexpr uint16_t kEeprom0LayerBStart = 0x1000;
constexpr uint8_t kLayerBMaxIndex = 247;
constexpr uint8_t kEeprom1LayerBStartShortcutId = 120;

}  // namespace

StorageController::StorageController(native::Native *native,
                                     usb::UsbController *usb_controller)
    : usb_controller_(usb_controller) {
  // Set the TWI prescaler to 0.
  native->SetTWSR(native->GetTWSR() & ~3);
  // Set the SCL clock frequency for the TWI interface to 100kHz.
  native->SetTWBR(((F_CPU / 100000) - 16) / 2);

  // Enable the MCUs TWI module before constructing the I2cEeprom instances, so
  // they don't need to configure this themselves and duplicate the logic.
  native->SetTWCR(1 << native::TWEN);

  static InternalEeprom internal_eeprom(native);
  static I2cEeprom external_eeprom_0(native, I2cEeprom::EEPROM_0);
  static I2cEeprom external_eeprom_1(native, I2cEeprom::EEPROM_1);
  internal_eeprom_ = &internal_eeprom;
  external_eeprom_0_ = &external_eeprom_0;
  external_eeprom_1_ = &external_eeprom_1;
}

bool StorageController::SetCharacterShortcut(uint8_t index, uint8_t character) {
  return internal_eeprom_->WriteByte(index, character);
}

bool StorageController::GetCharacterShortcut(uint8_t index, uint8_t *output) {
  return internal_eeprom_->ReadByte(index, output);
}

bool StorageController::AppendToWordShortcut(uint8_t index, uint8_t character) {
  uint8_t length;
  RETURN_IF_ERROR(GetWordShortcutLength(index, &length));
  // If this shortcut slot is already full (15 characters) then we need to
  // propagate an error.
  if (length == 15) {
    return false;
  }
  RETURN_IF_ERROR(
      external_eeprom_0_->WriteByte((index * 16) + length, character));
  return internal_eeprom_->WriteByte(kInternalEepromLayerGLengthStart + index,
                                     length + 1);
}

bool StorageController::ClearWordShortcut(uint8_t index) {
  return internal_eeprom_->WriteByte(kInternalEepromLayerGLengthStart + index,
                                     0);
}

bool StorageController::GetWordShortcutLength(uint8_t index, uint8_t *output) {
  return internal_eeprom_->ReadByte(kInternalEepromLayerGLengthStart + index,
                                    output);
}

bool StorageController::SendWordShortcut(uint8_t index, uint8_t raw_mod_code) {
  auto word_mod_code = (WordModCode)raw_mod_code;
  uint8_t length;
  RETURN_IF_ERROR(GetWordShortcutLength(index, &length));
  // If this shortcut slot is empty then we should propagate an error instead of
  // doing nothing.
  if (length == 0) {
    return false;
  }
  for (int i = 0; i < length; ++i) {
    uint8_t character;
    RETURN_IF_ERROR(external_eeprom_0_->ReadByte((index * 16) + i, &character));
    if (word_mod_code == WordModCode::UPPERCASE ||
        (word_mod_code == WordModCode::CAPITALISE && i == 0)) {
      RETURN_IF_ERROR(usb_controller_->SendKeypress(character, (1 << 1)));
    } else {
      if (i == length - 1) {
        uint8_t append = 0;
        if (word_mod_code == WordModCode::APPEND_PERIOD) {
          append = 0x37;
        } else if (word_mod_code == WordModCode::APPEND_COMMA) {
          append = 0x36;
        } else if (word_mod_code == WordModCode::APPEND_HYPHEN) {
          append = 0x2d;
        }
        if (append > 0) {
          RETURN_IF_ERROR(usb_controller_->SendKeypress(character, 0));
          character = append;
        }
      }
      RETURN_IF_ERROR(usb_controller_->SendKeypress(character, 0));
    }
  }
  return true;
}

bool StorageController::AppendToBlobShortcut(uint8_t index, uint8_t character,
                                             uint8_t modcode) {
  if (index > kLayerBMaxIndex) {
    return false;
  }
  uint8_t length;
  RETURN_IF_ERROR(GetBlobShortcutLength(index, &length));
  if (length == 255) {
    return false;
  }
  if (index >= kEeprom1LayerBStartShortcutId) {
    uint16_t eeprom_idx =
        ((index - kEeprom1LayerBStartShortcutId) * 512) + (length * 2);
    RETURN_IF_ERROR(external_eeprom_1_->WriteByte(eeprom_idx, character));
    RETURN_IF_ERROR(external_eeprom_1_->WriteByte(eeprom_idx + 1, modcode));
  } else {
    uint16_t eeprom_idx = kEeprom0LayerBStart + (index * 512) + (length * 2);
    RETURN_IF_ERROR(external_eeprom_0_->WriteByte(eeprom_idx, character));
    RETURN_IF_ERROR(external_eeprom_0_->WriteByte(eeprom_idx + 1, modcode));
  }
  return internal_eeprom_->WriteByte(kInternalEepromLayerBLengthStart + index,
                                     length + 1);
}

bool StorageController::ClearBlobShortcut(uint8_t index) {
  if (index > kLayerBMaxIndex) {
    return false;
  }
  return internal_eeprom_->WriteByte(kInternalEepromLayerBLengthStart + index,
                                     0);
}

bool StorageController::GetBlobShortcutLength(uint8_t index, uint8_t *output) {
  if (index > kLayerBMaxIndex) {
    return false;
  }
  return internal_eeprom_->ReadByte(kInternalEepromLayerBLengthStart + index,
                                    output);
}
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

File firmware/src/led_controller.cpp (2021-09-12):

#include "src/led_controller.h"

namespace threeboard {

/**
   Pin mappings:
   ERR (status1) - 31 - PC6
   STATUS (status0) - 30 - PB6
   row0 - 27 - PD7
   row1 - 28 - PB4
   row2 - 26 - PD6
   row3 - 25 - PD4
   row4 - 29 - PB5
   col0 - 41 - PF0
   col1 - 40 - PF1
   col2 - 39 - PF4
   col3 - 38 - PF5
 */

LedController::LedController(native::Native *native) : native_(native) {
  // Specify which pins will be used by this controller.
  native_->EnableDDRB(0b01110000);
  native_->EnableDDRC(0b01000000);
  native_->EnableDDRD(0b11010000);
  native_->EnableDDRF(0b00110011);
}

void LedController::ScanNextLine() {
  // The scan line identifies which row (or "line") of LEDs is next to be
  // refreshed. It is incremented on each scan.
  uint8_t scan_line = next_scan_line_;

  // Split this add and mod into separate operations to avoid a 16-bit divide
  // instruction (which I suspect is a GCC bug).
  next_scan_line_ += 1;
  next_scan_line_ %= 5;

  WriteStateToPins(scan_line);
}

void LedController::UpdateBlinkStatus() {
  // This is called every 5ms. Bit 7 of blink_status_ determines whether an LED
  // in BLINK state should be lit or not.
  blink_status_++;
  if (blink_status_ & (1 << 6)) {
    // Set bit 6 to 0 to reset the counter.
    blink_status_ &= ~(1 << 6);
    // Toggle bit 7, which indicates the blink state (on or off).
    blink_status_ ^= (1 << 7);
  }
}

void LedController::WriteStateToPins(uint8_t row) {
  // ERR and STATUS are a special case since they're mutually exclusive LEDs.
  // They could be set on each scan, but to maintain consistent brightness
  // they have each been assigned their own scan line.
  if (row == 0) {
    ApplyLedState(&native::Native::EnablePORTB, 1 << native::PB6,
                  state_.GetStatus());
  } else if (row == 1) {
    // STATUS must be disabled to allow ERR to be enabled.
    native_->DisablePORTB(1 << native::PB6);
    ApplyLedState(&native::Native::EnablePORTC, 1 << native::PC6,
                  state_.GetErr());
  } else if (row == 2) {
    // Disable both ERR and STATUS until the row scanner starts again.
    native_->DisablePORTC(1 << native::PC6);
  }

  // Clear all row and column pins first. The column pins in PORTF should be
  // considered as active low (they need to be grounded to enable the LED).
  native_->DisablePORTB(0b00110000);
  native_->DisablePORTD(0b11010000);
  native_->EnablePORTF(0b00110011);

  // Enable the correct row pin and column pins for the current row.
  if (row == 0) {
    // row 0: 4 MSB of bank 0
    WriteColumns(state_.GetBank0() >> 4);
    native_->EnablePORTD(1 << native::PD7);
  } else if (row == 1) {
    // row 1: 4 LSB of bank 0
    WriteColumns(state_.GetBank0());
    native_->EnablePORTB(1 << native::PB4);
  } else if (row == 2) {
    // row 2: 4 MSB of bank 1
    WriteColumns(state_.GetBank1() >> 4);
    native_->EnablePORTD(1 << native::PD6);
  } else if (row == 3) {
    // row 3: 4 LSB of bank 1
    WriteColumns(state_.GetBank1());
    native_->EnablePORTD(1 << native::PD4);
  } else if (row == 4) {
    // row 4: R,G,B and PROG. These support full LedState rather than simple
    // booleans.
    ApplyLedState(&native::Native::DisablePORTF, 1 << native::PF0,
                  state_.GetR());
    ApplyLedState(&native::Native::DisablePORTF, 1 << native::PF1,
                  state_.GetG());
    ApplyLedState(&native::Native::DisablePORTF, 1 << native::PF4,
                  state_.GetB());
    ApplyLedState(&native::Native::DisablePORTF, 1 << native::PF5,
                  state_.GetProg());
    native_->EnablePORTB(1 << native::PB5);
  }
}

void LedController::WriteColumns(uint8_t vals) {
  if (vals & 8) {
    native_->DisablePORTF(1 << native::PF0);
  }
  if (vals & 4) {
    native_->DisablePORTF(1 << native::PF1);
  }
  if (vals & 2) {
    native_->DisablePORTF(1 << native::PF4);
  }
  if (vals & 1) {
    native_->DisablePORTF(1 << native::PF5);
  }
}

bool LedController::ShouldEnableBlinkingLed() const {
  return blink_status_ & (1 << 7);
}

void LedController::ApplyLedState(native::PortModFn port_mod_fn, uint8_t val,
                                  LedState::FullState *state) {
  if (state->state == LedState::ON ||
      (state->state == LedState::BLINK && ShouldEnableBlinkingLed())) {
    (native_->*port_mod_fn)(val);
  }
  if (state->state == LedState::PULSE) {
    state->pulse_timer++;
    if (state->pulse_timer == 0) {
      // When the pulse timer has elapsed, return the LED state to OFF.
      state->state = LedState::OFF;
    } else {
      (native_->*port_mod_fn)(val);
    }
  }
}

}  // namespace threeboard

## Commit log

2020-02-11 Add threeboard v1 schema
    [10118194.step, ABS07L.step, B2B-XH-A.step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]
2020-02-11 Add initial i2c implementation
2020-04-02 Add v1 hardware revision with reinforced USB, better LED placement, and dual SMD EEPROM
    [threeboard-B_Cu.gbl, threeboard-B_Mask.gbs, threeboard-B_Paste.gbp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]
2020-05-20 Add initial BUILD wiring for simavr
2020-05-20 Add simulator terminal UI and wire it up to the simulated firmware
2020-05-21 Update key and LED tests for new pin mappings
2020-05-31 Replace busyloop delays by IRQ-interrupted CPU sleeping
    [native_impl.cpp]
2020-08-15 Switch to simavr-provided 32u4 core for the simulator
2020-09-21 Fix simulator destruction and thread joining ordering
2020-10-27 Add initial i2c eeprom code, still needs refactoring into native
2021-01-31 Move I2C config into the simavr interface.
    Also do some initial general refactoring. More to follow.
2021-02-04 Refactor led_controller to remove use of bitset
2021-02-04 Implement LED blinking
2021-02-05 Update led_controller comments
2021-02-14 Move I2C native interactions into Native interface
2021-02-21 Add new hardware documentation images
    [threeboard.sch]
2021-03-04 Add LedState to restrict access to the LedController from the Layers
2021-03-07 Add PCB photo for documentation
2021-03-08 Add ErrorHandlerDelegate and initial error handling
    [native_impl.cpp]
2021-03-11 Correctly verify USB frame number
2021-04-04 Improve LedController test coverage
2021-04-20 Switch ERR and STATUS LED placement to match hardware v1
2021-04-20 Add boot indicator LED sequence
2021-04-20 Update USB Setup timer
2021-04-23 Rewrite i2c stack
2021-04-24 Remove temporary i2c code
2021-04-24 Move i2c class to new storage directory
2021-05-15 Wire up the StorageController into the Threeboard class
2021-05-23 Add initial test case
2021-06-05 Don't cache full character shortcut array in memory
    [storage_controller.cpp]
2021-07-11 Add PULSE mode for LEDs
2021-07-17 Implement word shortcut logic
    [native_impl.cpp]
2021-07-17 Fix GCC issue with LedState bitfield
2021-07-24 Increase prescaler value for timer 3
2021-07-29 Fix log line breaking and simulator log filtering
2021-08-15 Fix off-by-one issue for Layer G size
    [storage_controller.cpp]
2021-08-20 Add blob shortcut interface to StorageController
    [storage_controller.cpp]
2021-09-12 Stability refactoring for the Simulator
    [led_controller.cpp]
2021-10-11 Add support for missing state storage files
    [main.cpp]
2021-10-11 Handle default StateStorage case
2021-10-30 Safer thread joining on unexpected exit
2021-10-30 Add timer interrupt verification integration test
2021-10-31 Fix ERR and STATUS led switch in device_state
2021-11-02 Add operator<< to DeviceState for easy debugging
2021-11-07 Add Framework linking to bazelrc
2021-11-20 Implement blob shortcut logic in the storage layer
    [storage_controller.cpp]
2021-11-24 Compress PCB scan image
2021-11-24 Further compress PCB scan image
2021-12-31 Add small images for USB connectors
